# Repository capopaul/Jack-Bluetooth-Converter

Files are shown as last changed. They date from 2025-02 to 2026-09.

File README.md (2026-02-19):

# Jack <> Bluetooth Converter

Revision 3.1 (Not manufactured yet) :

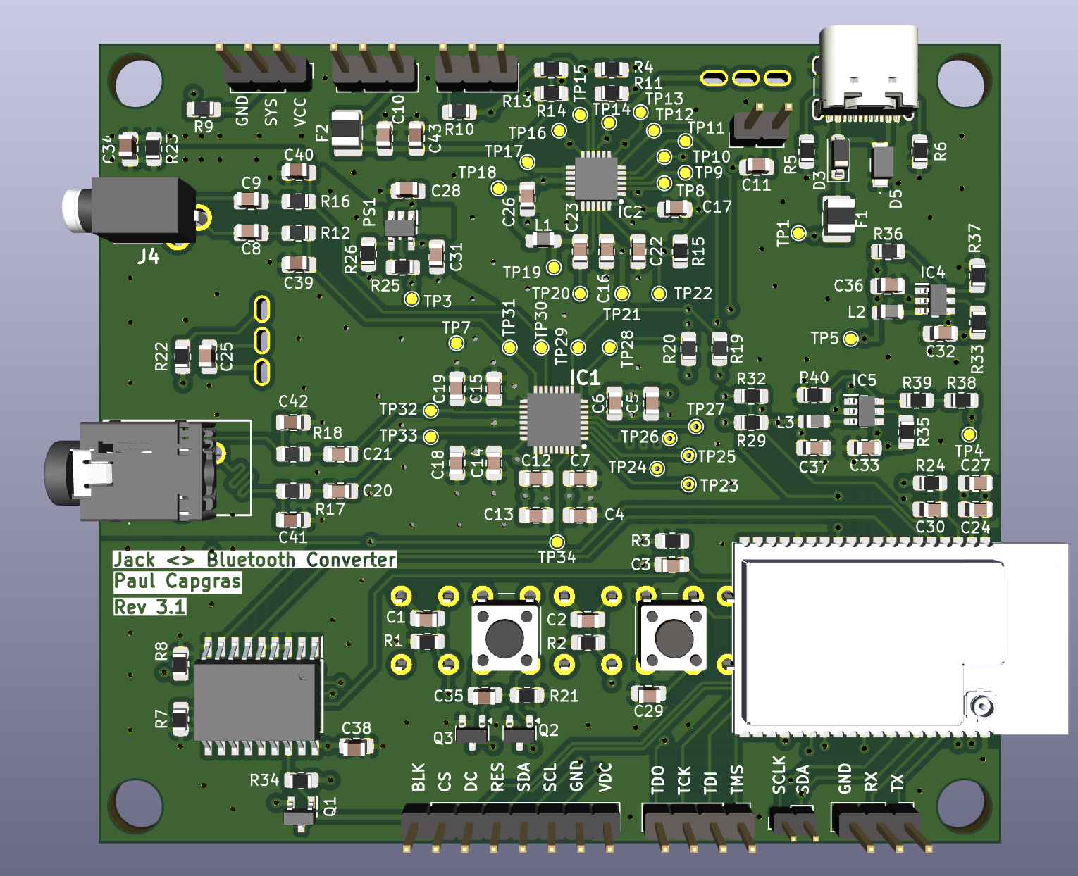
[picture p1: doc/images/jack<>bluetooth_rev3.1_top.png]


Revision 3.0 (Manufactured) :

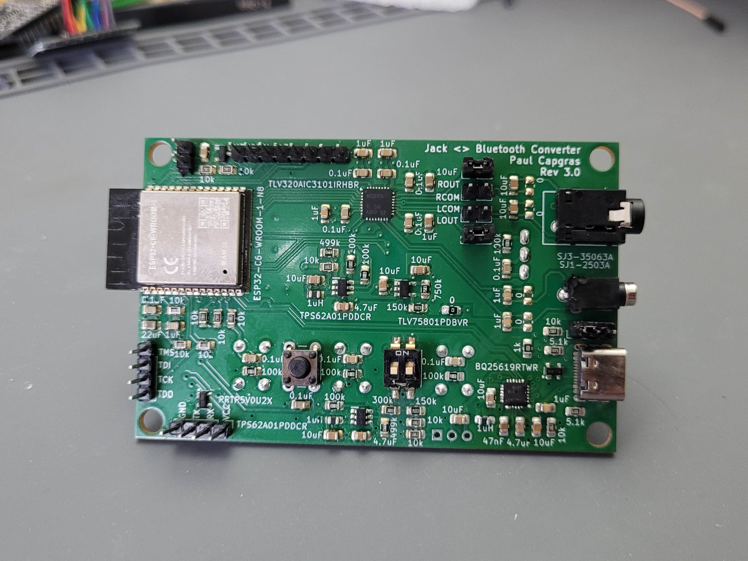
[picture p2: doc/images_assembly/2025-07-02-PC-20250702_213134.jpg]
image pcb


## Table of Content

1. [Features](#1-features)
2. [Design Specificatin and documentation](#2-design-specification-and-documentation)
3. [Repo organization](#3-repo-organization)
4. [Next steps](#4-next-steps)
5. [Revision history](#5-revisions-history)

## 1. Features

This project aims to design a device with the following features:

- Audio input from a 2.5mm audio jack can be sampled and transmitted via Bluetooth to a headphone.
- Digital audio from a smartphone can be received via Bluetooth and converted into analog audio through a 3.5mm audio jack.
- The device can be powered via USB-C or run on battery for up to 3 hours.
- The battery charges when the device is connected to USB-C.
- A screen and buttons allow switching between "Jack to Bluetooth" and "Bluetooth to Jack" modes.
- The screen and buttons enable Bluetooth peripheral selection when the device functions as a Bluetooth central.
- The screen turns off after 1 minute of inactivity to save power.

## 2. Design specification and documentation

Please go to [Jack <> Bluetooth Design Specification](doc/Jack<>Bluetooth-Design-Specification.md) which documents the design choices and provide details on the project.

[Software Readme](software/README.md) contains note taking from the software development (work in progress).

## 3. Repo organization

`./Components` -> components list with libs (not public)

`./doc` -> documentations, specifications and images

`./gerber` -> pcb design files for manufacturing

`./kicad` -> Kicad files

`./software` -> ESP32 C code (work in progress)

## 4. Next steps

- Working on a new revision : Rev3.1 to fix the current hardware limitations

## 5. Revisions history

Please go to [Jack<>Bluetooth-Revision-History](doc/Jack<>Bluetooth-Revision-History.md)

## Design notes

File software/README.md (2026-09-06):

<!-- Author : Paul Capgras -->
<!-- Date   : Jun 14, 2025 -->

# Software Readme

Command order:

- `get_idf`
- `idf.py set-target esp32`
- `idf.py build`
- `idf.py flash monitor`

Then refer to bringup:

## Bringup

- Connect GND
- Connect RX to **TX**
- Connect TX to **RX**

- Send the program through UART
  - thanks to the esp idf platform
  - run `get_idf`
  - esp32 should have been also selected
  - `idf.py build` to build
  - power up the board via usb-c
  - connect the UART device using an usb-c to usb cable.
  - check macos detect the device `ls /dev/cu.*`
  - Push SW 4 (left) down
  - flash the program `idf.py flash monitor`
  - You might need to push reset button (SW 6, right, close to the esp32)
  - to quit monitor terminal run CTRL-] on querty or CTRL+ALT GR+$ on azerty

> Ouput should be:

- 0x00 -> (ESP Master)
- 0x20 -> IO Expander
- 0x18 -> Audio Codec
- 0x6a -> PMIC

## Detect I2C peripherals

- use the i2c_tools from `/home/paul/esp/esp-idf/examples/peripherals/i2c`
- go to the clone directory and run the idf commands.
- i2c detect does not detect anything so far
- connect oled i2c screen for a debug purpose. I might need a breadboard to connect grounds.

## Embedded development

- VS code with esp-idf extension (from Espressif Systems) and C/C++ (from Microsoft).
- Some `#include`might me red, you need to add the esp path to the extension.
- This video explains it at 7min15 : <https://www.youtube.com/watch?v=5IuZ-E8Tmhg&t=5s>
- You can also use `CMD+SHIFT+P`, then click `ESP-IDF: Add VS Code Configuration Folder`.
- You will need to build the project with `idf.py build` and it should solve all the issues

## Development Notes

- [Former Development Notes of Rev3.0](./Development%20Notes%20of%20Rev3.0.md).

### Clocks

The is an issue on my PCB with i2s_mclk. It was supposed to be IO0 and it turns out to be TXD0...

So let's try not to use i2s_mclk and only i2s_bclk.

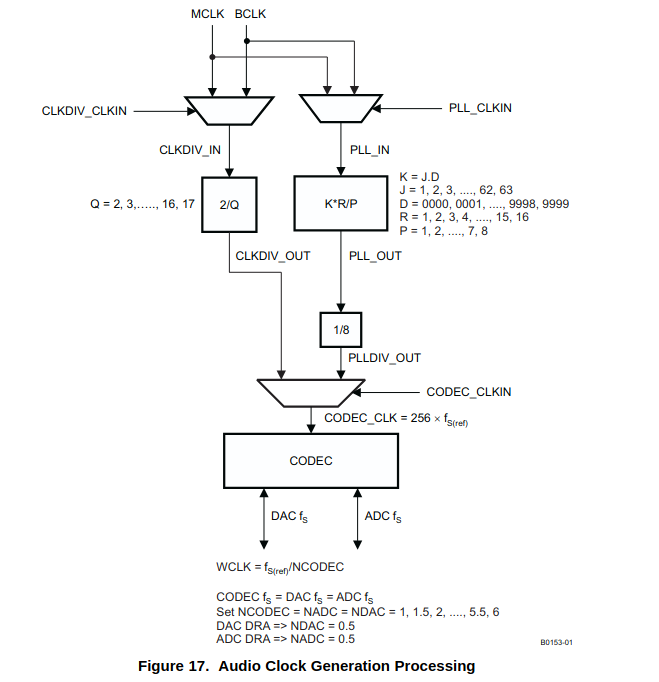
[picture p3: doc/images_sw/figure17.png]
audio codec clocks


The goal is to have : `CODEC_CLK = 256 x fs`.

- `fs = 44,100 Hz`
- So the goal is to have : `CODEC_CLK = 256 x fs = 11.2896 MHz`.
- Right now, `BCLK = 2.822 MHz` with 16 bit stereo but 32 bit slots.
- So in the clock path I choose to use the path on the right, using the audio codec internal PLL.
- `PLLDIV_OUT = BLCK x K x R / (8 x P) = BLCK x (J.D) x R / (8 x P)`
- **Warning** J is the integer portion of K (the numbers to the left of the decimal point), while D is the fractional portion of K.
- `P = 1, R = 1, D = 0, J = 32` should work
- `PLL_CLKIN` needs to be set
- `CODEC_CLKIN` needs to be set

### DAC

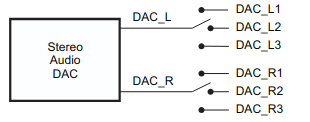
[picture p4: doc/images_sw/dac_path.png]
DAC_path

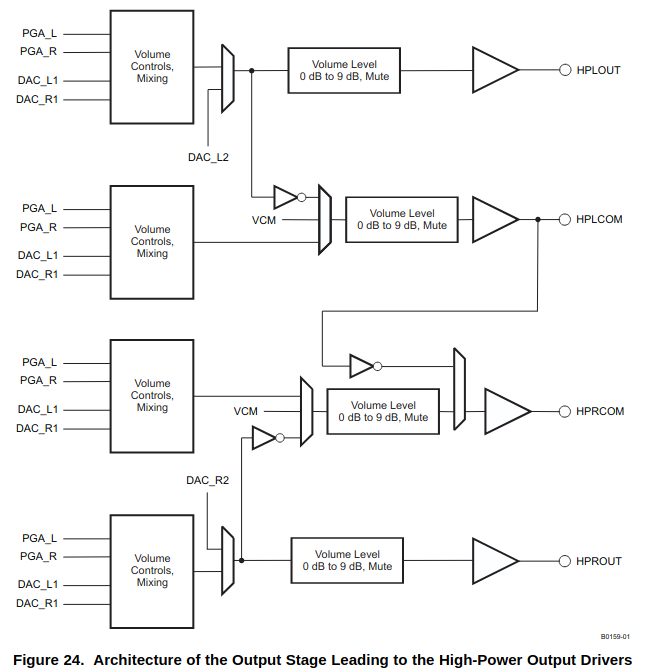
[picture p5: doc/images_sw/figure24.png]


Goal: I want my audio output on HPR/Lout:

- so according to this : I should put my audio on DAC_L2 and DAC_R2 - Register 41.
- Both DAC should be powered up - Register 37.
- Both DAC should be using fs = 44.1KHz and streaming L/R data - Register 7.
- HPLout should be powered up and unmuted - Register 51
- HPRout should be powered up and unmuted - Register 65

Crash when I send the audio. Honnestly without UART working (as it is used to trasnmit MCLK), it is really a mess to debug.

<!-- 
## Oct 12

I am choosing not to use MCLK from the ESP and to generate the clock internally in my audio codec with the internal PLL using the BCLK as a source.

### Clock

Let's configure the PLL.
![figure17](../doc/images_sw/figure17.png)

- CODEC_CLK (BCLK) = KxRxBCLK/(8xP) = 256 fs = KxRxfs/(8x8xP). Which implies that KxR/P = 64x256. So JxDxR/P = 64x256. Let's take P=1, R=2, J=32, D=256
- Enable PLL and set P in register 3
- Set J in register 4
- Set D in register 5 and 6
- Set R in register 11
- CODEC_CLKIN should select PLLDIV_OUT -> Register 101.
- PLLDIV_IN uses BCLK -> Register 102

```c
/*
  * Clock
  */

// Register 3 - PLL Programming Register A
// D7   - 1    - PLL is enabled
// D6-3 - 0000 -
// D2-0 - 001  - P= 1
i2c_set(CODEC_ADDR, 3, 0b10000001);
is_expected(3, i2c_get(CODEC_ADDR, 3), 0b10000001);

// Register 4 - PLL Programming Register B
// D7-2 - 100000 // Set J to 32
// D1-0 - 00
i2c_set(CODEC_ADDR, 4, 0b10000000);
is_expected(4, i2c_get(CODEC_ADDR, 4), 0b10000000);

// Register 5 and 6
// Set D to 100000000 (256)
// MSB D7-0 (reg 5) 00000100
// LSB D7-2 (reg 6) 000000
// D1-0             00
i2c_set(CODEC_ADDR, 5, 0b00000100);
i2c_set(CODEC_ADDR, 6, 0b00000000);
is_expected(5, i2c_get(CODEC_ADDR, 5), 0b00000100);
is_expected(6, i2c_get(CODEC_ADDR, 6), 0b00000000);

// Register 11 - Audio Codec Overflow Flag Register
// D7-4 0
// D3-0 0010 Set R to 0010
i2c_set(CODEC_ADDR, 11, 0b00000010);
is_expected(11, i2c_get(CODEC_ADDR, 11), 0b00000010);

// Register 102 - Clock Generation Control Register
// D7-6 - 0  -
// D5-4 - 10 - PLLCLK_IN uses BCLK
// D3-0 - 0010
// No need to write
i2c_set(CODEC_ADDR, 102, 0b00100010);
is_expected(102, i2c_get(CODEC_ADDR, 102), 0b00100010);

// Register 101 - Clock register
// D7-1 - 0
// D0   - 0 - CODEC_CLKIN uses PLLDIV_OUT
i2c_set(CODEC_ADDR, 101, 0b00000000);
is_expected(101, i2c_get(CODEC_ADDR, 101), 0b00000000);

```

Let's check if the audio is sent successfully through the i2s interface:

I do have my BCLK visible in the oscilloscope. Not the best clean clock I have seen... The frequency is fs(=44.1) * 256 / 8 = 1.41MHz so that is good. It is a free running clock.
![BLCK](../doc/images_sw/bclk_oscilloscope.png)

Ws is also free running.
![WS](../doc/images_sw/ws_oscilloscope.png)

The Dout is also good when sending an audio:
![Dout](../doc/images_sw/dout_oscilloscope.png)

-> Not working. Three possibilities the overshoot are problematic. And/Or the PLL is bad. And/Or the DAC is badly configured.

1. Let's have a faster BCLK with the ESP to enter spec recommendation in the example:

I add a slot of 32 bits instead of 16. This double my BCLK clock.
fs = 44.1kHz
So BCLK = fs*256/4 = 2.822MHz

PLLCLK_IN = 2.822MHz so we have 2MHz < PLLCLK_IN < 20MHz (that is the condition that was not respected before).

fS(ref) = (PLLCLK_IN × K × R)/(2048 × P)

fS(ref) = (256xfS(ref)/4 × K × R)/(2048 × P),

1 = (256 × K × R)/(4x2048 × P),

**P = 1**

KxR = 4x2048/256 = 32

K = J.D => **D=0**, **J = 32**

Other constraint:
80 MHz ≤ (PLLCLK _IN × K × R/P ) ≤ 110 MHz

**R=1**

80MHz < 90MHz < 110MHz - GOOD

Final contraint:

4 ≤ J=16 ≤ 55 - GOOD

``` c
// Register 3 - PLL Programming Register A
// D7   - 1    - PLL is enabled
// D6-3 - 0000 -
// D2-0 - 001  - P= 1
i2c_set(CODEC_ADDR, 3, 0b10000001);
is_expected(3, i2c_get(CODEC_ADDR, 3), 0b10000001);

// Register 4 - PLL Programming Register B
// D7-2 - 10000 // Set J to 32
// D1-0 - 00
i2c_set(CODEC_ADDR, 4, 0b01000000);
is_expected(4, i2c_get(CODEC_ADDR, 4), 0b01000000);

// Register 5 and 6
// Set D to 0
// MSB D7-0 (reg 5) 0
// LSB D7-2 (reg 6) 0
// D1-0             0
// always write both, and in the order reg5 then reg6.
is_expected(5, i2c_get(CODEC_ADDR, 5), 0b00000000);
is_expected(6, i2c_get(CODEC_ADDR, 6), 0b00000000);

// Register 11 - Audio Codec Overflow Flag Register
// D7-4 0
// D3-0 0010 Set R to 0001
i2c_set(CODEC_ADDR, 11, 0b00000010);
is_expected(11, i2c_get(CODEC_ADDR, 11), 0b00000010);

// Register 102 - Clock Generation Control Register
// D7-6 - 0  -
// D5-4 - 10 - PLLCLK_IN uses BCLK
// D3-0 - 0010
// No need to write
i2c_set(CODEC_ADDR, 102, 0b00100010);
is_expected(102, i2c_get(CODEC_ADDR, 102), 0b00100010);

// Register 101 - Clock register
// D7-1 - 0
// D0   - 0 - CODEC_CLKIN uses PLLDIV_OUT
i2c_set(CODEC_ADDR, 101, 0b00000000);
is_expected(101, i2c_get(CODEC_ADDR, 101), 0b00000000);
```

1. Let's filter this signals to have cleaner signals.

### DAC

I want my audio output on HPR/Lout:
![DAC_path](../doc/images_sw/dac_path.png)
![figure24](../doc/images_sw/figure24.png)

- so according to this : I should put my audio on DAC_L2 and DAC_R2 - Register 41.
- Both DAC should be powered up - Register 37.
- Both DAC should be using fs = 44.1KHz and streaming L/R data - Register 7.
- HPLout should be powered up and unmuted - Register 51
- HPRout should be powered up and unmuted - Register 65

Missing configuration:

- Unmute L-DAC - Register 43
- Unmute R-DAC - Register 44
 -->

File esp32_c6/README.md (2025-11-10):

# Jack <> Bluetooth Converter
Revision : 3.0



## Table of Content

1. [Features](#1-features)
2. [Design Specificatin](#2-design-specification)
3. [Repo organization](#3-repo-organization)
4. [Next steps](#4-next-steps)

## 1. Features

This project aims to design a device with the following features:

- Audio input from a 2.5mm audio jack can be sampled and transmitted via Bluetooth to a headphone.
- Digital audio from a smartphone can be received via Bluetooth and converted into analog audio through a 3.5mm audio jack.
- The device can be powered via USB-C or run on battery for up to 3 hours.
- The battery charges when the device is connected to USB-C.
- A screen and buttons allow switching between "Jack to Bluetooth" and "Bluetooth to Jack" modes.
- The screen and buttons enable Bluetooth peripheral selection when the device functions as a Bluetooth central.
- The screen turns off after 1 minute of inactivity to save power.

## 2. Design specification and documentation

Please go to [Jack <> Bluetooth Design Specification](doc/Jack<>Bluetooth-Design-Specification.md) which documents the design choices and provide details on the project.

## 3. Repo organization

`./Components` -> components list with libs (not public yet because of kicad lib licences)

`./doc` -> documentations, specifications and images

`./gerber` -> pcb design files for manufacturing

`./kicad` (not public yet because of kicad lib licences)

`./software` -> ESP32 C code (work in progress)

## 4. Next steps

- PCB review & manufacturing
- finish box design & 3D printing
- Software

## 5. Revisions history

Please go to [Jack<>Bluetooth-Revision-History](doc/Jack<>Bluetooth-Revision-History.md)

## 6. SW Readme

<!-- Author : Paul Capgras -->
<!-- Date   : Jun 14, 2025 -->
Command order:

- `get_idf`
- `idf.py set-target esp32c6`
- `idf.py build`
- `idf.py flash monitor`

Then refer to bringup:

## Bringup

### Boot ESP32-C6 - From UART

- Connect 3.3V UART to 3.3V Pin (temporary)
- Connect GND
- Connect RX to **RX**
- Connect TX to **TX**

- Put 1 of OFF
- Put 2 to ON
- Send the program through UART
    - thanks to the esp idf platform
    - run `get_idf`
    - esp32-c6 should have been also selected
    - `idf.py build` to build
    - `idf.py flash monitor`
    - You might need to push reset button
    - to quit monitor terminal run CTRL-] on querty or CTRL+ALT GR+$ on azerty
- Put 2 to OFF
- Push reset button

- `i2cdetect`
> Ouput should be:
  - 00 -> (ESP Master)
  - 18 -> PMIC
  - 6a -> Audio Codec

### Good practice learnt:

- put a pin for all power lines
- put an arrow for directive lines in the silkscreen
- don't forget direction for the silkscreen for diodes (and leds !)

### Detect I2C peripherals

- use the i2c_tools from `/home/paul/esp/esp-idf/examples/peripherals/i2c`
- go to the clone directory and run the idf commands.
- i2c detect does not detect anything so far
- connect oled i2c screen for a debug purpose. I might need a breadboard to connect grounds. 

### Embedded development

- VS code with esp-idf extension (from Espressif Systems) and C/C++ (from Microsoft).
- Some `#include`might me red, you need to add the esp path to the extension.
- This video explains it at 7min15 : https://www.youtube.com/watch?v=5IuZ-E8Tmhg&t=5s

i2cconfig --port=0 --freq=100000 --sda=6 --scl=7

## Jun 27

- Je tente de remettre 5V sur Vcc et j'observe Vsystem
- Vcc est connecté à mon PMIC donc c'est normal que rien ne se passe sur Vsystem vu que le PMIC est dead.

- Je mets 3.323V sur Vsystem et j'observe:
    - 3.3VA : mesure : 3.321V
    - 1.8VDD: mesure : 1.823V
    - 3.3VDD: mesure : 3.317V

Là ma carte est correctement alimentée. Je peux mener l'enquête

---

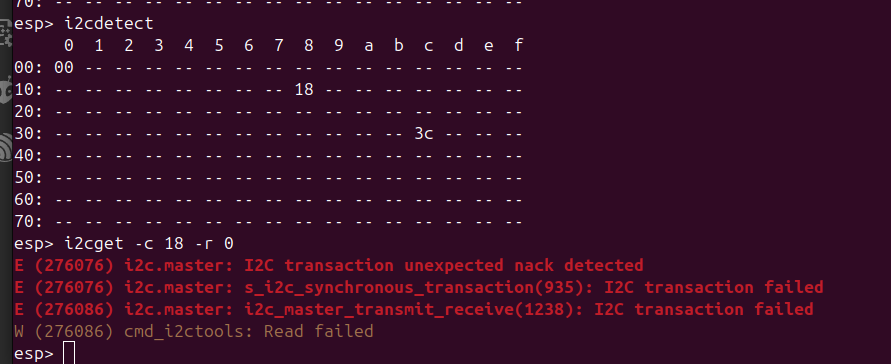
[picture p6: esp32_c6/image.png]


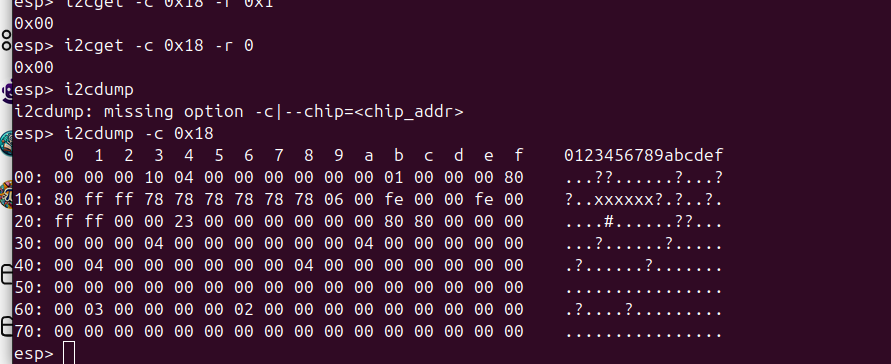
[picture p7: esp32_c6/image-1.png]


La solution c'est de mettre les valeurs en hexa 0x...

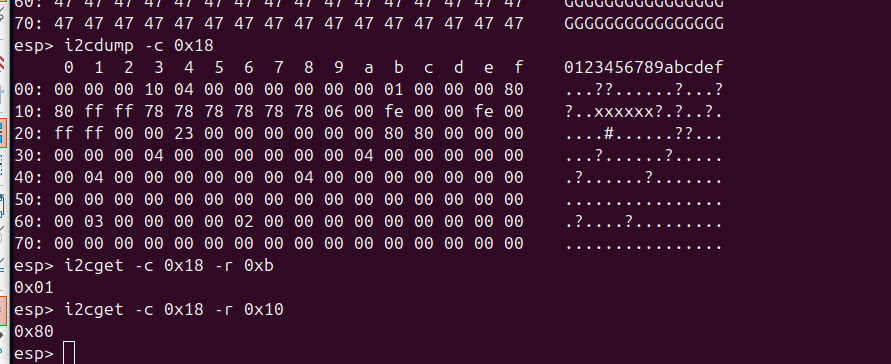
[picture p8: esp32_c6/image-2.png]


---

## Sept 17

### Bringup from USB-C
- Connect USB-C cable
- Send the program
- PB: interaction mode is not working

So go to normal bringup
[Refer to bringup](#bringup)

## Sept 18th

- Copied esp32/a2dp_sink.
- Run it with internal DAC.
- Access with my phone to the device ESP_speaker
- Signal was visible on the oscilloscope!
- Commit is called feat: setup classic bt audio_sink on the esp32 using internal DAC.

Next step use the audio codec. For that, I need to
- configure the audio codec using the esp32-c6.
- send the signal using the other esp.

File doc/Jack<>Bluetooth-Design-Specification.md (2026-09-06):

# Jack <> Bluetooth Design Specification/Details

| Revision | Date | Author | Comment |
| --- | --- | --- | ---|
| v3.0 | 2026 Feb 12 | Paul Capgras | Board rev 3.0 |
| v3.1 | 2026 Feb 17 | Paul Capgras | Board rev 3.1 |

## Purpose

The purpose of the *Jack <> Bluetooth Design Specification* is to document the design choices and provide details on this project.

## Table of Content

1. [Jack2Bluetooth features](#1-jack2bluetooth-features)
2. [Architecture](#2-architecture)
    1. [Jack to bluetooth](#21-jack-to-bluetooth)
    2. [Bluetooth to jack](#22-bluetooth-to-jack)
    3. [Overall Architecture](#23-overall-architecture)
    4. [User interface](#24-user-interface)
3. [Component choices](#3-component-choices)
    1. [MCU](#31-mcu--microcontroller-unit)
    2. [Audio codec](#32-audio-codec)
    3. [Battery](#33-battery)
        1. [ESP32-C6 curruent consumption](#331-esp32-c6-current-consumption)
        2. [TLV320AIC3101 current consumption](#332-tlv320aic3101-current-consumption)
        3. [Current consumption conclusions](#333-current-consumption-conclusions)
    4. [PMIC](#34-pmic--power-management-integrated-circuit)
    5. [LDO](#35-ldo--low-dropout-voltage-regulator)
    6. [Switch Regulator](#36-switching-voltage-regulator-switch)
4. [Electronic schematic](#4-electronic-schematic)
    1. [Jack 3.5mm](#41-jack-35mm)
    2. [Jack 2.5mm](#42-jack-25mm)
    3. [Audio Codec](#43-audio-codec-tlv320aic3101)
    4. [MCU](#44-mcu)
        1. [Revision 3.0: ESP32-C6-WROOM-1](#441-revision-30-esp32-c6-wroom-1)
        2. [Revision 3.1: ESP32-WROVER-E](#442-revision-31-esp32-wrover-e)
    5. [PMIC](#45-pmic-bq25619rtwr)
    6. [LDO](#46-ldo-tlv758p)
    7. [Switch regulator](#47-switch-regulators-tps62a01pddcr)
    8. [Screen](#48-screen)
    9. [USB-C & UART connectors](#49-usb-c--uart-connectors)
    10. [Control Buttons](#410-control-buttons)
    11. [IOs expander](#411-ios-expander)
5. [GPIOs pin assignments](#5-gpios-pin-assignments)
    1. [MCU pin assignments](#51-mcu-pin-assignments)
    2. [Pin expander](#52-pin-expander)
6. [I2C Addresses](#6-i2c-addresses)
7. [Layout](#7-layout)
    1. [Main ideas](#71-layout-main-ideas)
    2. [Impedance matching](#72-impedance-matching)
    3. [Trace length](#73-trace-length)
    4. [Update footprints](#74-update-footprints)
    5. [Layers](#75-layers)

## 1. Jack2Bluetooth features

This project aims to design a device with the following features:

- Audio input from a 2.5mm audio jack can be sampled and transmitted via Bluetooth to a headphone.
- Digital audio from a smartphone can be received via Bluetooth and converted into analog audio through a 3.5mm audio jack.
- The device can be powered via USB-C or run on battery for up to 3 hours.
- The battery charges when the device is connected to USB-C.
- A screen and buttons allow switching between "Jack to Bluetooth" and "Bluetooth to Jack" modes.
- The screen and buttons enable Bluetooth peripheral selection when the device functions as a Bluetooth central.
- The screen turns off after 1 minute of inactivity to save power.

## 2. Architecture

### 2.1 Jack to Bluetooth

For audio sampling:

The audio codec must support line-level audio input signals. The ADC is integrated into the audio codec with an amplifier.

### 2.2 Bluetooth to Jack


The audio codec must include a DAC with an amplifier.

### 2.3 Overall architecture

When merging the two previous architecture, it becomes:
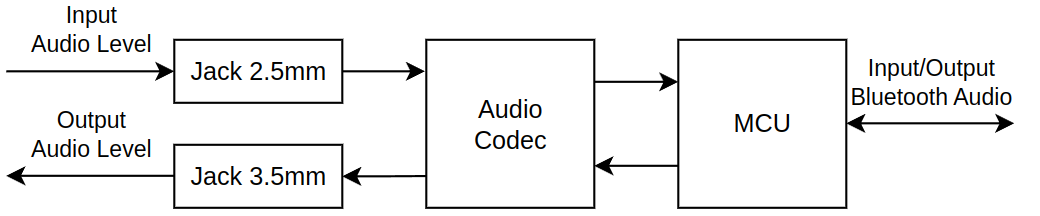
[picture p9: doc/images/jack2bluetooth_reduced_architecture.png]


And when adding power components and the user interface components, the overall architecture is :

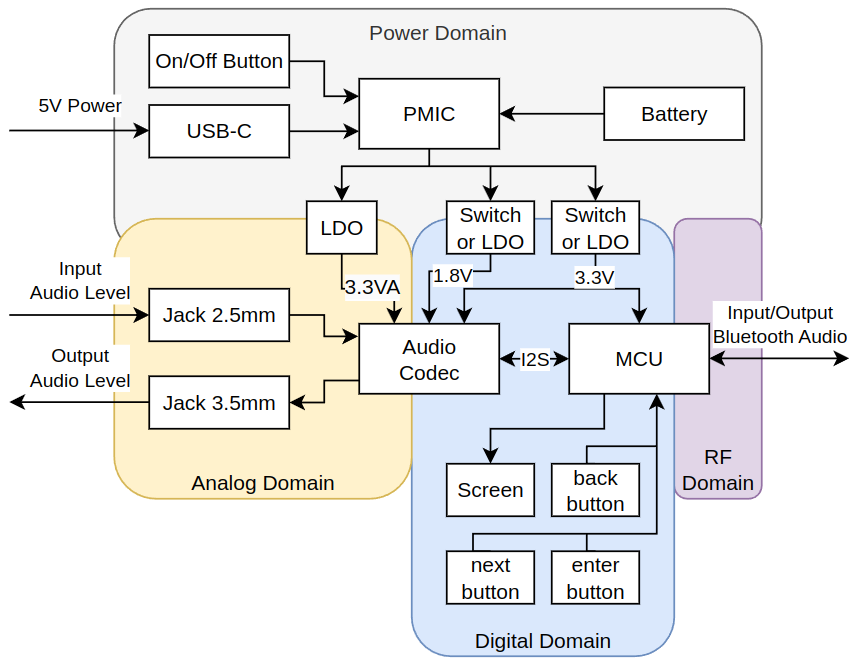
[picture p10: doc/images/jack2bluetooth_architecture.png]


### 2.4 User Interface

Based on the architecture, the user interface is then:

|User interface | Direction |
| --- | --- |
| Button Next | Input |
| Button Enter | Input |
| Button Back | Input |
| Button On/Off | Input |
| Audio Jack 2.5mm | Input |
| Usb-C | Input |
| Bluetooth | Input & Output |
| Screen | Output |
| Audio Jack 3.5mm | Output |

## 3. Component choices

### 3.1 MCU : Microcontroller Unit

The ESP32 was chosen due to its widespread availability and ease of use. To simplify RF design, an ESP32 module with an integrated antenna was selected.

Requirements:

- Bluetooth Classic support with protocol A2DP
- Integrated antenna
- USB, I2S, I2C, SPI inerfaces
- Core frequency (not the max supported but the integrated clock frequency)
- Memory size

Revision 3.1:
First choice made in Rev3.0 was ESP32-C6-WROOM-N8.
This was a bad choice because ESP32-C6 only supports Bluetooth Classic Low Energy and not Bluetooth classic.

New choice should be default ESP32. It should be a module to have clock and antenna integrated.

List of modules considered:

- ESP32-WROVER-E
- ESP32-WROOM-32E

Both have the same soc. However, ESP32-WROVER-E has an additional memory PSRAM memory because its module is bigger than ESP32-WROOM-32E.

The version with the bigger flash (16MB) and PSRAM (8MB) is selected.

Decision is made to use **ESP32-WROVER-E-N16R8**.

Usefull links:

- [ESP HW Design guidelines](https://docs.espressif.com/projects/esp-hardware-design-guidelines/en/latest/esp32/index.html).
- <https://docs.espressif.com/projects/esp-adf/en/latest/design-guide/dev-boards/board-esp32-lyrat-v4.3.html>

### 3.2 Audio Codec

Requirements:

- DAC 24kHz, 48kHz, 96kHz - Input is I2S - Output is single-ended headphone amplifier (16-32 Ohms load).
- ADC 24kHz, 48kHz, 96kHz - Input is single-ended, line-level audio - Output is I2S.

Final choice : **TLV320AIC3101** (Texas Instrument).

Revision 3.1: efforts where made to consider other devices to avoid QFN packages. However, all the other packages seen were classified as outdated by the manufacturer or were missing important features. So, decision was made to stay with the TLV320AIC3101.

### 3.3 Battery

The battery should provide at least 3 hours of operation.
The most power-intensive components are the MCU, audio codec, and the screen.

The screen is going to be on only when a user push a button (and stays on for ~30s). Therefore, it should be off in idle mode, in transmitting mode or receiving mode. Since the screen is mostly off, its consumption is negligible.

Revision 3.1: The battery connector has been updated to avoid soldering.

#### 3.3.1 ESP32-C6 Current consumption

According to the esp32-c6 datasheet, the Bluetooth LE current consumption are:
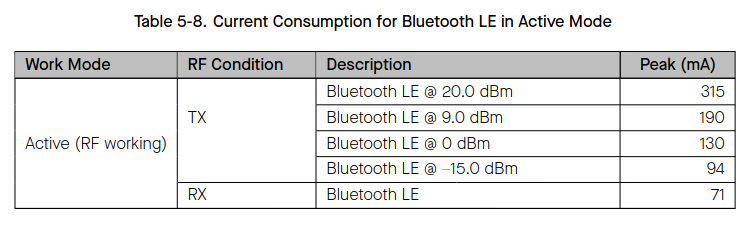
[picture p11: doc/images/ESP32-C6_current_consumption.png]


#### 3.3.2 TLV320AIC3101 Current consumption

According to its datasheet, it current consumptions are :
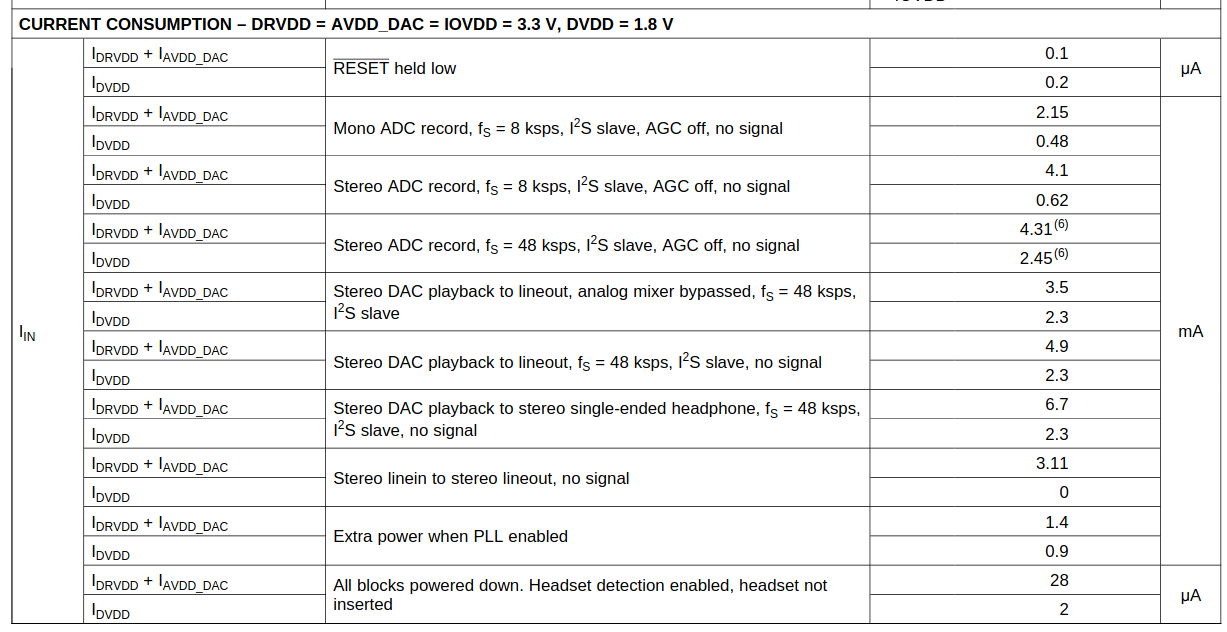
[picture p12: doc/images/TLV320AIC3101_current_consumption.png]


So it is negligeable compared to the ESP32-C6 Bluetooth LE transmission currents.

#### 3.3.3 Current consumption conclusions

The critical use case for current consumption is during audio sampling and Bluetooth transmission. Assuming the transmission is done at 9dBm, the required battery to power the device 3 hours is around 600mA.

#### 3.3.4 Revision 3.1

- Battery Capacity: 1200mAh（Real 1200mAh）
- Battery Voltage:3.7V  
- Battery Model: 103040
- Battery Size: 10x30x40mm
- Charging voltage:4.2V
- Cut-off voltage:2.75V
- Charging and discharging current:4A-8A
- Cycle life:1000 times
- Safety protection:charging,over-discharging,over-current,Protection
- Connector: PH2.0 plug

Add a 100uF capacitor to the battery to avoid shutdown.

### 3.4 PMIC : Power Management Integrated Circuit

The PMIC should support power path between the USB-C and the battery, battery charging when USB-C is plugged, battery discharging when unplugged.
Since a power on/off system is needed, if this IC could have sleep or deep sleep mode with very low current consumption, it could be nice.

Final choice : **BQ25619RTWR** (Texas Instrument).

All the elements are providing in the first page of product specification:
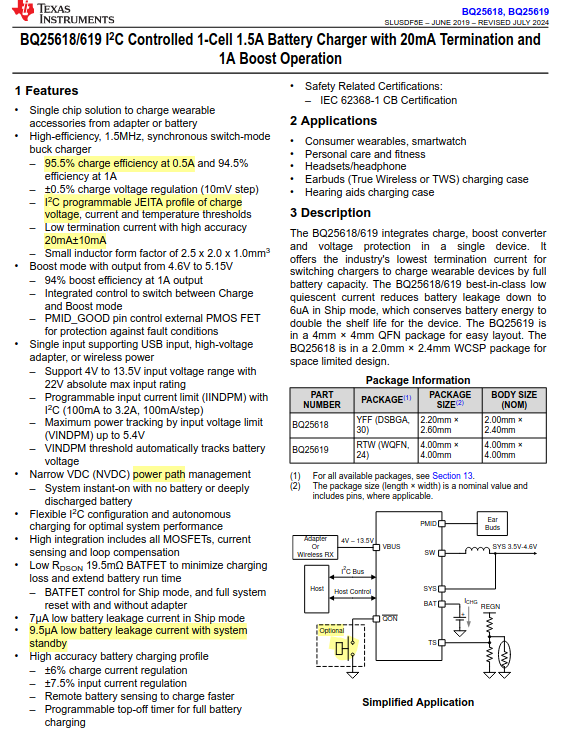
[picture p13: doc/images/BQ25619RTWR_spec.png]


### 3.5 LDO : Low-dropout voltage regulator

It was decided to use an LDO for the analog to have a clean alimentation. LDO should not be fixed to be able to reuse it in other designs.

Choice was made to use **TLV758P** from Texas Instrument.

### 3.6 Switching Voltage Regulator switch

Choice was made to use the **TPS62A01PDDCR** from Texas Instrument.

## 4. Electronic schematic

### 4.1 Jack 3.5mm

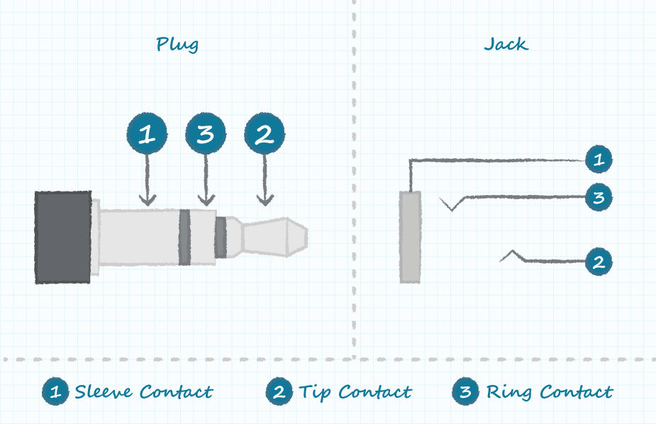
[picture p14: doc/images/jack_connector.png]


And the ASJ datasheet gives:

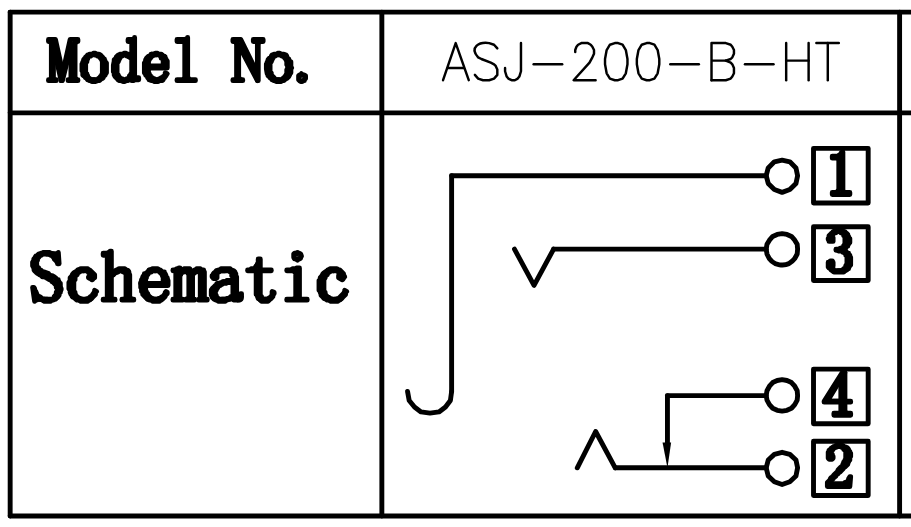
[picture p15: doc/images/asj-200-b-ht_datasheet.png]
asj-200-b-ht_datasheet


1. Sleeve is GND
2. Tip is Left
3. Ring is Right

So the schematic on kicad is:

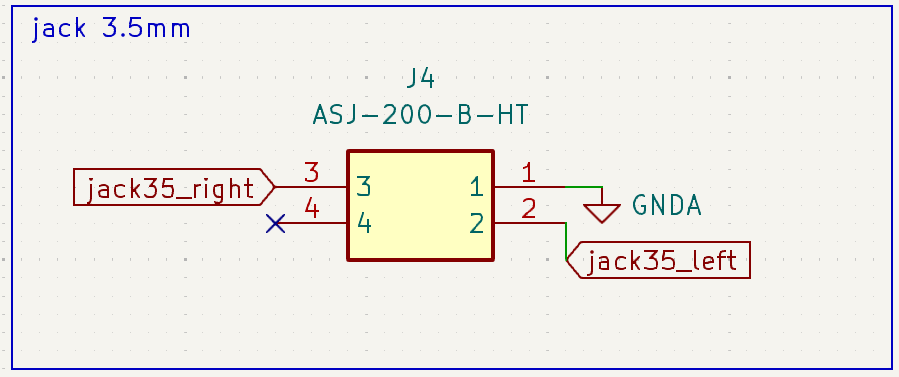
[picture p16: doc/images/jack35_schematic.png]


### 4.2 Jack 2.5mm

The schematic is
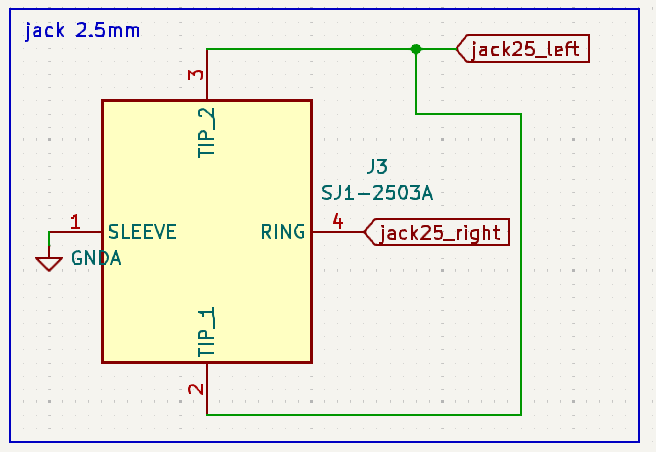
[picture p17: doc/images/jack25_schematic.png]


### 4.3 Audio Codec (TLV320AIC3101)

The typical application from the spec is:

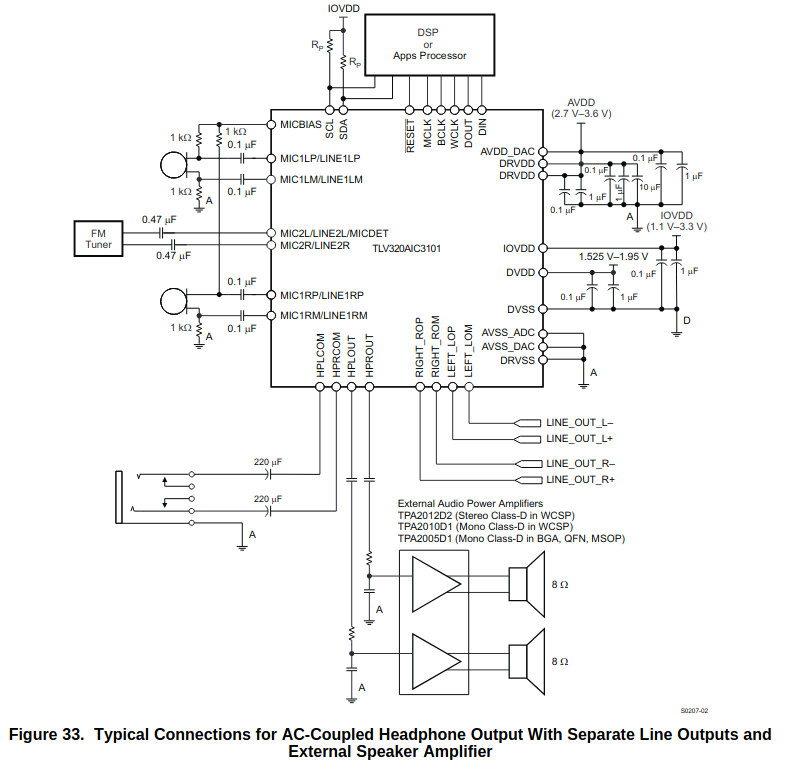
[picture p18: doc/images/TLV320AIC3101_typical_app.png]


It is also worth looking at the development board:

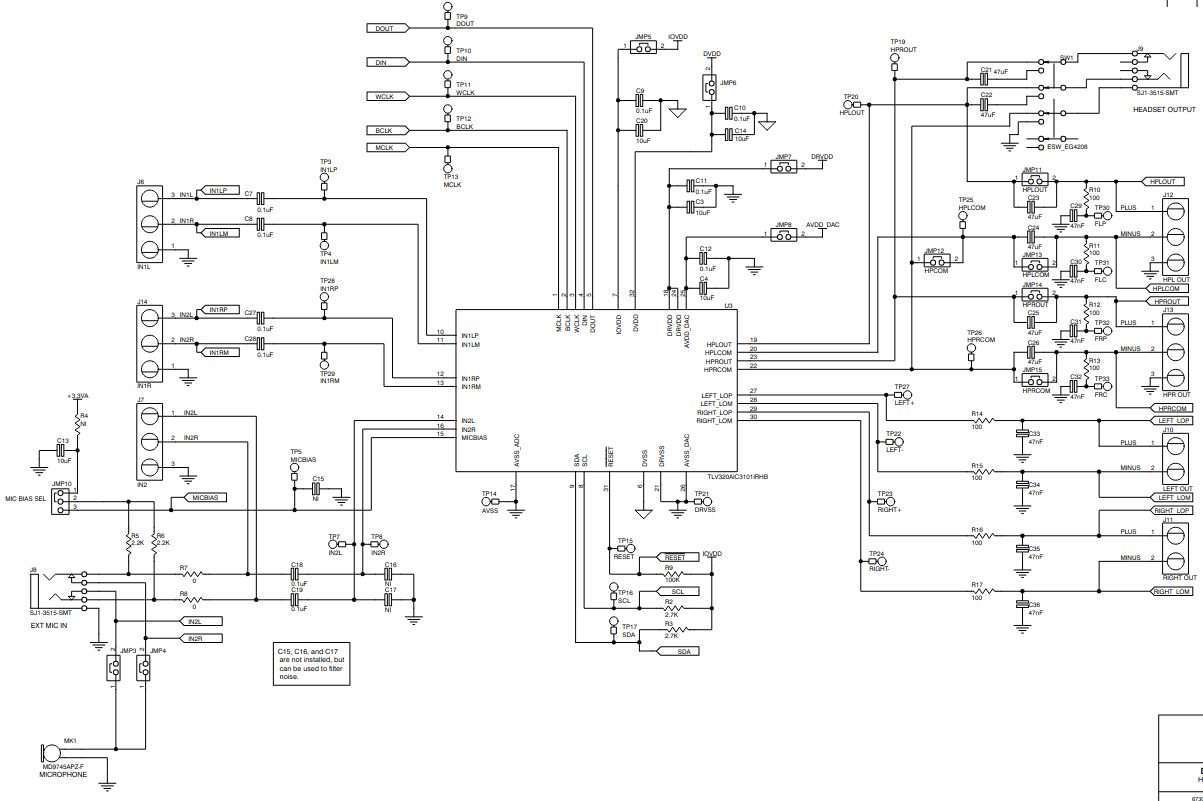
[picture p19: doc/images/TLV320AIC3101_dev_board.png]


The schematic done is then:

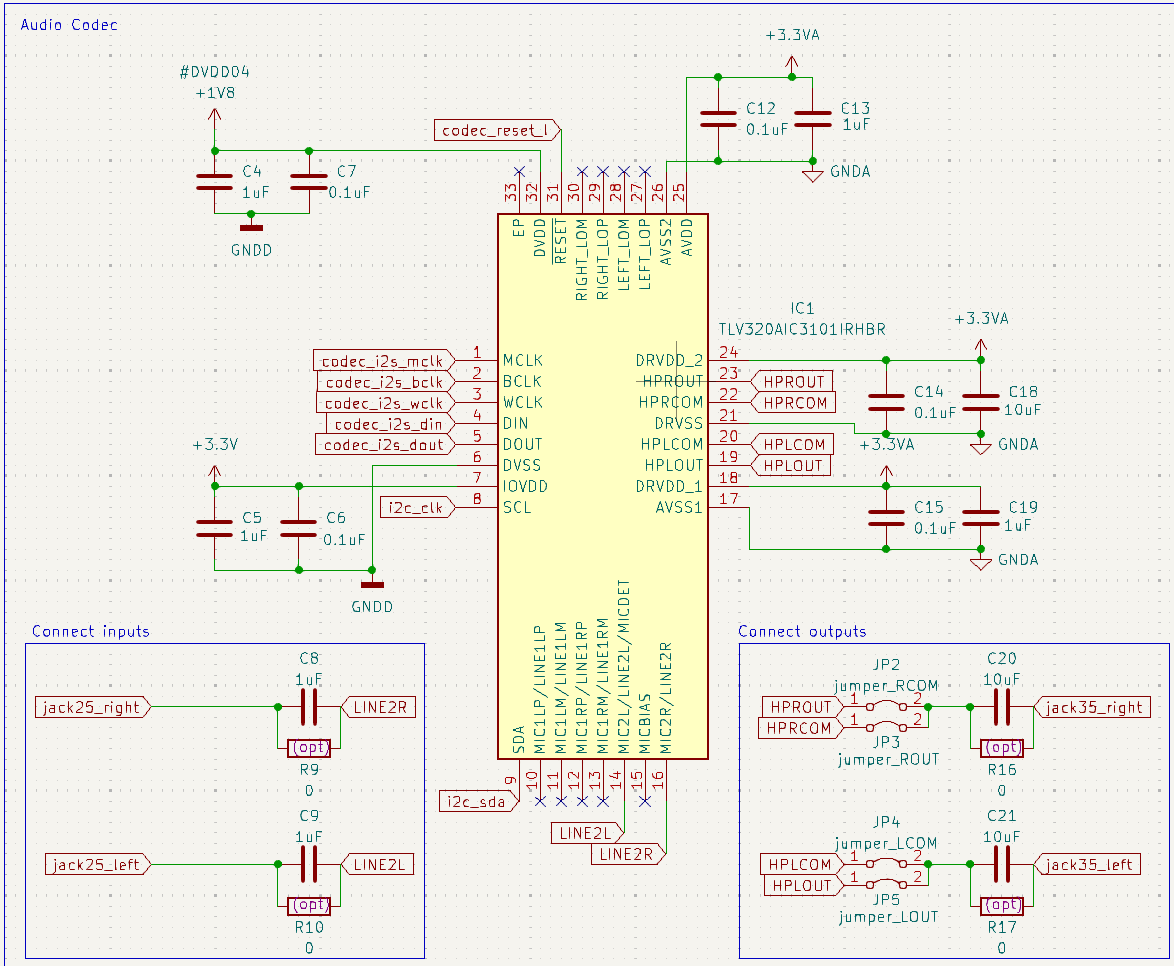
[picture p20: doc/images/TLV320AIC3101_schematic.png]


4 capacitors are to be determined, C8, C9, C20, C21.

First, C8=C9 and C20=C21.

Then, C8 and Rinput_of_line2R is a high pass filter, where fc = 1/(2*pi*C*R).

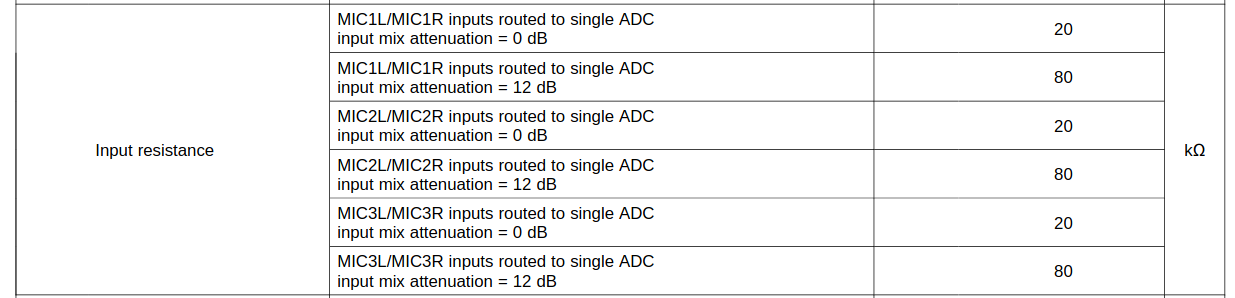
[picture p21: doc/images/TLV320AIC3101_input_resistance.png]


From TLV320AIC3101 datasheet, Rinput_of_line2R
is between 20kΩ and 80kΩ depending on the attenuation programmed in the audio codec.

The audio bandwidth is 20-20kHz. A capacitor of 1uF gives fc = 8Hz for R=20kΩ and fc= 2Hz for R=80kΩ which should be good for this application. So C8=C9=1uF.

Under the hyptohesis that the load resistance on the jack 3.5mm is 10kΩ (same hypothesis as in the TLV320AIC3101 datasheet), C20 and Rload are doing an high pass filter. A 10uF capacitor ensures that for Rload > 800Ω, the audio bandwidth is respected. So C20=C21=10uF.

Revision 3.1 adds the possibility to change the filtering later.

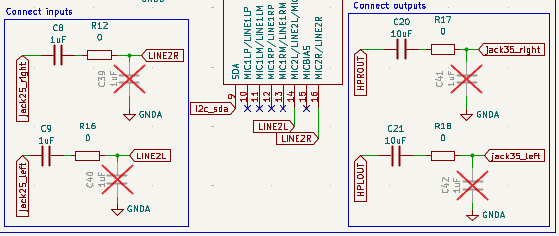
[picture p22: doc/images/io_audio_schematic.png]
IO audio schematic filtering


### 4.4 MCU

#### 4.4.1 Revision 3.0 (ESP32-C6-WROOM-1)

The datasheet of the ESP32-C6-WROOM-1 recommend the following schematic:

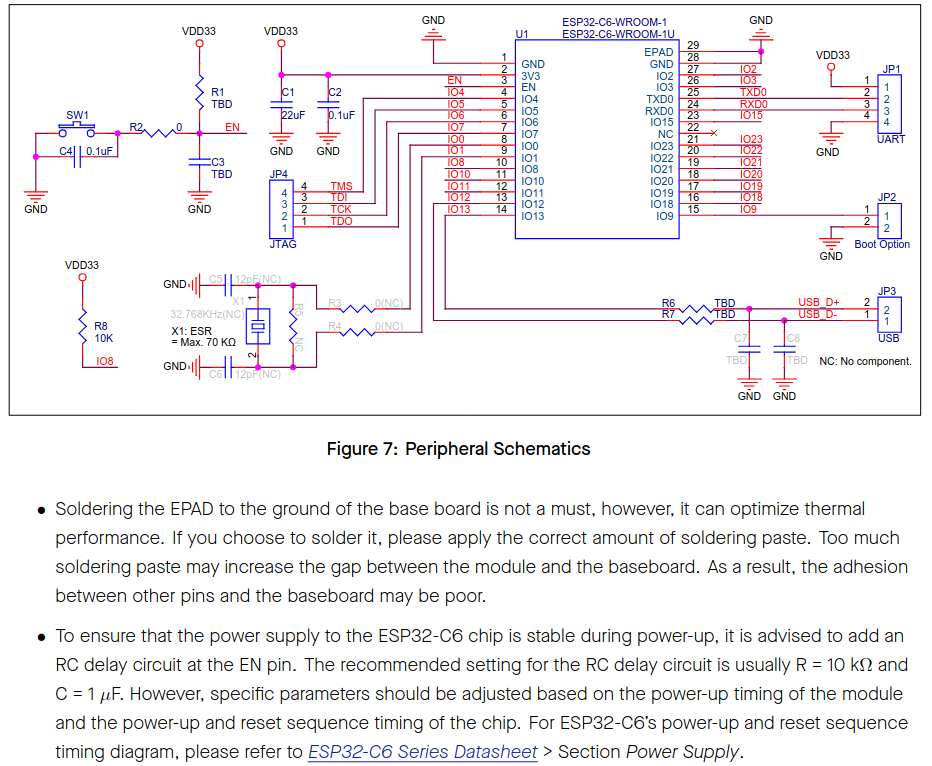
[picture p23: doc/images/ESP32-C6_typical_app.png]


A good resource is also the [ESP32-C6-DevKitC-1 v1.4](https://docs.espressif.com/projects/esp-dev-kits/en/latest/esp32c6/esp32-c6-devkitc-1/index.html)

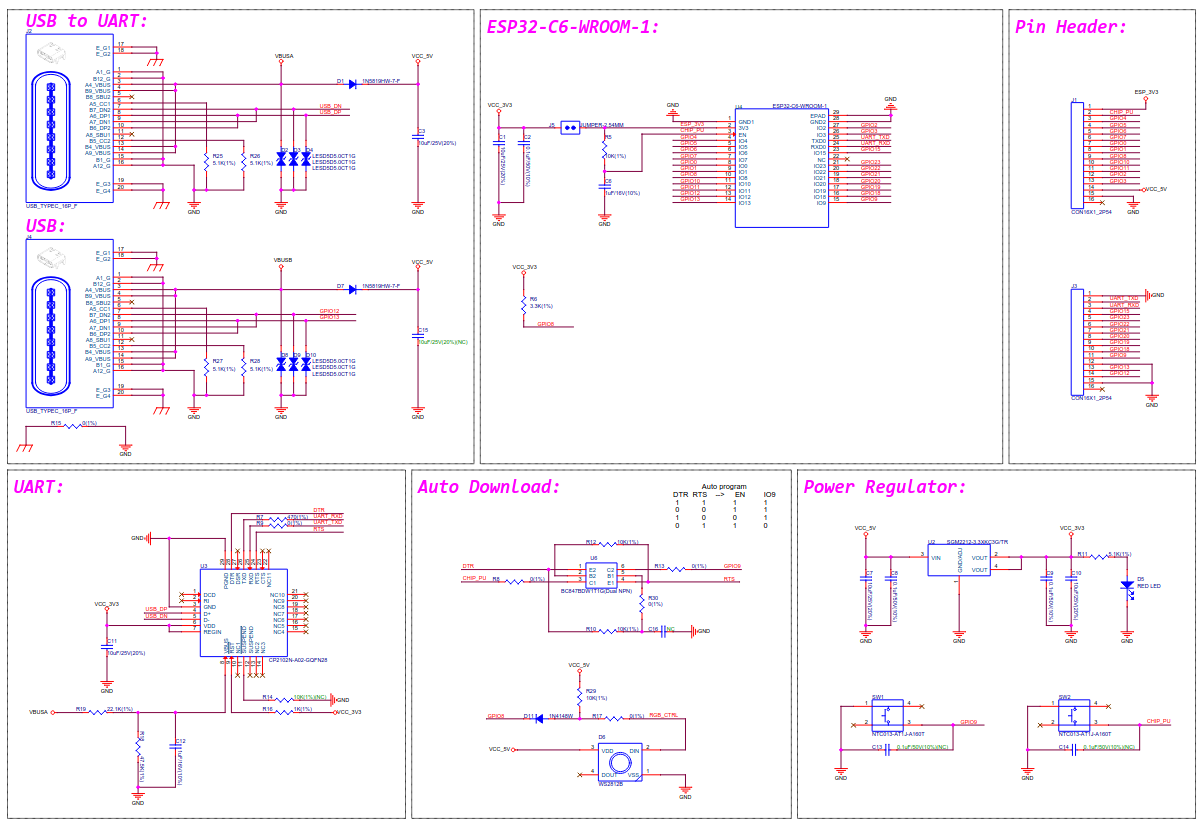
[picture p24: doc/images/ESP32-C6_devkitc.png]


Based on this two schematics, the schematic done is:

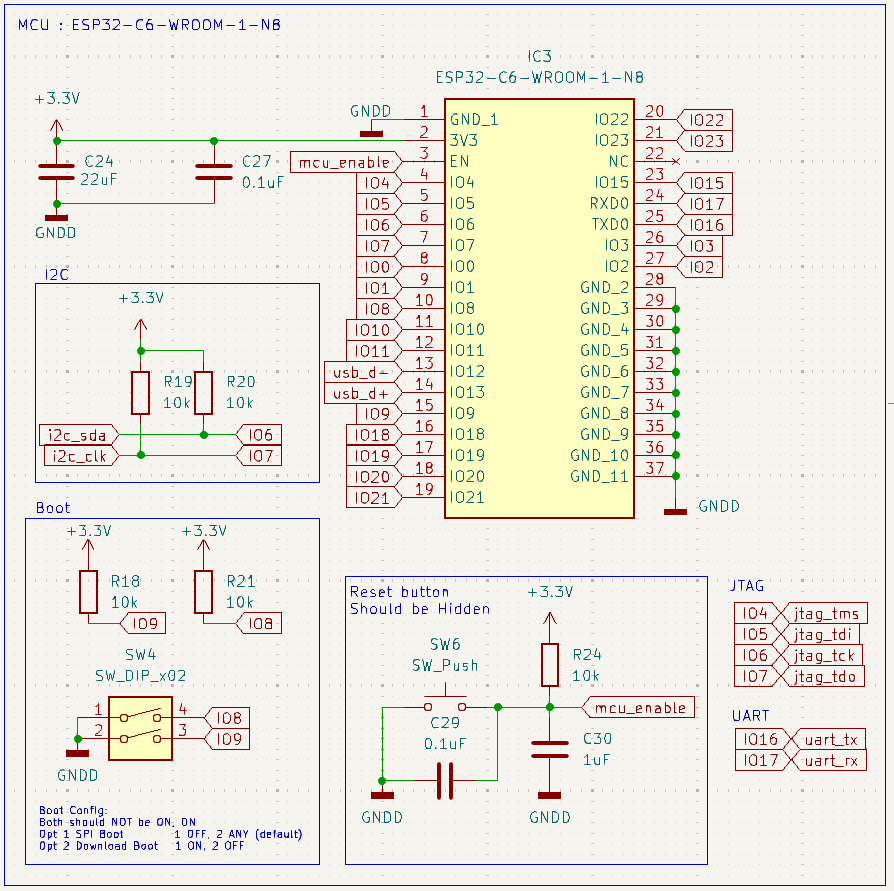
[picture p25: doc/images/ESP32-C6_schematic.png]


To boot the option are based on table 7 from the ESP32-C6-WROOM-1 datasheet:
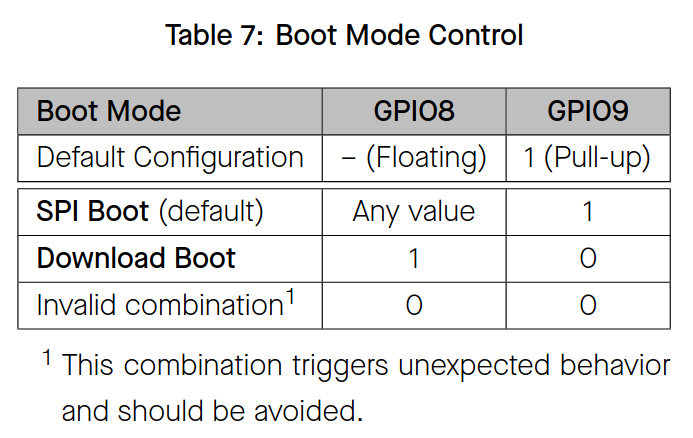
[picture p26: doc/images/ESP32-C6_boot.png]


#### 4.4.2 Revision 3.1 ESP32-WROVER-E

The Reset/Download button behavior is taken from the ESP32-Lyrat-v4.3 schematic:

ESP32 boot button

Based, on this the following schematic is built:

ESP32-WROVER-E schematic

### 4.5 PMIC (BQ25619RTWR)

The typical application from the BQ25619RTWR datasheet is:



The [BQ25619 evaluation module (EVM)](https://www.ti.com/tool/BQ25619EVM) is also a good reference:

BQ25619_evm

Based on that, the schematic done is :
BQ25619_schematic

In this case, since the device is powered by USB-C, PSEL should be connected to HIGH with REGN value. This decision is based on the BQ25619_evm schematic.

PMID_GOOD is connected to REGN through a 10k resistor as described in the pin configuration section of the datasheet.

PMID is connected to a 10uF capacitor following the datasheet typical application.

QON does not need to be pulled high and can stay floating when button not pushed.

Two resistors R28 and R29 need to be determined following section `7.3.6.4.1 JEITA Guideline Compliance During Charging Mode` of the datasheet. Since the default battery used for this project does not have temperature sensor, these resistors are equals to 10k as described in the pin configuration section of the datasheet.

### 4.6 LDO (TLV758P)

The typical application is:
TLV758P_typical_app

The target analog voltage is 3.3V.

R1/R2 = Vout/Vfb - 1 = 5

R1 + R2 <= Vout/(1e-6) = 3.3MΩ

Decision was to have R1 = 750kΩ and R2 = 150kΩ.
Therefore, the schematic is:
TLV758P_schematic

### 4.7 Switch Regulators (TPS62A01PDDCR)

The typical application is :
TPS62A01PDDCR_typical_application

Two regulators are required to create 1.8V and 3.3V. A voltage divider is built with R1 and R2 to fix the output voltage.

The first one can follow the same design as the typical application since it was already designed for Vout = 1.8V.

The second one needs to be designed for Vout = 3.3V. The section `8.2.2.1 Setting the Output Voltage` of the datasheet gives R2 <= 100kΩ and R1 = R2(Vout/0.6 - 1) = 4.5*R2

Choice is made to take R1 = 100kΩ, and R2 made with two resistors R2 = 300k + 150k



### 4.8 Screen

The screen is going to be connected through an SPI interface. It will be powered thanks to the 3.3 voltage. However to be able to power off the screen, an electronic circuit is required.

Screen_schematic

Revision 3.1: Decision is made to keep an external SPI interface as most screen provide this setup. It should be make debug easier.

### 4.9 USB-C & UART Connectors

The schematic done is based on the devkit of the ESP32.



### 4.10 Control Buttons

control_buttons_schematic

Revision 3.1: An IOs expander is added to avoid taking all the pins of the MCU.
The buttons and leds are therefore connected to this expander.

### 4.11 IOs Expander

IOs expander should:

- provide i2c interface for mcu.
- control at least 8 GPIOs
- support irq
- be available in an easy soldering package

Chip MCP23008 is selected because is do the job and it is available in DIP and SSOP packages!

Pins A0, A1, A2 are used to set the package address for the I2C bus.
So the address is: 0x2A_value.
Here A0 are all set to GND. So final address is 0x20

Final diagram is :
IOs expander

## 5. GPIOs Pin Assignments

### 5.1 MCU Pin Assignments

This table contains all the pin assignments. It was updated during layout to make rooting easier.

|IO° |Type | Active Mode | Debug/Bringup |
|---|-----|---|---|
| IO0 | I/O | codec_i2s_mclk | booting. |
| IO1 TXD0 | I/O | | uart_tx_boot  |
| IO2 | I/O | codec_i2s_bclk | booting |
| IO3 RXD0 | I/O | | uart_rx_boot  |
| IO4 | I/O | codec_i2s_din | |
| IO5 | I/O | codec_i2s_wclk | |
| IO12 | I/O | | jtag_tdi |
| IO13 | I/O | | jtag_tck |
| IO14 | I/O | | jtag_tms |
| IO15 | I/O | | jtag_tdo |
| IO18 | I/O | codec_i2s_dout | |
| IO19 | I/O | i2c_clk | |
| IO21 | I/O | i2c_sda | |
| IO22 | I/O | lcd_scl | |
| IO23 | I/O | lcd_sda | |
| IO25 | I/O | lcd_res | |
| IO26 | I/O | lcd_dc | |
| IO27 | I/O | pmic_nCE | |
| IO32 | I/O | io_expander_reset_l | |
| IO33 | I/O | | |
| IO34 | I | | |
| IO35 | I | | |
| IO36 SENSOR_VP | I | pmic_nINT | |
| IO39 SENSOR_VN | I | io_expander_int | |

### 5.2 Pin expander

|IO°  |Type | Active Mode |
|-----|-----|---|
| IO0 |  I  | button_enter |
| IO1 |  I  | button_back |
| IO2 |  I  | button_next |
| IO3 |  I  | button_direction |
| IO4 |  O  | led_adc |
| IO5 |  O  | led_dac |
| IO6 |  O  | lcd_vcc_ctrl |
| IO7 |  O  | codec_reset_l |

## 6. I2C addresses

I2C address is over 7 bits.

- 0x00 -> (ESP Master)
- 0x18 -> Audio Codec
- 0x6a -> PMIC
- 0x20 -> IOs expander

## 7. Layout

### 7.1 Layout main ideas

The goals were to have:

- all the high speed signals on the first layer
  - I2S
  - USB data
- all the analog signals on the first layer level and in a define region.
- respect the mecanical constraints for the buttons position. To be able to have a functional box over it.
- have the antena on a side that could be directed toward the user
- use the led in the box.
- match impedance for the usb
- the RF should be far away from the analog
- close to the antenna, there should be no HF signals and as much ground as possible.

#### 7.1.1 Rev 3.0

The user interface is the back of the PCB:



The spi screen is going to be put in the big white rectangle. The three buttons : previous, enter and next for controlling the screen are put under the screen. A slide switch was added to select the mode between Jack -> Bluetooth or Bluetooth -> Jack. It also controls the two LEDs indicating the direction.

Two more leds are available on the top right corner to indicate if the device is on and the last one to indicate if the device is plugged.

On the other side, the main one, there are all the main components and all the main signals :



All the inputs/outputs connectors are located on the same slide of the board. The antenna is outside of the board to have the maximum omni-directional radiation pattern. The analog part is as far as possible from the RF.

#### 7.1.2 Rev 3.1




### 7.2 Impedance matching

The USB differential pair should be 90ohms.

impedance_matching_computations

Rev 3.1: Removed programming through USB so no need for impedance matching anymore.

### 7.3 Trace Length

- left and right of jack 3.5mm are the same length (+-0.1mm)
- left and right of jack 2.5mm are the same length (+-0.1mm)

Rev 3.0:

- for I2S:
  - Shortest line : 25.75mm
  - Longest line : 31.42mm
  - delta is 5.67mm. Assuming a delay of 6.2ps/mm, it creates a delay of 35ps which respects the timing requirements of the audio-codec.

Rev 3.1:

I2S lines are tuned to have the same length.

### 7.4 Update footprints

The goal is to edit some footprints for easier debug.

Footprint of Audio Codec before:
Footprint of Audio Codec before

Footprint of Audio Codec after:
Footprint of Audio Codec after

Footprint of PMIC before:
Footprint of PMIC before

Footprint of PMIC after:
Footprint of PMIC after

### 7.5 Layers

L1 : Signals
L2 : GND
L3 : Power
L4 : Low signals

Refer to [Layout PDF](Jack<>Bluetooth-Layout_rev3.1.pdf)

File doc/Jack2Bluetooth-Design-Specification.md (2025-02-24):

# Jack To Bluetooth Design Specification/Details

## Purpose

The purpose of the *Jack <> Bluetooth Design Specification* is to document the design choices and provide details on this project.

## Table of Content

1. [Jack2Bluetooth features](#jack2bluetooth-features)
2. [Architecture](#2-architecture)
    1. [Jack to bluetooth](#21-jack-to-bluetooth)
    2. [Bluetooth to jack](#22-bluetooth-to-jack)
    3. [Overall Architecture](#23-overall-architecture)
    4. [User interface](#24-user-interface)
3. [Component choices](#3-component-choices)
    1. [MCU](#31-mcu--microcontroller-unit)
    2. [Audio codec](#32-audio-codec)
    3. [Battery](#33-battery)
        1. [ESP32-C6 curruent consumption](#331-esp32-c6-current-consumption)
        2. [TLV320AIC3101 current consumption](#332-tlv320aic3101-current-consumption)
        3. [Current consumption conclusions](#333-current-consumption-conclusions)
    4. [PMIC](#34-pmic--power-management-integrated-circuit)
    5. [LDO](#35-ldo--low-dropout-voltage-regulator)
    6. [Switch Regulator](#36-switching-voltage-regulator-switch)
4. [Electronic schematic](#4-electronic-schematic)
    1. [Jack 3.5mm](#41-jack-35mm)
    2. [Jack 2.5mm](#42-jack-25mm)
    3. [Audio Codec](#43-audio-codec-tlv320aic3101)
    4. [MCU](#44-mcu)
5. [GPIOs pin assignments](#5-gpios-pin-assignments)
6. [Layout](#6-layout)
    1. [Main ideas](#61-layout-main-ideas)
    2. [Impedance matching](#62-impedance-matching)
    3. [Trace length](#63-trace-length)
    4. [Layers](#64-layers)
        1. [Layer 1](#641-layer-1)
        2. [Layer 2](#642-layer-2)
        3. [Layer 3](#643-layer-3)
        4. [Layer 4](#644-layer-4)

# 1. Jack2Bluetooth features

This project aims to design a device with the following features:

- Audio input from a 2.5mm audio jack can be sampled and transmitted via Bluetooth to a headphone.
- Digital audio from a smartphone can be received via Bluetooth and converted into analog audio through a 3.5mm audio jack.
- The device can be powered via USB-C or run on battery for up to 3 hours.
- The battery charges when the device is connected to USB-C.
- A screen and buttons allow switching between "Jack to Bluetooth" and "Bluetooth to Jack" modes.
- The screen and buttons enable Bluetooth peripheral selection when the device functions as a Bluetooth central.
- The screen turns off after 1 minute of inactivity to save power.

# 2. Architecture

## 2.1 Jack to Bluetooth

For audio sampling:

The audio codec must support line-level audio input signals. The ADC is integrated into the audio codec with an amplifier.

## 2.2 Bluetooth to Jack


The audio codec must include a DAC with an amplifier.

## 2.3 Overall architecture

When merging the two previous architecture, it becomes:


And when adding power components and the user interface components, the overall architecture is :



## 2.4 User Interface:

Based on the architecture, the user interface is then:

|User interface | Direction |
| --- | --- |
| Button Next | Input |
| Button Enter | Input |
| Button Back | Input |
| Button On/Off | Input |
| Audio Jack 2.5mm | Input |
| Usb-C | Input |
| Bluetooth | Input & Output |
| Screen | Output |
| Audio Jack 3.5mm | Output |

# 3. Component choices

## 3.1 MCU : Microcontroller Unit

The ESP32 was chosen due to its widespread availability and ease of use. To simplify RF design, an ESP32 module with an integrated antenna was selected.

Requirements:
- Bluetooth support
- Integrated antenna
- USB, I2S, I2C, SPI inerfaces
- Core frequency (not the max supported but the integrated clock frequency)
- Memory size

Final choice: **ESP32-C-WROOM-N8**.

## 3.2 Audio Codec

The audio codec must include a DAC and an ADC, support line-level audio, and have single-ended inputs and outputs.

Final choice : **TLV320AIC3101** (Texas Instrument).

## 3.3 Battery

The battery should provide at least 3 hours of operation.
The most power-intensive components are the MCU, audio codec, and the screen.

The screen is going to be on only when a user push a button (and stays on for ~30s). Therefore, it should be off in idle mode, in transmitting mode or receiving mode. Since the screen is mostly off, its consumption is negligible.

### 3.3.1 ESP32-C6 Current consumption

According to the esp32-c6 datasheet, the Bluetooth LE current consumption are:


### 3.3.2 TLV320AIC3101 Current consumption

According to its datasheet, it current consumptions are :


So it is negligeable compared to the ESP32-C6 Bluetooth LE transmission currents.

### 3.3.3 Current consumption conclusions

The critical use case for current consumption is during audio sampling and Bluetooth transmission. Assuming the transmission is done at 9dBm, the required battery to power the device 3 hours is around 600mA.

## 3.4 PMIC : Power Management Integrated Circuit

The PMIC should support power path between the USB-C and the battery, battery charging when USB-C is plugged, battery discharging when unplugged.
Since a power on/off system is needed, if this IC could have sleep or deep sleep mode with very low current consumption, it could be nice.

Final choice : **BQ25619RTWR** (Texas Instrument).

All the elements are providing in the first page of product specification:


## 3.5 LDO : Low-dropout voltage regulator

It was decided to use an LDO for the analog to have a clean alimentation. LDO should not be fixed to be able to reuse it in other designs.

Choice was made to use **TLV758P** from Texas Instrument.

## 3.6 Switching Voltage Regulator switch

Choice was made to use the **TPS62A01PDDCR** from Texas Instrument.

# 4. Electronic schematic

## 4.1 Jack 3.5mm



And the ASJ datasheet gives:

asj-200-b-ht_datasheet

1. Sleeve is GND
2. Tip is Left
3. Ring is Right

So the schematic on kicad is:



## 4.2 Jack 2.5mm

The schematic is


## 4.3 Audio Codec (TLV320AIC3101)

The typical application from the spec is:



It is also worth looking at the development board:



The schematic done is then:



4 capacitors are to be determined, C8, C9, C20, C21.

First, C8=C9 and C20=C21.

Then, C8 and Rinput_of_line2R is a high pass filter, where fc = 1/(2*pi*C*R).



From TLV320AIC3101 datasheet, Rinput_of_line2R
is between 20kΩ and 80kΩ depending on the attenuation programmed in the audio codec.

The audio bandwidth is 20-20kHz. A capacitor of 1uF gives fc = 8Hz for R=20kΩ and fc= 2Hz for R=80kΩ which should be good for this application. So C8=C9=1uF.

Under the hyptohesis that the load resistance on the jack 3.5mm is 10kΩ (same hypothesis as in the TLV320AIC3101 datasheet), C20 and Rload are doing an high pass filter. A 10uF capacitor ensures that for Rload > 800Ω, the audio bandwidth is respected. So C20=C21=10uF.

## 4.4 MCU (ESP32-C6-WROOM-1)

The datasheet of the ESP32-C6-WROOM-1 recommend the following schematic:



A good resource is also the [ESP32-C6-DevKitC-1 v1.4](https://docs.espressif.com/projects/esp-dev-kits/en/latest/esp32c6/esp32-c6-devkitc-1/index.html)



Based on this two schematics, the schematic done is:



To boot the option are based on table 7 from the ESP32-C6-WROOM-1 datasheet:


## 4.5 PMIC (BQ25619RTWR)

The typical application from the BQ25619RTWR datasheet is:



The [BQ25619 evaluation module (EVM)](https://www.ti.com/tool/BQ25619EVM) is also a good reference: 

BQ25619_evm

Based on that, the schematic done is :
BQ25619_schematic

In this case, since the device is powered by USB-C, PSEL should be connected to HIGH with REGN value. This decision is based on the BQ25619_evm schematic.

PMID_GOOD is connected to REGN through a 10k resistor as described in the pin configuration section of the datasheet.

PMID is connected to a 10uF capacitor following the datasheet typical application.

QON does not need to be pulled high and can stay floating when button not pushed.

Two resistors R28 and R29 need to be determined following section `7.3.6.4.1 JEITA Guideline Compliance During Charging Mode` of the datasheet. Since the default battery used for this project does not have temperature sensor, these resistors are equals to 10k as described in the pin configuration section of the datasheet.

## 4.6 LDO (TLV758P)

The typical application is:
TLV758P_typical_app

The target analog voltage is 3.3V.
 
R1/R2 = Vout/Vfb - 1 = 5

R1 + R2 <= Vout/(1e-6) = 3.3MΩ 

Decision was to have R1 = 750kΩ and R2 = 150kΩ.
Therefore, the schematic is:
TLV758P_schematic

## 4.7 Switch Regulators (TPS62A01PDDCR)

The typical application is :
TPS62A01PDDCR_typical_application

Two regulators are required to create 1.8V and 3.3V. A voltage divider is built with R1 and R2 to fix the output voltage. 

The first one can follow the same design as the typical application since it was already designed for Vout = 1.8V.

The second one needs to be designed for Vout = 3.3V. The section `8.2.2.1 Setting the Output Voltage` of the datasheet gives R2 <= 100kΩ and R1 = R2(Vout/0.6 - 1) = 4.5*R2

Choice is made to take R1 = 100kΩ, and R2 made with two resistors R2 = 300k + 150k



## 4.8 Screen

The screen is going to be connected through an SPI interface. It will be powered thanks to the 3.3 voltage. However to be able to power off the screen, an electronic circuit is required.

Screen_schematic

## 4.9 USB-C & UART Connectors 

The schematic done is based on the devkit of the ESP32.



## 4.10 Control Buttons

control_buttons_schematic

# 5. GPIOs Pin Assignments

This table contains all the pin assignments. It was done updated during layout to make rooting easier.

|IO° | Active Mode | Debug/Bringup|
|---|---|---|
| IO0  | button_enter | |
| IO1  | button_direction| |
| IO2  | lcd_vcc_ctrl | |
| IO3  | lcd_scl | |
| IO4  | button_back | jtag_tms |
| IO5  | button_next | jtag_tdi |
| IO6  | i2c_sda | jtag_tck |
| IO7  | i2c_clk | jtag_tdo |
| IO8  | led_dac | boot |
| IO9  | led_adc | boot |
| IO10 | pmic_nINT | |
| IO11 | pmic_nCE | |
| IO12 | usb_d- | usb_d- |
| IO14 | usb_d+ | usb_d+ |
| IO15 | lcd_res | |
| IO16 | lcd_sda | uart_tx |
| IO17 | lcd_dc | uart_rx |
| IO18 | codec_reset_l  | |
| IO19 | codec_i2s_mclk | |
| IO20 | codec_i2s_bclk | |
| IO21 | codec_i2s_wclk | |
| IO22 | codec_i2s_din  | |
| IO23 | codec_i2s_dout | |

# 6. Layout

## 6.1 Layout main ideas

The goals were to have:
- all the high speed signals on the first layer
    - I2S
    - USB data
- all the analog signals on the first layer level and in a define region.
- respect the mecanical constraints for the buttons position. To be able to have a functional box over it.
- have the antena on a side that could be directed toward the user
- use the led in the box.
- match impedance for the usb
- the RF should be far away from the analog
- close to the antenna, there should be no HF signals and as much ground as possible.

The user interface is the back of the PCB:



The spi screen is going to be put in the big white rectangle. The three buttons : previous, enter and next for controlling the screen are put under the screen. A slide switch was added to select the mode between Jack -> Bluetooth or Bluetooth -> Jack. It also controls the two LEDs indicating the direction.

Two more leds are available on the top right corner to indicate if the device is on and the last one to indicate if the device is plugged.

On the other side, the main one, there are all the main components and all the main signals : 



All the inputs/outputs connectors are located on the same slide of the board. The antenna is outside of the board to have the maximum omni-directional radiation pattern. The analog part is as far as possible from the RF.

## 6.2 Impedance matching:

The USB differential pair should be 90ohms.

impedance_matching_computations

## 6.3 Trace Length

- usb are the same length (+-0.1mm)
- left and right of jack 3.5mm are the same length (+-0.1mm)
- left and right of jack 2.5mm are the same length (+-0.1mm)
- for I2S:
  - Shortest line : 25.75mm
  - Longest line : 31.42mm
  - delta is 5.67mm. Assuming a delay of 6.2ps/mm, it creates a delay of 35ps which respects the timing requirements of the audio-codec.

## 6.4 Layers

L1 : Signals
L2 : GND
L3 : Power
L4 : Low signals

### 6.4.1 Layer 1



### 6.4.2 Layer 2



### 6.4.3 Layer 3



### 6.4.4 Layer 4



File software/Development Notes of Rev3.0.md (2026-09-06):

<!-- Author : Paul Capgras -->

# Developments Notes of Rev 3.0

> **Warning: This notes is outdated. It only aims to keep an history.**

## Bringup

Command order:

- `get_idf`
- `idf.py set-target esp32`
- `idf.py build`
- `idf.py flash monitor`

Then refer to bringup:

### Boot ESP32-C6 - From UART

- Connect GND
- Connect RX to **RX**
- Connect TX to **TX**

- Put 1 of OFF
- Put 2 to ON
- Send the program through UART
  - thanks to the esp idf platform
  - run `get_idf`
  - esp32-c6 should have been also selected
  - `idf.py build` to build
  - `idf.py flash monitor`
  - You might need to push reset button
  - to quit monitor terminal run CTRL-] on querty or CTRL+ALT GR+$ on azerty
- Put 2 to OFF
- Push reset button

- `i2cdetect`

> Ouput should be:

- 00 -> (ESP Master)
- 18 -> Audio Codec
- 6a -> PMIC

### Good practice learnt

- put a pin for all power lines
- put an arrow for directive lines in the silkscreen
- don't forget direction for the silkscreen for diodes (and leds !)

### Detect I2C peripherals

- use the i2c_tools from `/home/paul/esp/esp-idf/examples/peripherals/i2c`
- go to the clone directory and run the idf commands.
- i2c detect does not detect anything so far
- connect oled i2c screen for a debug purpose. I might need a breadboard to connect grounds.

### Embedded development

- VS code with esp-idf extension (from Espressif Systems) and C/C++ (from Microsoft).
- Some `#include`might me red, you need to add the esp path to the extension.
- This video explains it at 7min15 : <https://www.youtube.com/watch?v=5IuZ-E8Tmhg&t=5s>

i2cconfig --port=0 --freq=100000 --sda=6 --scl=7

## Jun 27

- Je tente de remettre 5V sur Vcc et j'observe Vsystem
- Vcc est connecté à mon PMIC donc c'est normal que rien ne se passe sur Vsystem vu que le PMIC est dead.

- Je mets 3.323V sur Vsystem et j'observe:
  - 3.3VA : mesure : 3.321V
  - 1.8VDD: mesure : 1.823V
  - 3.3VDD: mesure : 3.317V

Là ma carte est correctement alimentée. Je peux mener l'enquête

---

i2cdetect

i2cdump

---

## Sept 17

### Bringup from USB-C

- Connect USB-C cable
- Send the program
- PB: interaction mode is not working

So go to normal bringup
[Refer to bringup](#bringup)

## Sept 18th

- Copied esp32/a2dp_sink.
- Run it with internal DAC.
- Access with my phone to the device ESP_speaker
- Signal was visible on the oscilloscope!
- Commit is called feat: setup classic bt audio_sink on the esp32 using internal DAC.

Next step use the audio codec. For that, I need to

- configure the audio codec using the esp32-c6.
- send the signal using the other esp.

## Oct 1

- Issue 1 : Short between SW et Bat-. It is probably around the PMIC...
  - I want to do an Xray to know if it is the chip, or the soldering
    - No xray equipment at the U
- I have added a wire on system.
- Issue 2 : I can download the pogram on the esp32c6 but I can't leave the download mode.
  - IO9 stays low. Pull up is not working.
    - I removed the esp32c6 as they were no issue on the pcb.
      - Now my voltage does not reach 3.3V anymore on VDD and AVDD. Nor 1.8V on AVDD

## Oct 2

- I have deeply cleaned the board with flux remover and the voltage issue was solved.

## Oct 3

- I have connected 6pins for the i2s and 2 pins for i2c to control these bus with the external esp32 dev kit.

## Oct 6

- I detect PMIC with i2c through external esp.
- I don't detect audio codec.
  - The reset pin goes from 0V to 1.4V. It is supposed to go up to 3.3V in idle.
  - I am trying to remove external alimentation and to power everything with external esp
  - powering everything with esp works - I have all the good voltages. The reset pin of the audio codec does go to 0V and then go back to 3.3V
  - I still do not see my audio codec in 6a...
  - That is because it is supposed to be in 0x18. My README was bad. So no issue I see my audio codec successfully!!!

The board setup now looks like that:
Board Setup

| Pin name | ESP32c6 pin number | External ESP32 devkit pin number |
| - | - | - |
| IO6 | i2c_sda | IO16 |
| IO7 | i2c_clk | IO17 |
| IO18 | codec_reset_l | IO32 |
| IO19 | codec_i2s_mclk | IO33 |
| IO20 | codec_i2s_bclk | IO25 |
| IO21 | codec_i2s_wclk | IO26 |
| IO22 | codec_i2s_din | IO27 |
| IO23 | codec_i2s_dout | IO14 |

I was working on the folder esp32_b2j.

I have removed what is linked with A2VRCP and try to keep only A2DP.
Now I was trying to make the link with the external I2S codec.
Two parts:

- understand what has been programmed and how is the A2DP send to I2S: What are the I2S parameters
- configure the audio codec according to these parameters

## Oct 10

- I have understood the esp example
- I have reorganized and better name functions
- I have removed the I2S link for now

- I am now configuring the codec.
- I based mon analysis on Figure 26 of the codec spec.
- So I will be using HPL/ROUT

## Oct 11

- I am programming the AudioCodec

### Clocks

I want my clock to be 256 of fs and it is coming from the master clock


- So I choose to use the path on the left.
- CLKDIV_CLKIN need to be enabled and select MCLK - Register 102.
- Q should be be equal to 2 - Register 3.
- CODEC_CLKIN should select CLKDIV_OUT -> Register 101.
- CLK_DIV uses MCLK -> Register 102

```c
// Register 3 - PLL Programming Register A
// D7   - 0    -
// D6-3 - 0010 - Q = 2
// D2-0 - 000  -
is_expected(3, i2c_get(CODEC_ADDR, 3), 0b00010000);

// Register 102 - Clock Generation Control Register
// D7-6 - 00 - CLKDIV_IN selects MCLK
// D5-4 - 0
// D3-0 - 0010
// No need to write
is_expected(102, i2c_get(CODEC_ADDR, 102), 0b00000010);

// Register 101 - Clock register
i2c_get(CODEC_ADDR, 101);
// D7-1 - 0
// D0   - 1 - CODEC_CLKIN uses CLKDIV_OUT
i2c_set(CODEC_ADDR, 101, 0b00000001);
is_expected(101, i2c_get(CODEC_ADDR, 101), 0b00000001);
```

### DAC

I want my audio output on HPR/Lout:
DAC_path


- so according to this : I should put my audio on DAC_L2 and DAC_R2 - Register 41.
- Both DAC should be powered up - Register 37.
- Both DAC should be using fs = 44.1KHz and streaming L/R data - Register 7.
- HPLout should be powered up and unmuted - Register 51
- HPRout should be powered up and unmuted - Register 65

Crash when I send the audio. Honnestly without UART working (as it is used to trasnmit MCLK), it is really a mess to debug.

## Oct 12

I am choosing not to use MCLK from the ESP and to generate the clock internally in my audio codec with the internal PLL using the BCLK as a source.

### Clock

Let's configure the PLL.


- CODEC_CLK (BCLK) = KxRxBCLK/(8xP) = 256 fs = KxRxfs/(8x8xP). Which implies that KxR/P = 64x256. So JxDxR/P = 64x256. Let's take P=1, R=2, J=32, D=256
- Enable PLL and set P in register 3
- Set J in register 4
- Set D in register 5 and 6
- Set R in register 11
- CODEC_CLKIN should select PLLDIV_OUT -> Register 101.
- PLLDIV_IN uses BCLK -> Register 102

```c
/*
  * Clock
  */

// Register 3 - PLL Programming Register A
// D7   - 1    - PLL is enabled
// D6-3 - 0000 -
// D2-0 - 001  - P= 1
i2c_set(CODEC_ADDR, 3, 0b10000001);
is_expected(3, i2c_get(CODEC_ADDR, 3), 0b10000001);

// Register 4 - PLL Programming Register B
// D7-2 - 100000 // Set J to 32
// D1-0 - 00
i2c_set(CODEC_ADDR, 4, 0b10000000);
is_expected(4, i2c_get(CODEC_ADDR, 4), 0b10000000);

// Register 5 and 6
// Set D to 100000000 (256)
// MSB D7-0 (reg 5) 00000100
// LSB D7-2 (reg 6) 000000
// D1-0             00
i2c_set(CODEC_ADDR, 5, 0b00000100);
i2c_set(CODEC_ADDR, 6, 0b00000000);
is_expected(5, i2c_get(CODEC_ADDR, 5), 0b00000100);
is_expected(6, i2c_get(CODEC_ADDR, 6), 0b00000000);

// Register 11 - Audio Codec Overflow Flag Register
// D7-4 0
// D3-0 0010 Set R to 0010
i2c_set(CODEC_ADDR, 11, 0b00000010);
is_expected(11, i2c_get(CODEC_ADDR, 11), 0b00000010);

// Register 102 - Clock Generation Control Register
// D7-6 - 0  -
// D5-4 - 10 - PLLCLK_IN uses BCLK
// D3-0 - 0010
// No need to write
i2c_set(CODEC_ADDR, 102, 0b00100010);
is_expected(102, i2c_get(CODEC_ADDR, 102), 0b00100010);

// Register 101 - Clock register
// D7-1 - 0
// D0   - 0 - CODEC_CLKIN uses PLLDIV_OUT
i2c_set(CODEC_ADDR, 101, 0b00000000);
is_expected(101, i2c_get(CODEC_ADDR, 101), 0b00000000);

```

Let's check if the audio is sent successfully through the i2s interface:

I do have my BCLK visible in the oscilloscope. Not the best clean clock I have seen... The frequency is fs(=44.1) * 256 / 8 = 1.41MHz so that is good. It is a free running clock.
BLCK

Ws is also free running.
WS

The Dout is also good when sending an audio:
Dout

-> Not working. Three possibilities the overshoot are problematic. And/Or the PLL is bad. And/Or the DAC is badly configured.

1. Let's have a faster BCLK with the ESP to enter spec recommendation in the example:

I add a slot of 32 bits instead of 16. This double my BCLK clock.
fs = 44.1kHz
So BCLK = fs*256/4 = 2.822MHz

PLLCLK_IN = 2.822MHz so we have 2MHz < PLLCLK_IN < 20MHz (that is the condition that was not respected before).

fS(ref) = (PLLCLK_IN × K × R)/(2048 × P)

fS(ref) = (256xfS(ref)/4 × K × R)/(2048 × P),

1 = (256 × K × R)/(4x2048 × P),

**P = 1**

KxR = 4x2048/256 = 32

K = J.D => **D=0**, **J = 32**

Other constraint:
80 MHz ≤ (PLLCLK _IN × K × R/P ) ≤ 110 MHz

**R=1**

80MHz < 90MHz < 110MHz - GOOD

Final contraint:

4 ≤ J=16 ≤ 55 - GOOD

``` c
// Register 3 - PLL Programming Register A
// D7   - 1    - PLL is enabled
// D6-3 - 0000 -
// D2-0 - 001  - P= 1
i2c_set(CODEC_ADDR, 3, 0b10000001);
is_expected(3, i2c_get(CODEC_ADDR, 3), 0b10000001);

// Register 4 - PLL Programming Register B
// D7-2 - 10000 // Set J to 32
// D1-0 - 00
i2c_set(CODEC_ADDR, 4, 0b01000000);
is_expected(4, i2c_get(CODEC_ADDR, 4), 0b01000000);

// Register 5 and 6
// Set D to 0
// MSB D7-0 (reg 5) 0
// LSB D7-2 (reg 6) 0
// D1-0             0
// always write both, and in the order reg5 then reg6.
is_expected(5, i2c_get(CODEC_ADDR, 5), 0b00000000);
is_expected(6, i2c_get(CODEC_ADDR, 6), 0b00000000);

// Register 11 - Audio Codec Overflow Flag Register
// D7-4 0
// D3-0 0010 Set R to 0001
i2c_set(CODEC_ADDR, 11, 0b00000010);
is_expected(11, i2c_get(CODEC_ADDR, 11), 0b00000010);

// Register 102 - Clock Generation Control Register
// D7-6 - 0  -
// D5-4 - 10 - PLLCLK_IN uses BCLK
// D3-0 - 0010
// No need to write
i2c_set(CODEC_ADDR, 102, 0b00100010);
is_expected(102, i2c_get(CODEC_ADDR, 102), 0b00100010);

// Register 101 - Clock register
// D7-1 - 0
// D0   - 0 - CODEC_CLKIN uses PLLDIV_OUT
i2c_set(CODEC_ADDR, 101, 0b00000000);
is_expected(101, i2c_get(CODEC_ADDR, 101), 0b00000000);
```

1. Let's filter this signals to have cleaner signals.

### DAC

I want my audio output on HPR/Lout:
DAC_path


- so according to this : I should put my audio on DAC_L2 and DAC_R2 - Register 41.
- Both DAC should be powered up - Register 37.
- Both DAC should be using fs = 44.1KHz and streaming L/R data - Register 7.
- HPLout should be powered up and unmuted - Register 51
- HPRout should be powered up and unmuted - Register 65

Missing configuration:

- Unmute L-DAC - Register 43
- Unmute R-DAC - Register 44

---

I have not been able to make it work yet.

My rise timing is bad with the current resistor (220 ohm) around 70ns.
Spec required 4ns. I don't see how I could reach it though...

Going to 100Ohm is better around 20-30ns

50 Ohms overshoot...

---

Also I did not configured my audio codec after these edits regarding the slot offset.

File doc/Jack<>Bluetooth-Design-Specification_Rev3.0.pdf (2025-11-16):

Jack<>Bluetooth-Design-Specification.md | 2025-11-16

# Jack <> Bluetooth Design Specification/Details

## Purpose

The purpose of the Jack <> Bluetooth Design Specification is to document the design choices and provide details on this project.

## Table of Content

. Jack2Bluetooth features . Architecture
. Jack to bluetooth
. Bluetooth to jack
. Overall Architecture
. User interface
. Component choices
. MCU
. Audio codec
. Battery
. ESP32-C6 curruent consumption . TLV320AIC3101 current consumption . Current consumption conclusions
. PMIC
. LDO
. Switch Regulator
. Electronic schematic
. Jack 3.5mm
. Jack 2.5mm
. Audio Codec
. MCU
. GPIOs pin assignments
. Layout
. Main ideas
. Impedance matching
. Trace length
. Layers
. Layer 1
. Layer 2
. Layer 3
. Layer 4

## 1. Jack2Bluetooth features

This project aims to design a device with the following features:

Audio input from a 2.5mm audio jack can be sampled and transmitted via Bluetooth to a headphone.

Digital audio from a smartphone can be received via Bluetooth and converted into analog audio through a 3.5mm audio jack.
The device can be powered via USB-C or run on battery for up to 3 hours.
The battery charges when the device is connected to USB-C.
A screen and buttons allow switching between "Jack to Bluetooth" and "Bluetooth to Jack" modes. The screen and buttons enable Bluetooth peripheral selection when the device functions as a Bluetooth central.
The screen turns off after 1 minute of inactivity to save power.

## 2. Architecture

2.1 Jack to Bluetooth

For audio sampling:

The audio codec must support line-level audio input signals. The ADC is integrated into the audio codec with an amplifier.

2.2 Bluetooth to Jack

The audio codec must include a DAC with an amplifier.

2.3 Overall architecture

When merging the two previous architecture, it becomes:


And when adding power components and the user interface components, the overall architecture is :


2.4 User Interface

Based on the architecture, the user interface is then:

User interface | Direction
Button Next | Input
Button Enter | Input
Button Back | Input
Button On/Off | Input
Audio Jack 2.5mm | Input
Usb-C | Input
Bluetooth | Input & Output
Screen | Output
Audio Jack 3.5mm | Output

## 3. Component choices

3.1 MCU : Microcontroller Unit

The ESP32 was chosen due to its widespread availability and ease of use. To simplify RF design, an ESP32 module with an integrated antenna was selected.

Requirements:

Bluetooth support
Integrated antenna
USB, I2S, I2C, SPI inerfaces
Core frequency (not the max supported but the integrated clock frequency) Memory size

Final choice: ESP32-C-WROOM-N8.

3.2 Audio Codec

The audio codec must include a DAC and an ADC, support line-level audio, and have single-ended inputs and outputs.

Final choice : TLV320AIC3101 (Texas Instrument).

3.3 Battery

The battery should provide at least 3 hours of operation. The most power-intensive components are the MCU, audio codec, and the screen.

The screen is going to be on only when a user push a button (and stays on for ~30s). Therefore, it should be off in idle mode, in transmitting mode or receiving mode. Since the screen is mostly off, its consumption is negligible.

3.3.1 ESP32-C6 Current consumption

According to the esp32-c6 datasheet, the Bluetooth LE current consumption are:


3.3.2 TLV320AIC3101 Current consumption

According to its datasheet, it current consumptions are :


So it is negligeable compared to the ESP32-C6 Bluetooth LE transmission currents.

3.3.3 Current consumption conclusions

The critical use case for current consumption is during audio sampling and Bluetooth transmission. Assuming the transmission is done at 9dBm, the required battery to power the device 3 hours is around 600mA.

3.4 PMIC : Power Management Integrated Circuit

The PMIC should support power path between the USB-C and the battery, battery charging when USB-C is plugged, battery discharging when unplugged. Since a power on/off system is needed, if this IC could have sleep or deep sleep mode with very low current consumption, it could be nice.

Final choice : BQ25619RTWR (Texas Instrument).

All the elements are providing in the first page of product specification:


3.5 LDO : Low-dropout voltage regulator

It was decided to use an LDO for the analog to have a clean alimentation. LDO should not be fixed to be able to reuse it in other designs.

Choice was made to use TLV758P from Texas Instrument.

3.6 Switching Voltage Regulator switch

Choice was made to use the TPS62A01PDDCR from Texas Instrument.

## 4. Electronic schematic


4.1 Jack 3.5mm

And the ASJ datasheet gives:

. Sleeve is GND
. Tip is Left
. Ring is Right


So the schematic on kicad is:

4.2 Jack 2.5mm

The schematic is

4.3 Audio Codec (TLV320AIC3101)

The typical application from the spec is:

It is also worth looking at the development board:


The schematic done is then:


4 capacitors are to be determined, C8, C9, C20, C21.

First, C8=C9 and C20=C21.

Then, C8 and Rinput_of_line2R is a high pass filter, where fc = 1/(2piC*R).

From TLV320AIC3101 datasheet, Rinput_of_line2R is between 20kΩ and 80kΩ depending on the attenuation programmed in the audio codec.

The audio bandwidth is 20-20kHz. A capacitor of 1uF gives fc = 8Hz for R=20kΩ and fc= 2Hz for R=80kΩ which should be good for this application. So C8=C9=1uF.

Under the hyptohesis that the load resistance on the jack 3.5mm is 10kΩ (same hypothesis as in the TLV320AIC3101 datasheet), C20 and Rload are doing an high pass filter. A 10uF capacitor ensures that for Rload > 800Ω, the audio bandwidth is respected. So C20=C21=10uF.

4.4 MCU (ESP32-C6-WROOM-1)

The datasheet of the ESP32-C6-WROOM-1 recommend the following schematic:


A good resource is also the ESP32-C6-DevKitC-1 v1.4 (https://docs.espressif.com/projects/esp-dev-kits/en/latest/esp32c6/esp32-c6-devkitc-1/index.html)


Based on this two schematics, the schematic done is:


To boot the option are based on table 7 from the ESP32-C6-WROOM-1 datasheet:


4.5 PMIC (BQ25619RTWR)

The typical application from the BQ25619RTWR datasheet is:


The BQ25619 evaluation module (EVM) (https://www.ti.com/tool/BQ25619EVM) is also a good reference:

Based on that, the schematic done is :


In this case, since the device is powered by USB-C, PSEL should be connected to HIGH with REGN value. This decision is based on the BQ25619_evm schematic.

PMID_GOOD is connected to REGN through a 10k resistor as described in the pin configuration section of the datasheet.

PMID is connected to a 10uF capacitor following the datasheet typical application.

QON does not need to be pulled high and can stay floating when button not pushed.

Two resistors R28 and R29 need to be determined following section 7.3.6.4.1 JEITA Guideline Compliance During Charging Mode of the datasheet. Since the default battery used for this project does not have temperature sensor, these resistors are equals to 10k as described in the pin configuration section of the datasheet.

4.6 LDO (TLV758P)

The typical application is:

The target analog voltage is 3.3V.

R1/R2 = Vout/Vfb - 1 = 5

R1 + R2 <= Vout/(1e-6) = 3.3MΩ

Decision was to have R1 = 750kΩ and R2 = 150kΩ. Therefore, the schematic is:


4.7 Switch Regulators (TPS62A01PDDCR)

The typical application is :


Two regulators are required to create 1.8V and 3.3V. A voltage divider is built with R1 and R2 to fix the output voltage.

The first one can follow the same design as the typical application since it was already designed for Vout = 1.8V.

The second one needs to be designed for Vout = 3.3V. The section 8.2.2.1 Setting the Output Voltage of the datasheet gives R2 <= 100kΩ and R1 = R2(Vout/0.6 - 1) = 4.5*R2

Choice is made to take R1 = 100kΩ, and R2 made with two resistors R2 = 300k + 150k


4.8 Screen

The screen is going to be connected through an SPI interface. It will be powered thanks to the 3.3 voltage. However to be able to power off the screen, an electronic circuit is required.


4.9 USB-C & UART Connectors

The schematic done is based on the devkit of the ESP32.


4.10 Control Buttons

## 5. GPIOs Pin Assignments

This table contains all the pin assignments. It was done updated during layout to make rooting easier.

IO° | Active Mode | Debug/Bringup
IO0 | button_enter
IO1 | button_direction
IO2 | lcd_vcc_ctrl
IO3 | lcd_scl
IO4 | button_back | jtag_tms
IO5 | button_next | jtag_tdi
IO6 | i2c_sda | jtag_tck
IO7 | i2c_clk | jtag_tdo

IO° | Active Mode | Debug/Bringup
IO8 | led_dac | boot
IO9 | led_adc | boot
IO10 | pmic_nINT
IO11 | pmic_nCE
IO12 | usb_d- | usb_d-
IO14 | usb_d+ | usb_d+
IO15 | lcd_res
IO16 | lcd_sda | uart_tx
IO17 | lcd_dc | uart_rx
IO18 | codec_reset_l
IO19 | codec_i2s_mclk
IO20 | codec_i2s_bclk
IO21 | codec_i2s_wclk
IO22 | codec_i2s_din
IO23 | codec_i2s_dout

## 6. Layout

6.1 Layout main ideas

The goals were to have:

all the high speed signals on the first layer
| I2S USB data

all the analog signals on the first layer level and in a define region.
respect the mecanical constraints for the buttons position. To be able to have a functional box over it. have the antena on a side that could be directed toward the user
| use the led in the box.
match impedance for the usb
the RF should be far away from the analog
close to the antenna, there should be no HF signals and as much ground as possible.

The user interface is the back of the PCB:


The spi screen is going to be put in the big white rectangle. The three buttons : previous, enter and next for controlling the screen are put under the screen. A slide switch was added to select the mode between Jack -> Bluetooth or Bluetooth -> Jack. It also controls the two LEDs indicating the direction.

Two more leds are available on the top right corner to indicate if the device is on and the last one to indicate if the device is plugged.

On the other side, the main one, there are all the main components and all the main signals :


All the inputs/outputs connectors are located on the same slide of the board. The antenna is outside of the board to have the maximum omni-directional radiation pattern. The analog part is as far as possible from the RF.

6.2 Impedance matching

The USB differential pair should be 90ohms.


6.3 Trace Length

usb are the same length (+-0.1mm)
left and right of jack 3.5mm are the same length (+-0.1mm) left and right of jack 2.5mm are the same length (+-0.1mm) for I2S:
Shortest line : 25.75mm
Longest line : 31.42mm
delta is 5.67mm. Assuming a delay of 6.2ps/mm, it creates a delay of 35ps which respects the timing requirements of the audio-codec.

6.4 Layers

L1 : Signals L2 : GND L3 : Power L4 : Low signals

6.4.1 Layer 1

6.4.2 Layer 2

6.4.3 Layer 3


6.4.4 Layer 4

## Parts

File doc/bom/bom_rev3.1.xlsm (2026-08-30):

Reference | Value | Footprint | Qty | DNP | In stock | Mouser Order Qty | Mouser link
C1,C2,C3,C6,C7,C11,C12,C14,C15,C25,C27,C29,C35,C38 | 0.1uF | Capacitor_SMD:C_0805_2012Metric_Pad1.18x1.45mm_HandSolder | 14 |  | 88
C4,C5,C8,C9,C13,C17,C19,C30 | 1uF | Capacitor_SMD:C_0805_2012Metric_Pad1.18x1.45mm_HandSolder | 8 |  | 92
C10,C18,C20,C21,C22,C26,C28,C31,C36,C37 | 10uF | Capacitor_SMD:C_0805_2012Metric_Pad1.18x1.45mm_HandSolder | 10 |  | 10
C16,C32,C33 | 4.7uF | Capacitor_SMD:C_0805_2012Metric_Pad1.18x1.45mm_HandSolder | 3 |  | 97
C23 | 47nF | Capacitor_SMD:C_0805_2012Metric_Pad1.18x1.45mm_HandSolder | 1 |  | 9
C24 | 22uF | Capacitor_SMD:C_0805_2012Metric_Pad1.18x1.45mm_HandSolder | 1 |  | 9
C34 | 1u | Capacitor_SMD:C_0805_2012Metric_Pad1.18x1.45mm_HandSolder | 1 |  | 90
C39,C40,C41,C42 | 1uF | Capacitor_SMD:C_0805_2012Metric_Pad1.18x1.45mm_HandSolder | 4 | DNP | 90
C43 | 100uF | Capacitor_SMD:C_0805_2012Metric_Pad1.18x1.45mm_HandSolder | 1 |  |  | 10 | https://www.mouser.com/ProductDetail/Murata-Electronics/GRM21BR60G107ME11K?qs=Ey7%2FXF42M3fOLsEspt2sSQ%3D%3D
D1,D2,D4,D7,D8 | LED - green | LED_SMD:LED_0805_2012Metric_Pad1.15x1.40mm_HandSolder | 5 |  |  | Yes
D3 | 1N5819 | Diode_SMD:D_SOD-123 | 1 |  |  | Yes
D5 | SMF5V0A-E3-08 | LIB_SMF5V0A-E3-08:SMF5V0AE308 | 1 |  |  | 10 | https://www.mouser.com/ProductDetail/Vishay-General-Semiconductor/SMF5V0A-E3-08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
F1,F2 | Polyfuse | Fuse:Fuse_1210_3225Metric_Pad1.42x2.65mm_HandSolder | 2 |  |  | 10 | https://www.mouser.com/ProductDetail/YAGEO/SMDH1210B075TF?qs=jcD%2FCkGBYeNNlx%252BgVT6y1Q%3D%3D
IC1 | TLV320AIC3101IRHBR | TLV320AIC3101IRHBR:QFN50P500X500X100-33N-D | 1 |  | 1 | 2 | https://www.mouser.com/ProductDetail/Texas-Instruments/TLV320AIC3101IRHBR?qs=t6sYTo5dwUwRG5oY%252BZIOYw%3D%3D
IC2 | BQ25619RTWR | BQ25619RTWR:QFN50P400X400X80-25N-D | 1 |  | 0 | 4 | https://www.mouser.com/ProductDetail/Texas-Instruments/BQ25619RTWR?qs=P1JMDcb91o4l29Awilrd0w%3D%3D
IC3 | MCP23008T-E_SO | LIB_MCP23008T-E_SO:SOIC127P1030X265-18N | 1 |  |  | 3 | https://www.mouser.com/ProductDetail/Microchip-Technology/MCP23008T-E-SO?qs=L9Ynyw3fbhGdT1w2KdF%2FLQ%3D%3D
IC4,IC5 | TPS62A01PDDCR | TPS62A01PDDCR:SOT95P280X110-6N | 2 |  | 8
IC7 | ESP32-WROVER-E-N16R8 | ESP32-WROVER-E-N16R8:ESP32WROVEREN16R8 | 1 |  |  | 2 | https://www.mouser.com/ProductDetail/Espressif-Systems/ESP32-WROVER-E-N16R8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
J1 | SJ3-35063A | LIB_SJ3-35063A:SJ335063A | 1 |  | 2
J2 | USB_C_Receptacle | Connector_USB:USB_C_Receptacle_GCT_USB4105-xx-A_16P_TopMnt_Horizontal | 1 |  | 10
J3,J5,J10 | Conn_01x03_Pin | Connector_PinHeader_2.54mm:PinHeader_1x03_P2.54mm_Vertical | 3 |  | yes
J4 | SJ1-2503A | LIB_SJ1-2503A:SJ12503A | 1 |  | 4
J6 | Conn_01x04_Pin | Connector_PinHeader_2.54mm:PinHeader_1x04_P2.54mm_Vertical | 1 |  | yes
J7,J8 | Conn_01x02_Pin | Connector_PinHeader_2.00mm:PinHeader_1x02_P2.00mm_Vertical,Connector_PinHeader_2.54mm:PinHeader_1x02_P2.54mm_Vertical | 2 |  | yes
J9 | Conn_01x08_Pin | Connector_PinHeader_2.54mm:PinHeader_1x08_P2.54mm_Vertical | 1 |  | yes
JP1 | Jumper_3_Open | Connector_PinHeader_2.54mm:PinHeader_1x03_P2.54mm_Vertical | 1 |  | yes
L1,L2,L3 | 1uH | Inductor_SMD:L_0805_2012Metric,Inductor_SMD:L_0805_2012Metric_Pad1.05x1.20mm_HandSolder | 3 |  | 17
PS1 | TLV75801PDBVR | TLV75801PDBVR:SOT95P280X145-5N | 1 |  | 1 | 2 | https://www.mouser.com/ProductDetail/Texas-Instruments/TLV75801PDBVR?qs=vLWxofP3U2xDujOQuzp8eQ%3D%3D
Q1 | DMP3099L-13 | DMP3099L-13:SOT96P240X115-3N | 1 |  | 9
Q2,Q3 | BC846 | Package_TO_SOT_SMD:SOT-23 | 2 |  |  | 10 | https://www.mouser.com/ProductDetail/Diotec-Semiconductor/BC847C?qs=OlC7AqGiEDk0PXN3L3oHIA%3D%3D
R1,R2,R3,R22,R37,R40 | 100k | Resistor_SMD:R_0805_2012Metric_Pad1.20x1.40mm_HandSolder | 6 |  | 94
R4, R9, R11 | 3k | Resistor_SMD:R_0805_2012Metric_Pad1.20x1.40mm_HandSolder | 3 |  |  | 100 | https://www.mouser.com/ProductDetail/YAGEO/RT0805FRE133KL
R7,R8 | 2k | Resistor_SMD:R_0805_2012Metric_Pad1.20x1.40mm_HandSolder | 2 |  |  | Yes
R5,R6 | 5.1k | Resistor_SMD:R_0805_2012Metric_Pad1.20x1.40mm_HandSolder | 2 |  | 98
R10,R13,R14,R15,R19,R20,R21,R24,R29,R32,R34 | 10k | Resistor_SMD:R_0805_2012Metric_Pad1.20x1.40mm_HandSolder | 11 |  | 87
R12,R16,R17,R18,R23 | 0 | Resistor_SMD:R_0805_2012Metric_Pad1.20x1.40mm_HandSolder | 5 |  | 93
R25 | 750k | Resistor_SMD:R_0805_2012Metric_Pad1.20x1.40mm_HandSolder | 1 |  | 99
R26,R38 | 150k | Resistor_SMD:R_0805_2012Metric_Pad1.20x1.40mm_HandSolder | 2 |  | 98
R33,R35 | 499k | Resistor_SMD:R_0805_2012Metric_Pad1.20x1.40mm_HandSolder | 2 |  | 98
R36 | 200k | Resistor_SMD:R_0805_2012Metric_Pad1.20x1.40mm_HandSolder | 1 |  | 19
R39 | 300k | Resistor_SMD:R_0805_2012Metric_Pad1.20x1.40mm_HandSolder | 1 |  | 19
SW1,SW2,SW3,SW4,SW6 | SW_Push | Button_Switch_THT:SW_PUSH_6mm | 5 |  | yes
SW5,SW7 | SW_SPDT | SLW-10558:SLW-105558-2A-N-D | 2 |  | 4
TP1,TP3,TP4,TP5,TP7,TP8,TP9,TP10,TP11,TP12,TP13,TP14,TP15,TP16,TP17,TP18,TP19,TP20,TP21,TP22,TP23,TP24,TP25,TP26,TP27,TP28,TP29,TP30,TP31,TP32,TP33,TP34 | TestPoint | TestPoint:TestPoint_Pad_D1.0mm | 32 |  | yes

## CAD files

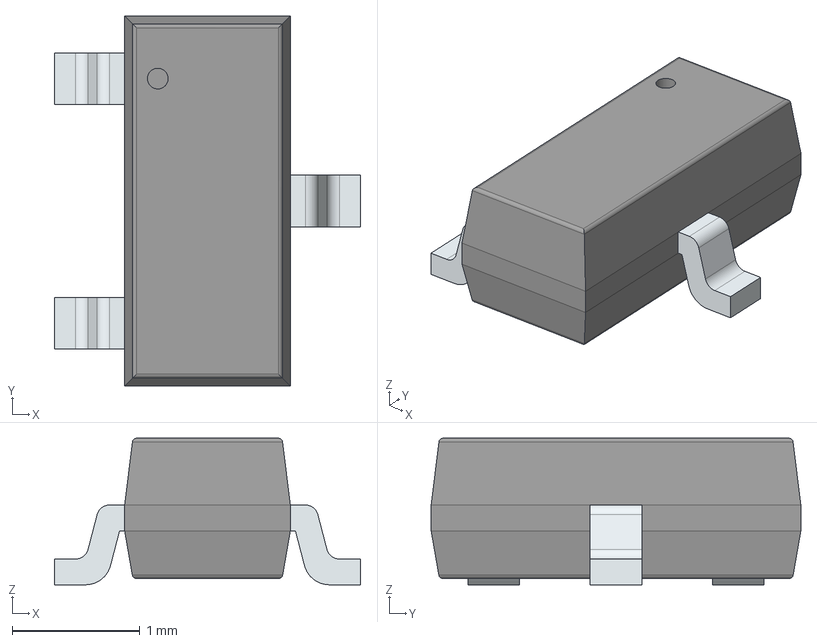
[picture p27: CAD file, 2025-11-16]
kicad/jack2bluetooth/local_lib/DMP3099L-13/DMP3099L-13.stp
2.40 x 2.90 x 1.15 mm
PinsArrayL
FilletPinR

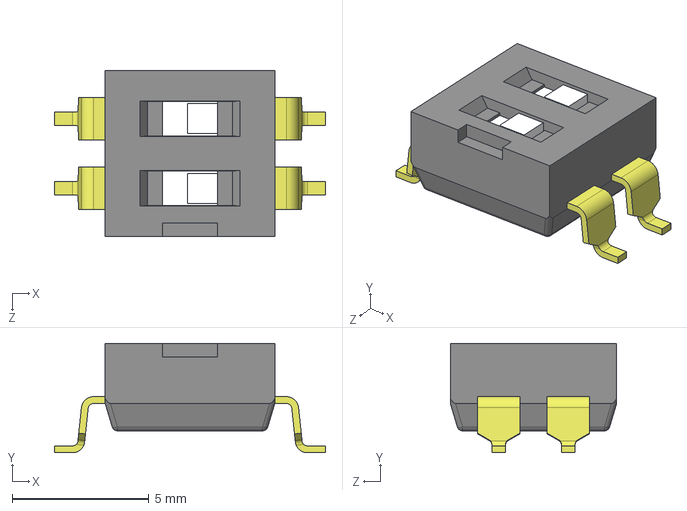
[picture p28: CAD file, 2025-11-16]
kicad/jack2bluetooth/local_lib/DS04-254-2-02BK-SMT/DS04-254-2-02BK-SMT.stp
9.90 x 4.00 x 6.08 mm

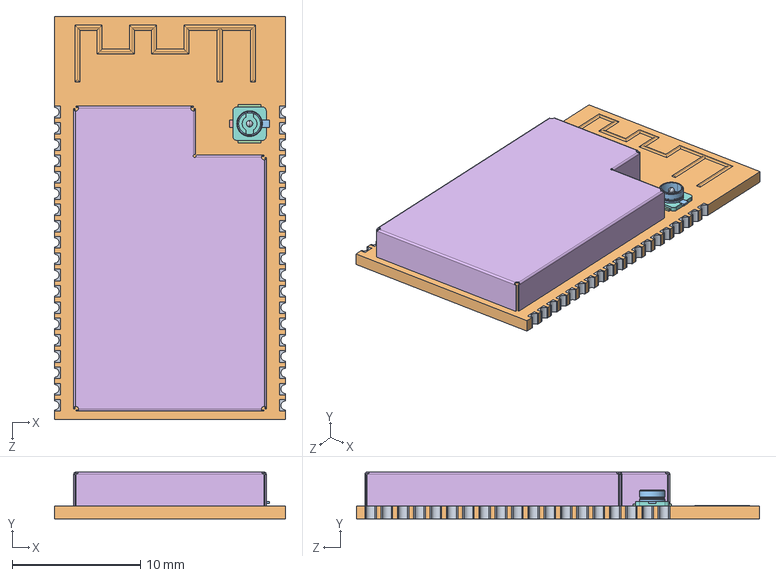
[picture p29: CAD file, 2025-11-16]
kicad/jack2bluetooth/local_lib/ESP32-WROVER-E-N16R8/ESP32-WROVER-E-N16R8.stp
18.0 x 3.65 x 31.4 mm

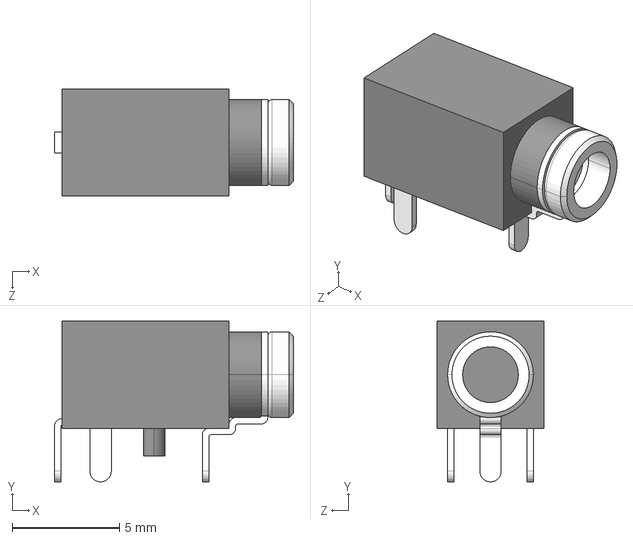
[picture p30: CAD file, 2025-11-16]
kicad/jack2bluetooth/local_lib/LIB_SJ1-2503A/SJ1-2503A.stp
11.2 x 7.50 x 5.00 mm

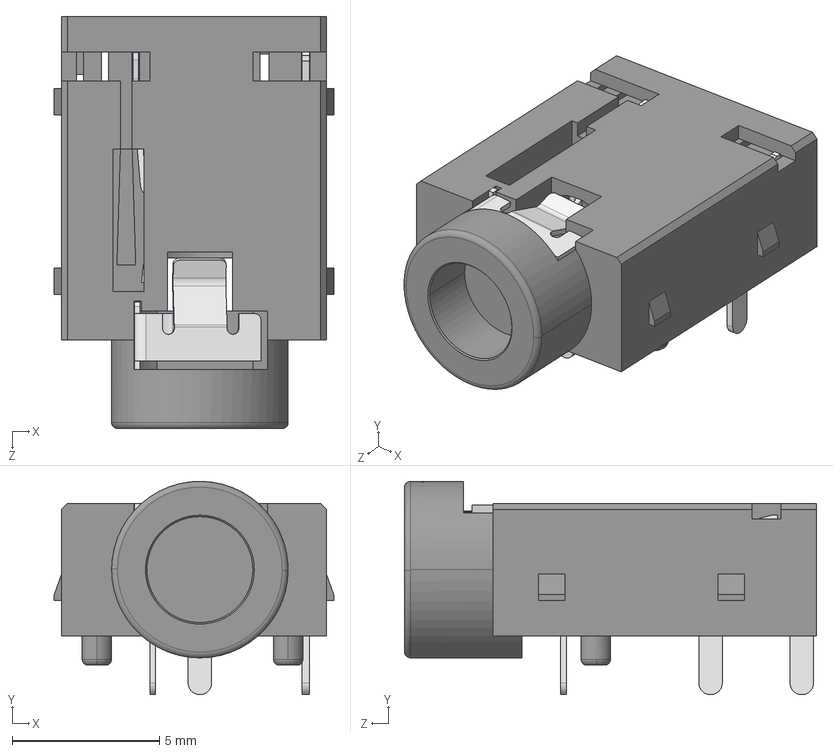
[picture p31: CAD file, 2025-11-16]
kicad/jack2bluetooth/local_lib/LIB_SJ3-35063A/SJ3-35063A.stp
9.50 x 7.25 x 14.0 mm

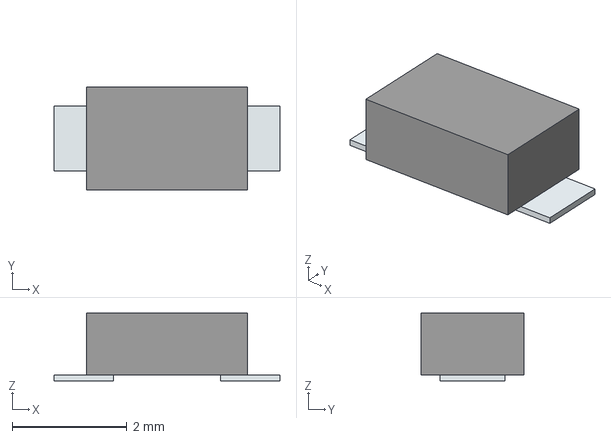
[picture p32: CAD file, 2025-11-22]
kicad/jack2bluetooth/local_lib/LIB_SMF5V0A-E3-08/SMF5V0A-E3-08.stp
3.94 x 1.80 x 1.18 mm
Pins

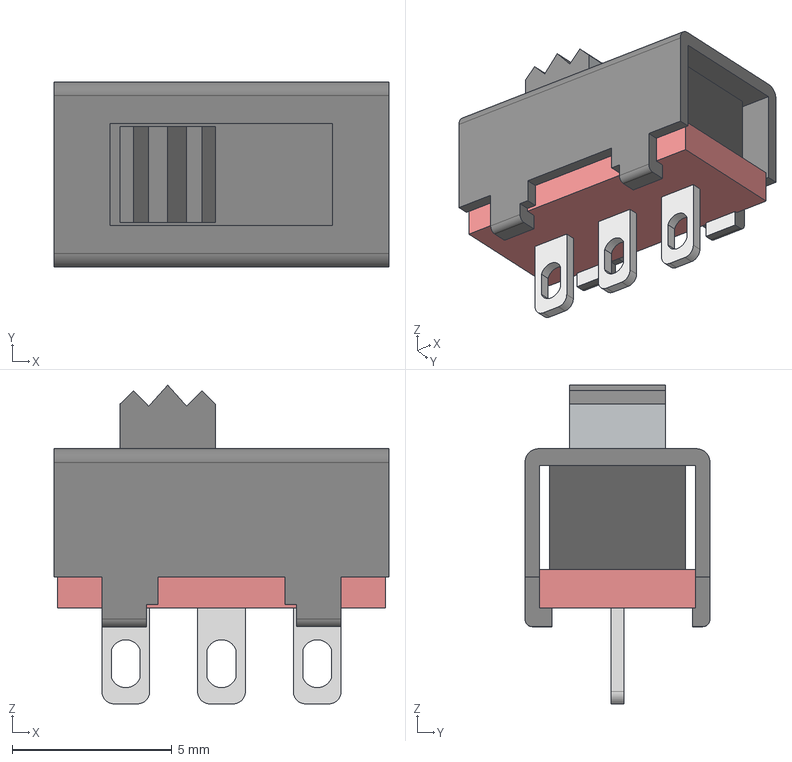
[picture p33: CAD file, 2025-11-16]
kicad/jack2bluetooth/local_lib/SLW-10558/SLW-105558-2A-N-D.stp
10.5 x 5.80 x 9.99 mm

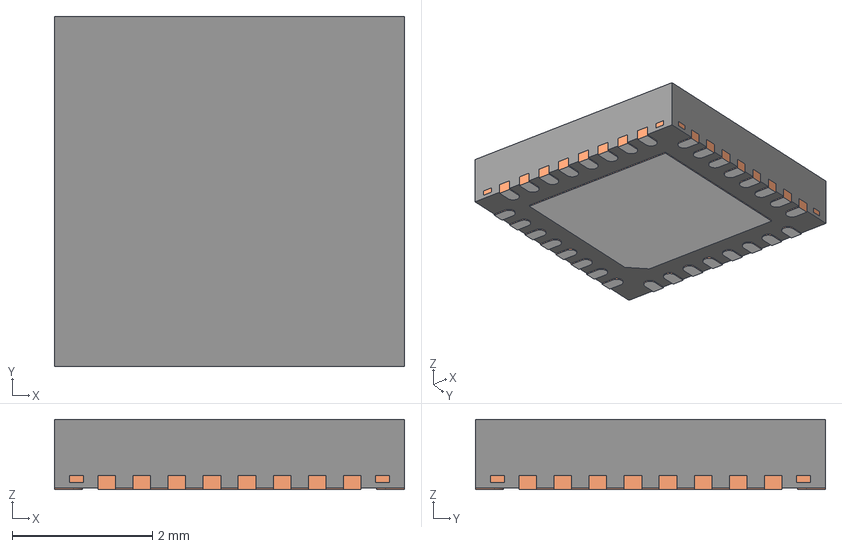
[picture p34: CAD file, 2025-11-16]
kicad/jack2bluetooth/local_lib/TLV320AIC3101IRHBR/TLV320AIC3101IRHBR.stp
5.00 x 5.00 x 1.00 mm
BODY-QFN
FRAME-RHB0032E
PIN1-ID

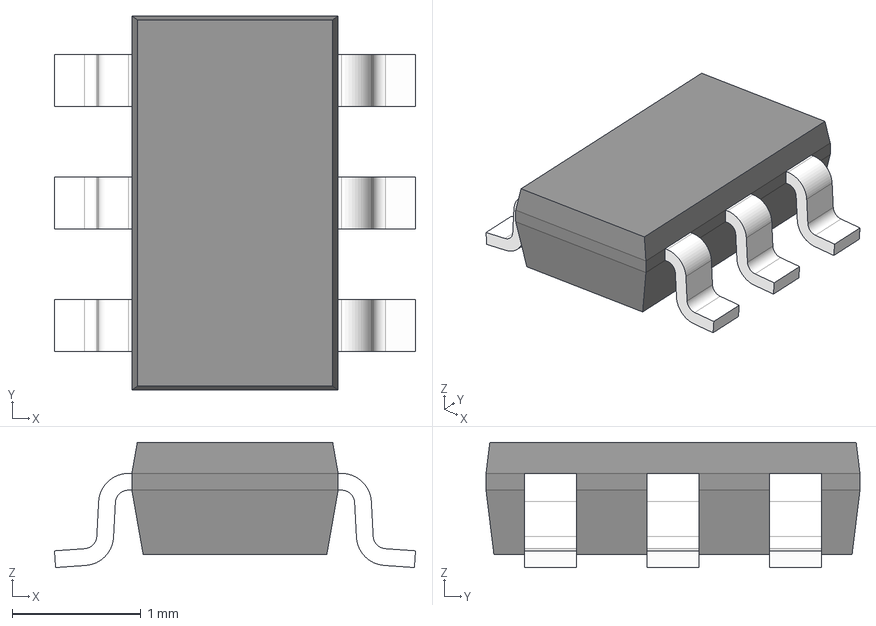
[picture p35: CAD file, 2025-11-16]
kicad/jack2bluetooth/local_lib/TPS62A01PDDCR/TPS62A01PDDCR.stp
2.80 x 2.90 x 0.97 mm
BODY-SOT
LEAD-SOT x 6

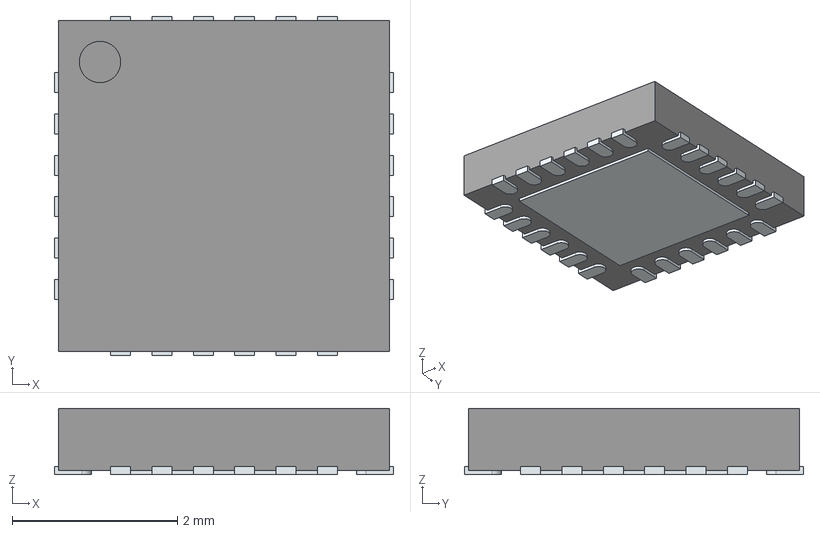
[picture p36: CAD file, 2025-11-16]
kicad/jack2bluetooth/local_lib/BQ25619RTWR/BQ25619RTWR.stp
4.10 x 4.10 x 0.8 mm
ThermalPin
PinsArrayLR
PinsArrayTB

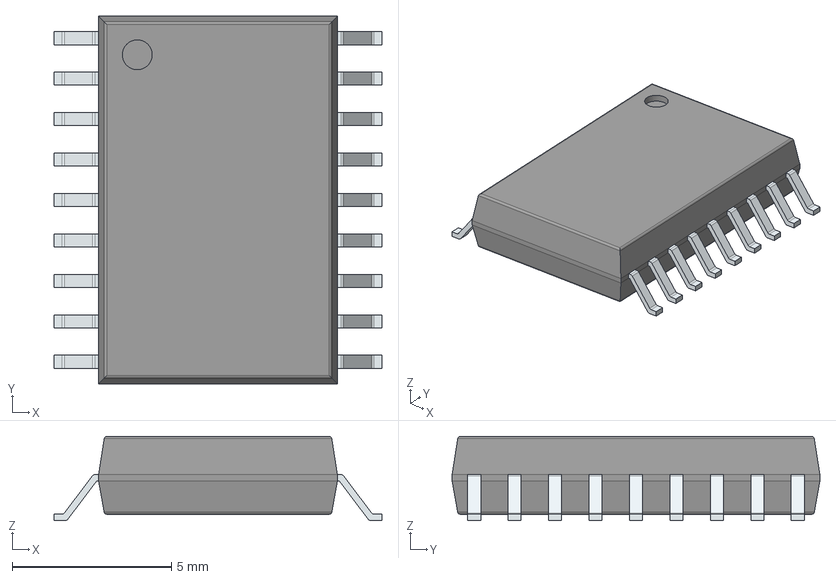
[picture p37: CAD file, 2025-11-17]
kicad/jack2bluetooth/local_lib/LIB_MCP23008T-E_SO/MCP23008T-E_SO.stp
10.3 x 11.6 x 2.65 mm
PinsArrayLR

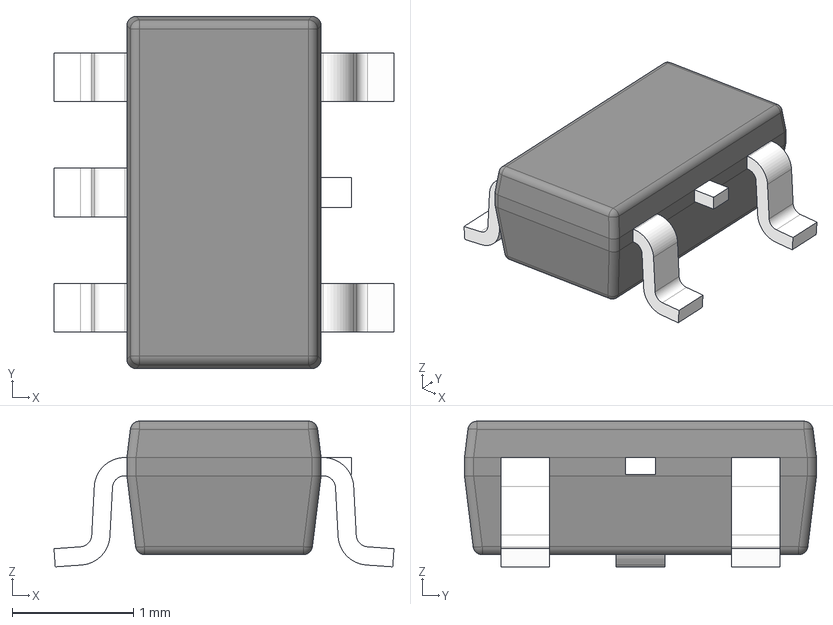
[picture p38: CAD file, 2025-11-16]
kicad/jack2bluetooth/local_lib/TLV75801PDBVR/TLV75801PDBVR.stp
2.80 x 2.90 x 1.20 mm
BODY-SOT
LEAD-SOT x 5
LEAD-DUMMY

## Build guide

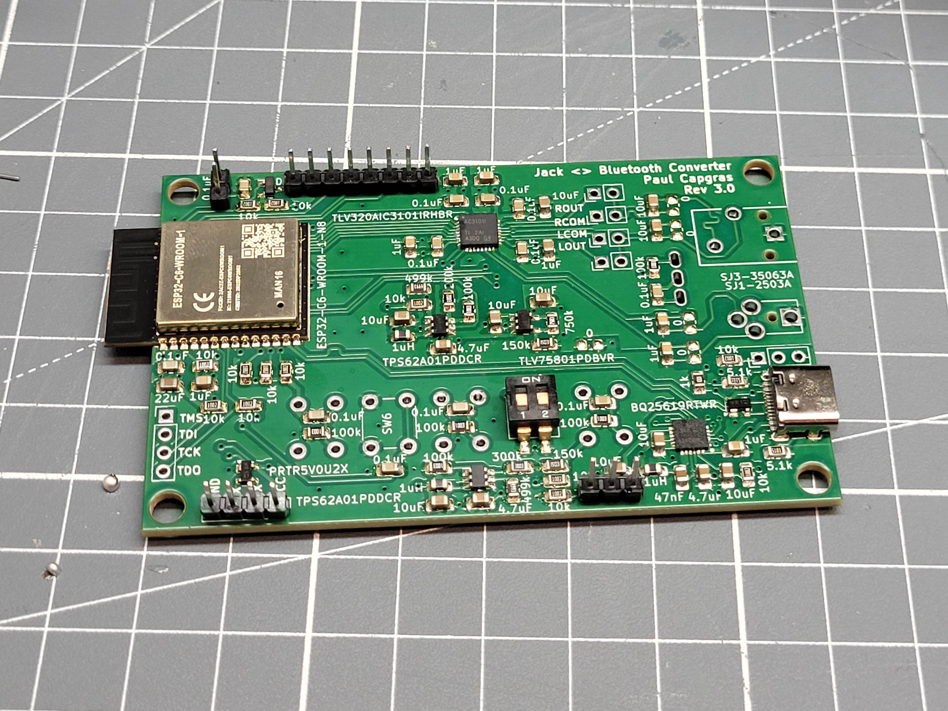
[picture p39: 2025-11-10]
doc/images_assembly/2025-04-15-PC-20250415_163110.jpg

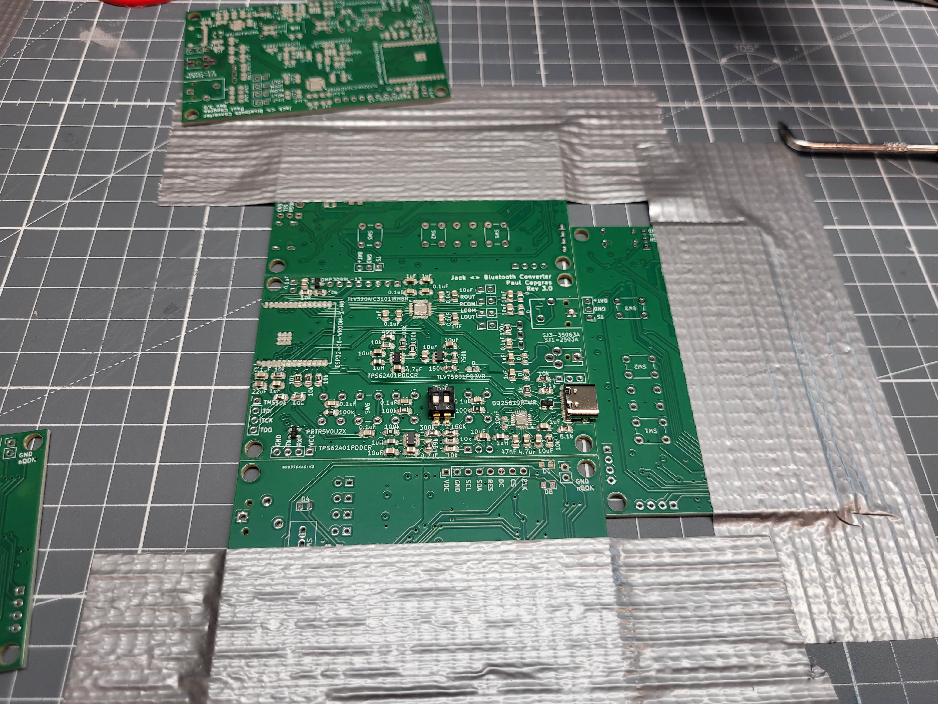
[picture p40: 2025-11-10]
doc/images_assembly/2025-04-11-PC-20250411_125233.jpg

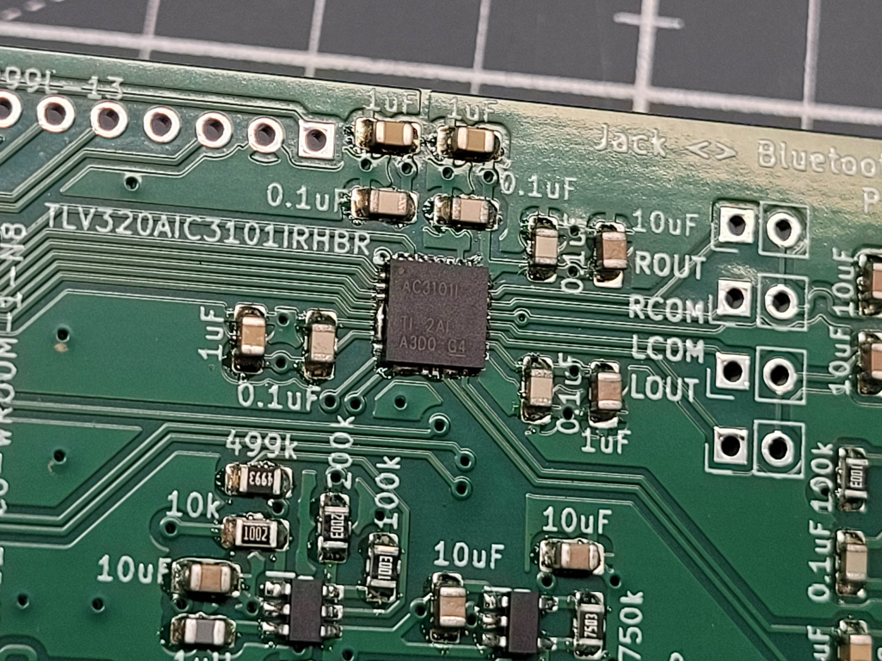
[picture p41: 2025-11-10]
doc/images_assembly/2025-04-11-PC-20250411_143844.jpg

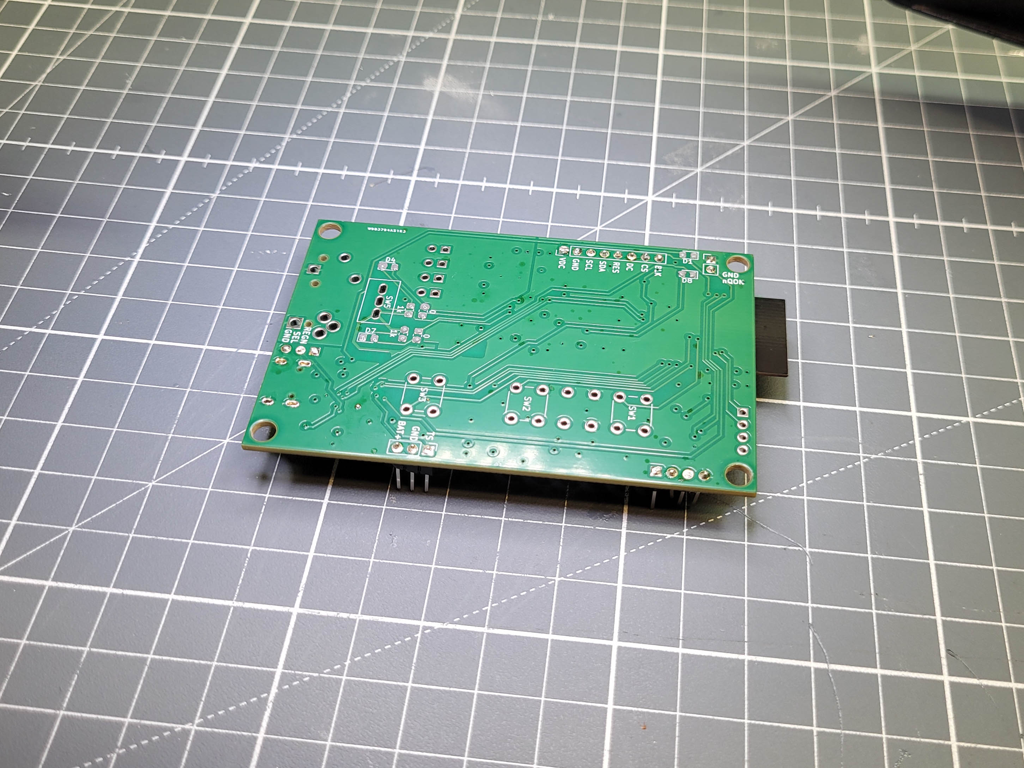
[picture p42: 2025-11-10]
doc/images_assembly/2025-04-18-PC-20250418_101406.jpg

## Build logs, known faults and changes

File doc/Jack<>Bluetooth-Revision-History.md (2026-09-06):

# Jack <> Bluetooth Revision history

## Rev 1.0

Development was halted at the schematic stage because major changes in the schematic were required (moving from one ADC and one DAC to a single CODEC) and the device was difficult to route on a 2-layer PCB.

### Rev 1.0 schematic

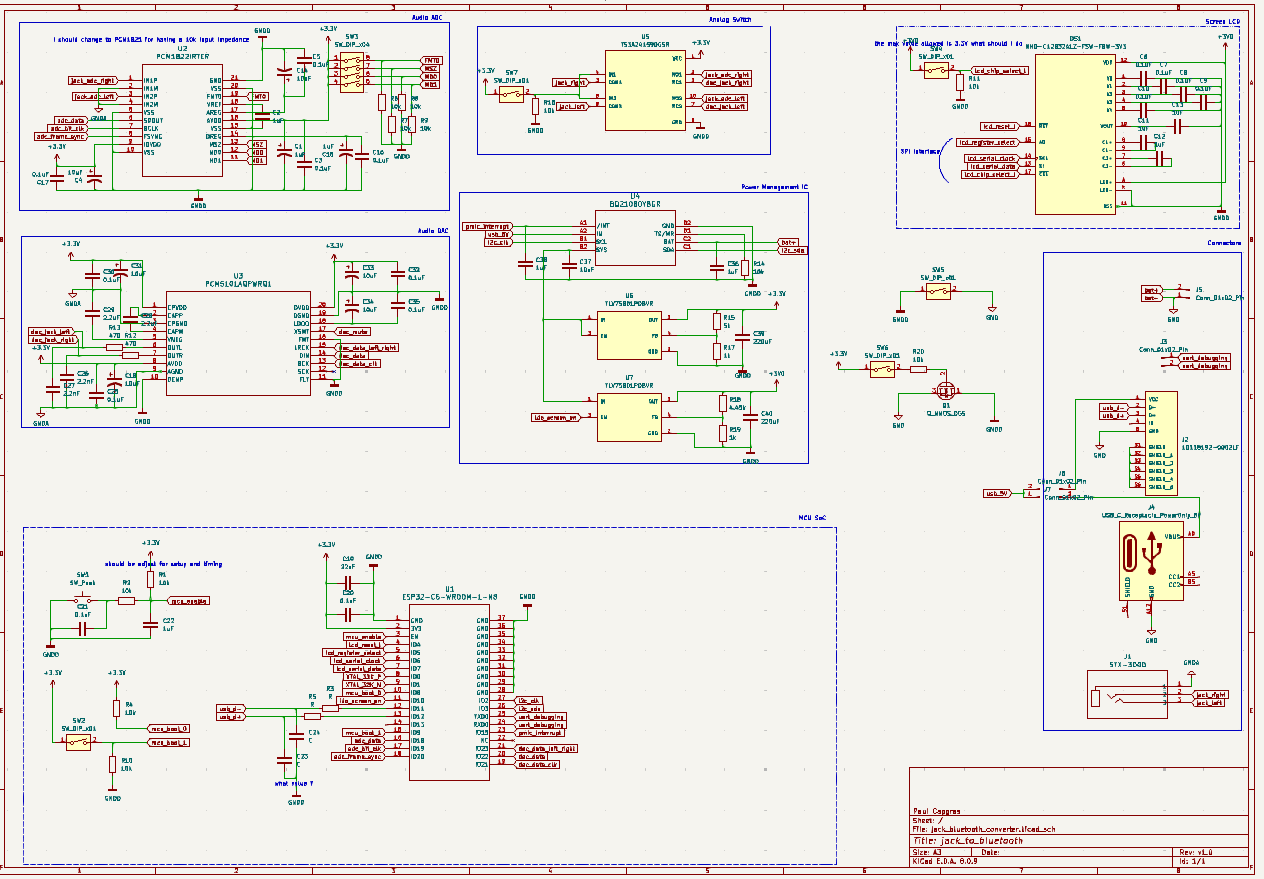
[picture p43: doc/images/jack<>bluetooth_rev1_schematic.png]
"jack<>bluetooth_rev1_schematic.png"


## Rev 2.0

The design was splitted into two separate boards: power and audio. Two schematics and layouts were created. The audio board includes one audio codec instead of the two DAC and ADC.
After a PCB review, this revision was abandoned in favor of a single device with a 4-layer board.

### Rev 2.0 Audio board schematic

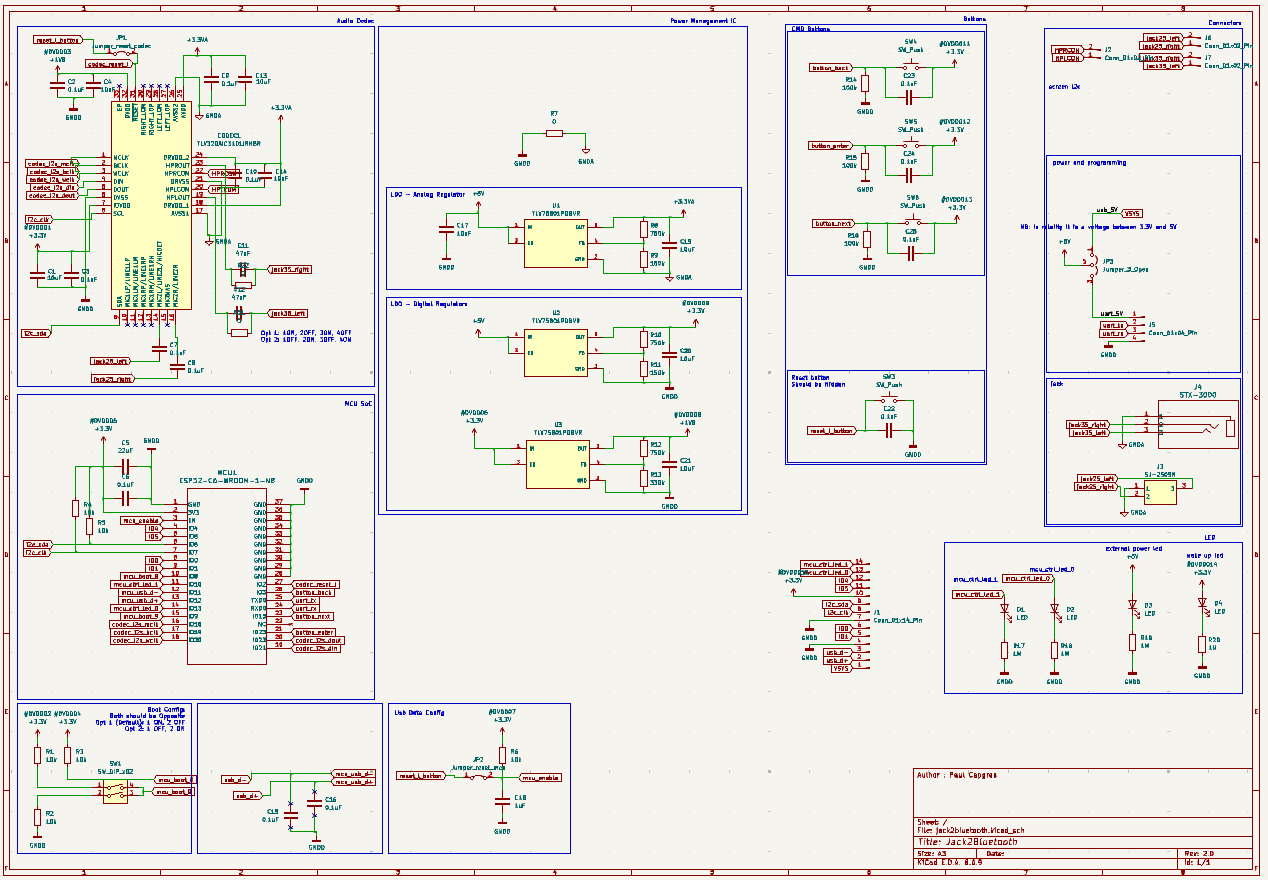
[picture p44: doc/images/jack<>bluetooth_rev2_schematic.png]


### Rev 2.0 Audio board layout

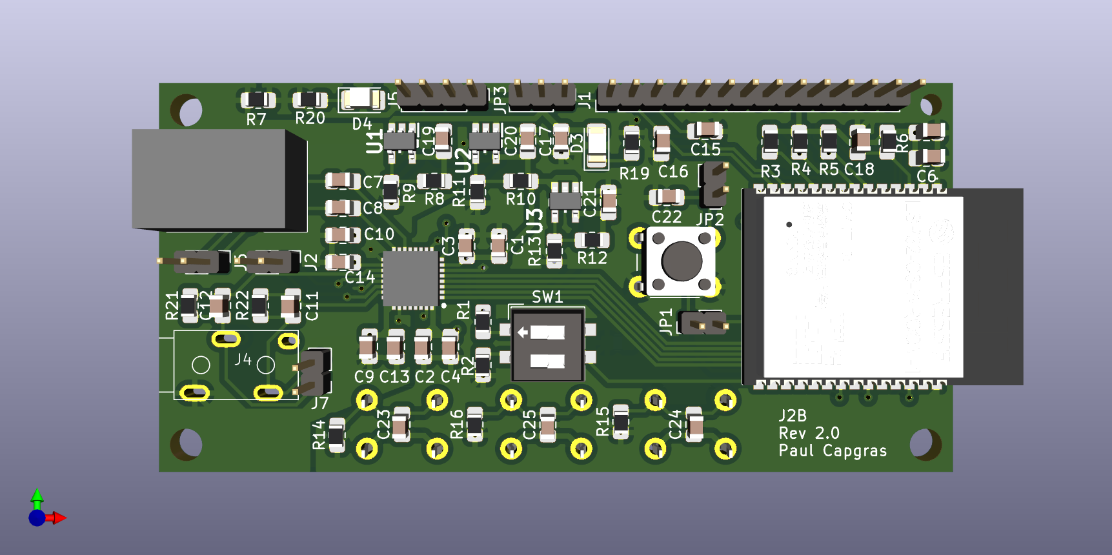
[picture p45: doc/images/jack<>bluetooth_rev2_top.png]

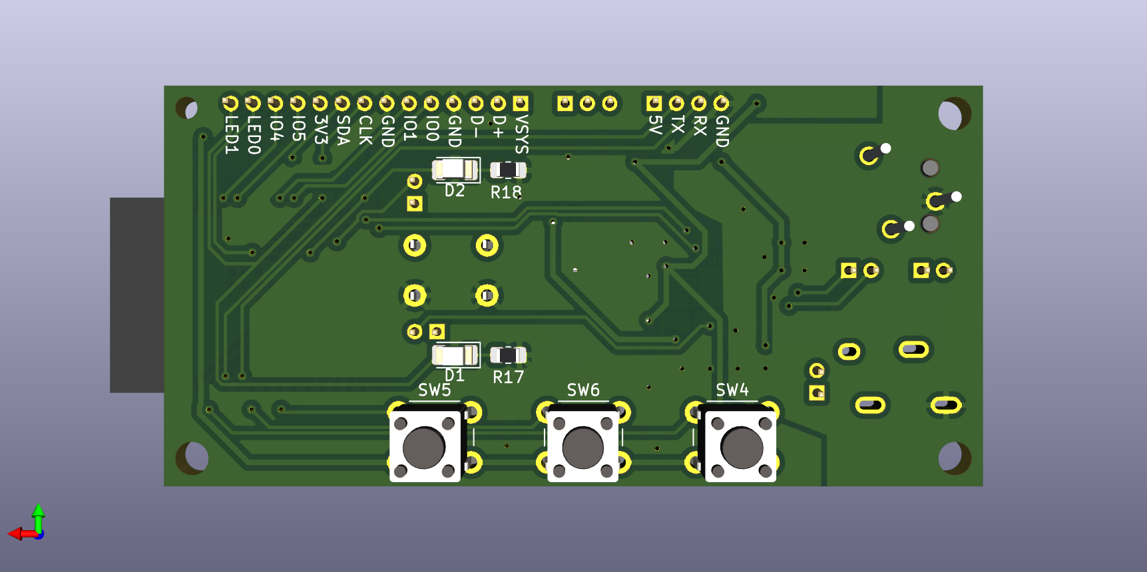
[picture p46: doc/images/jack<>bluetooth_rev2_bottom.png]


### Rev 0.1 Power management device schematic

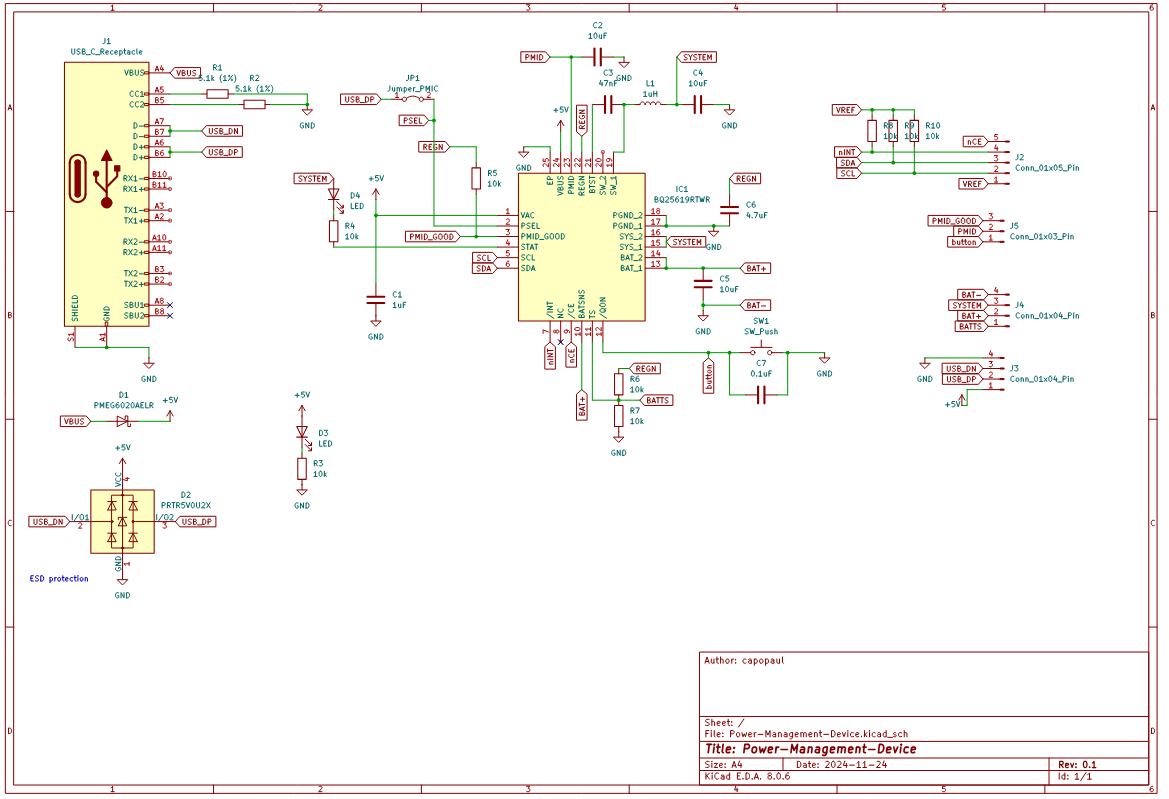
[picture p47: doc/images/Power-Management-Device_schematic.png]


### Rev 0.1 Power management device layout

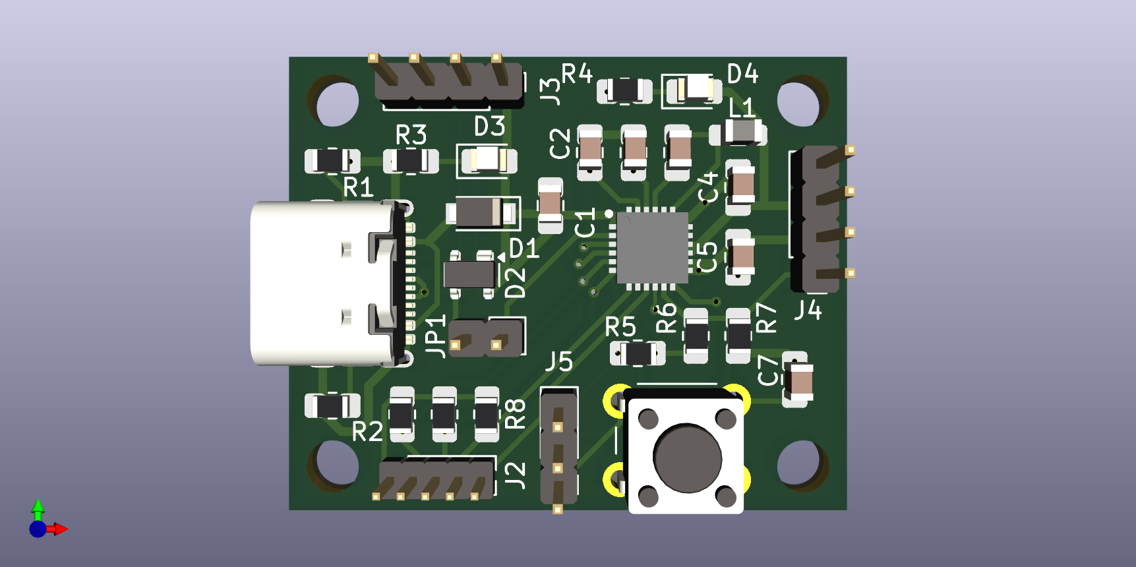
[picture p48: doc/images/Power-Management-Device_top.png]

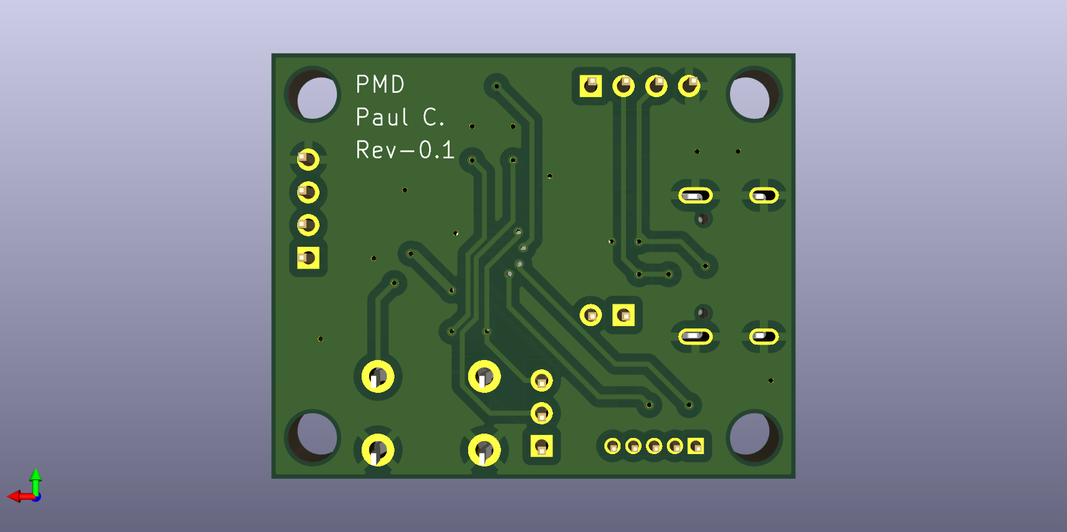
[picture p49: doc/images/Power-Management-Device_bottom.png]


## Rev 3.0

First revision to have made it up to assembly.

image pcb

### Changes Compared to Rev 2.0

- Takes mechanical constraints into account (to design an enclosure).
- Allows the screen power to be shut down using a PMOS control.
- Uses a switching voltage regulator for digital power instead of LDOs.
- Adds ESD protection to the UART.
- Fixes issues, bugs, and bad practices from Rev 2.0.

### Rev 3.0 Schematic

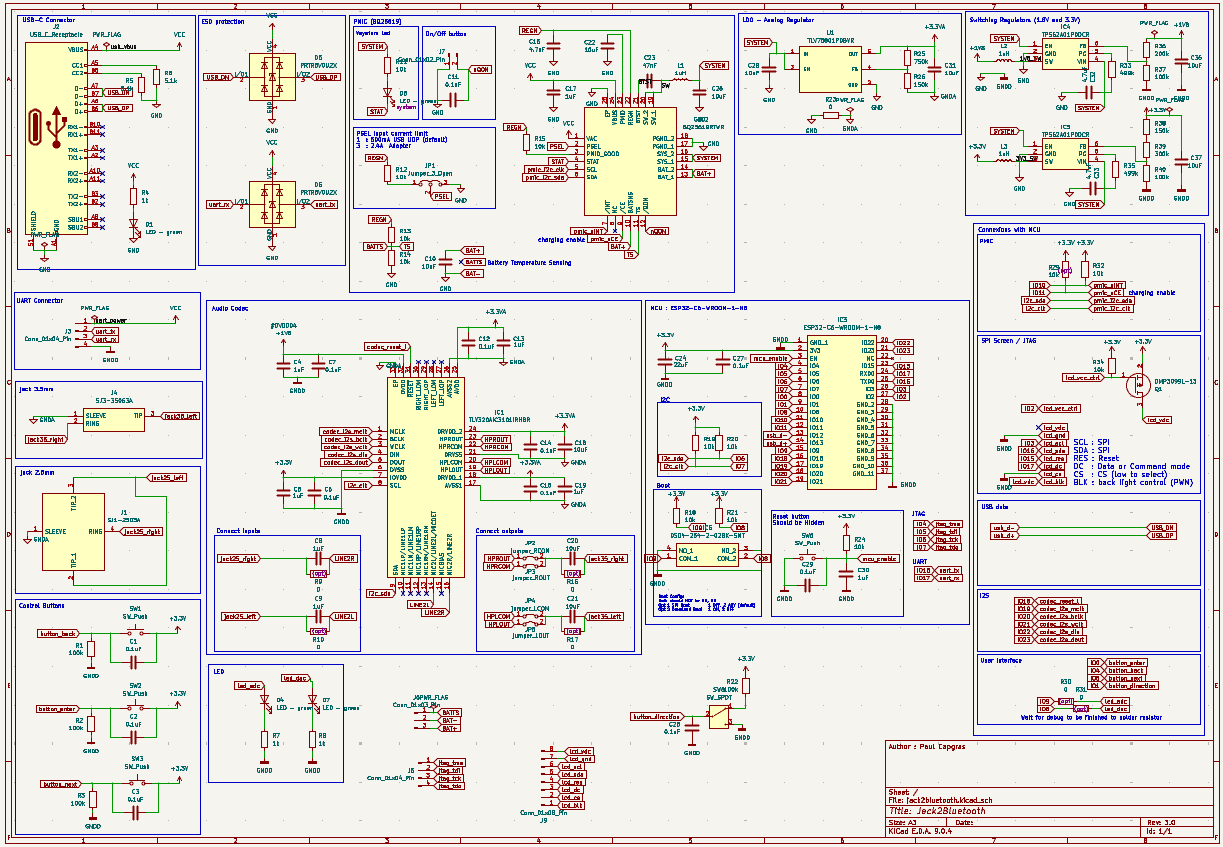
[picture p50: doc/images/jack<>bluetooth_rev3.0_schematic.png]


Also available in pdf: [jack<>bluetooth_schematic_rev3.0.pdf](jack<>bluetooth_schematic_rev3.0.pdf)

### Rev 3.0 Layout

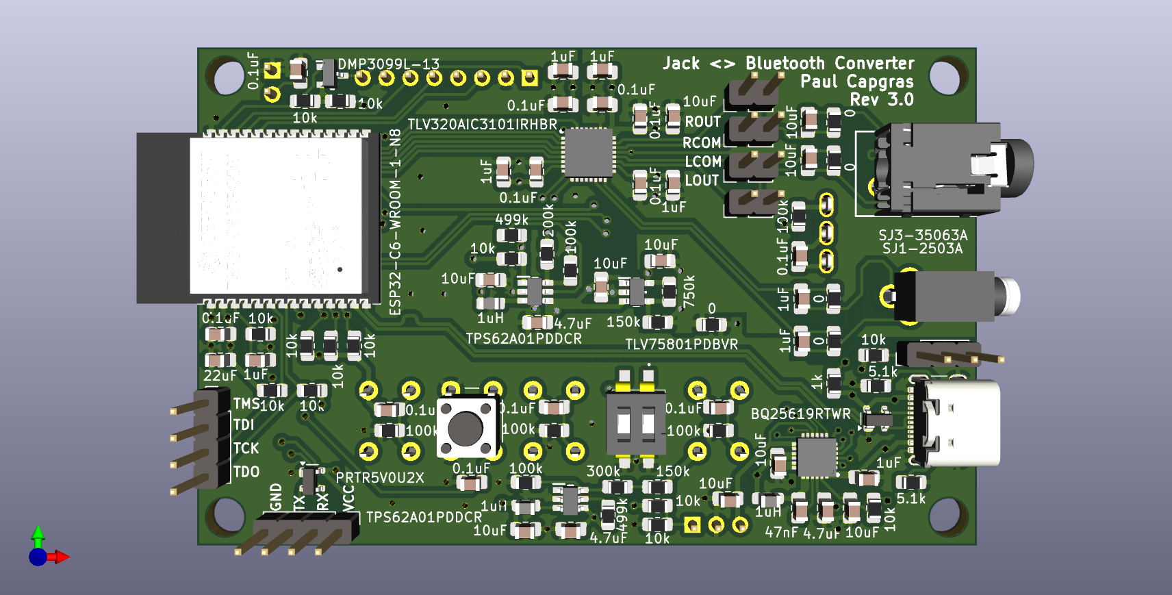
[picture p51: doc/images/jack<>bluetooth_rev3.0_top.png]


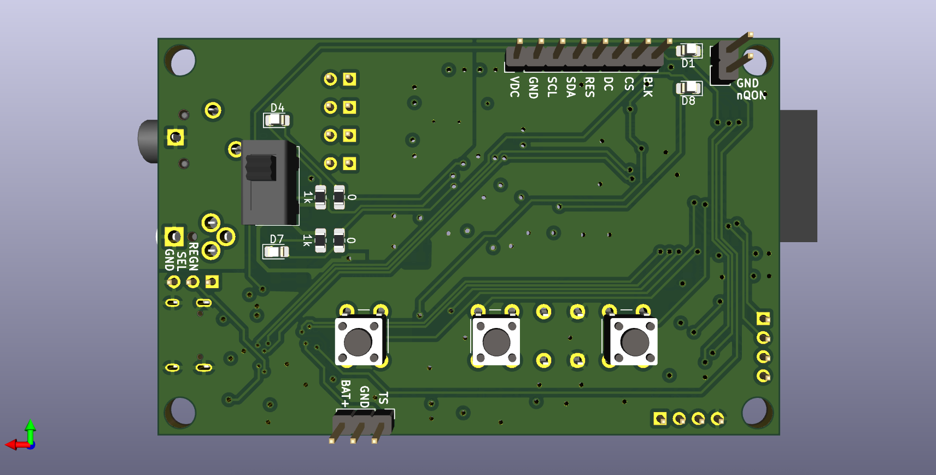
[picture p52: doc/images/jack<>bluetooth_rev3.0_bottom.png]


### Limitations

- The choice of using an esp32-c6 reveals during SW programming that this board only supports bluetooth low energy. However, the protocol used for audio bluetooth communication is called A2DP and it is part of the Classical Bluetooth.
- QFN packages for the PMIC BQ and the audio codec TLV were very difficult to solder.

## Rev 3.1

Work in progress

### Rev 3.1 Schematic

Also available in pdf: [jack<>bluetooth_schematic_rev3..pdf](jack<>bluetooth_schematic_rev3.1.pdf)

### Rev 3.1 Layout



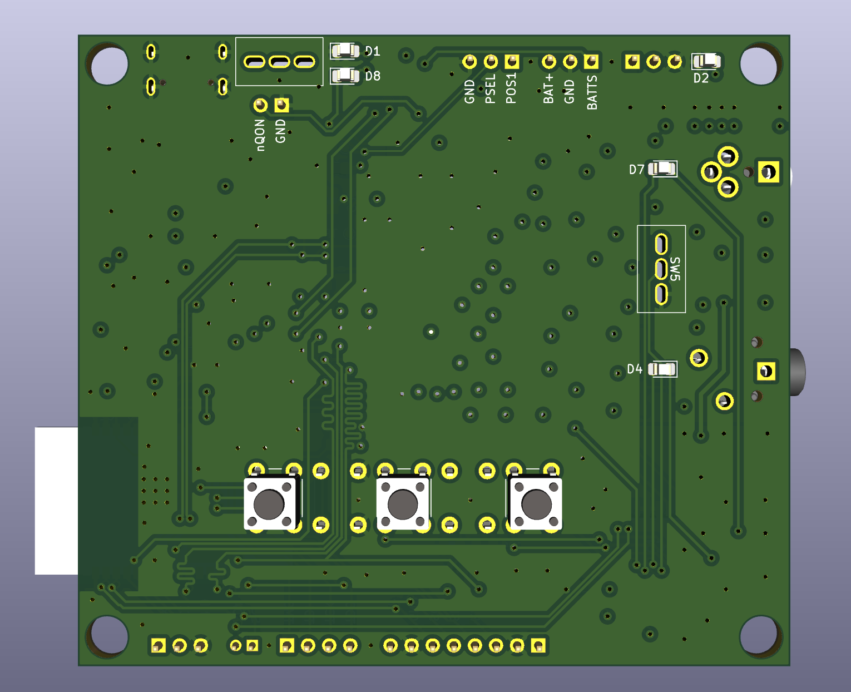
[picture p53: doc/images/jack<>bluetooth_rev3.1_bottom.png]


### Issues

1. When SW4 is pushed, Vbe of BJTs = 3.3V which is impossible.
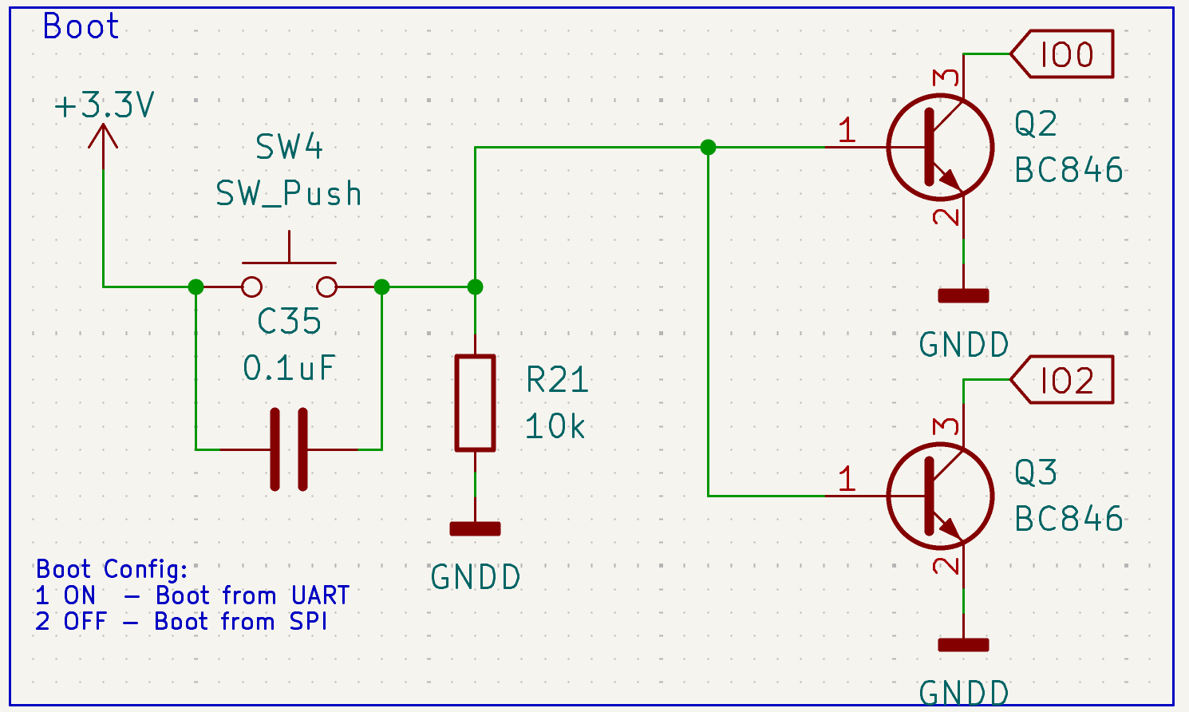
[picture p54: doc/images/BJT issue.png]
BJT issue

**Quick Fix** : Cutting the pcb line and adding a 10k resistor on the bottom of the switch.
2. Warning : Audio codec reset requires a good start of the I2C bus. It turns out working but it could have not.
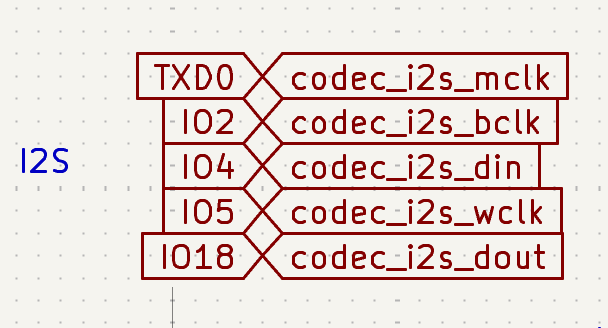
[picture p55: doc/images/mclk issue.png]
mclk issue
3. I2S MLCK was supposed to be connected to IO0 and not TXD0... That's why Q2 was added in the first place...

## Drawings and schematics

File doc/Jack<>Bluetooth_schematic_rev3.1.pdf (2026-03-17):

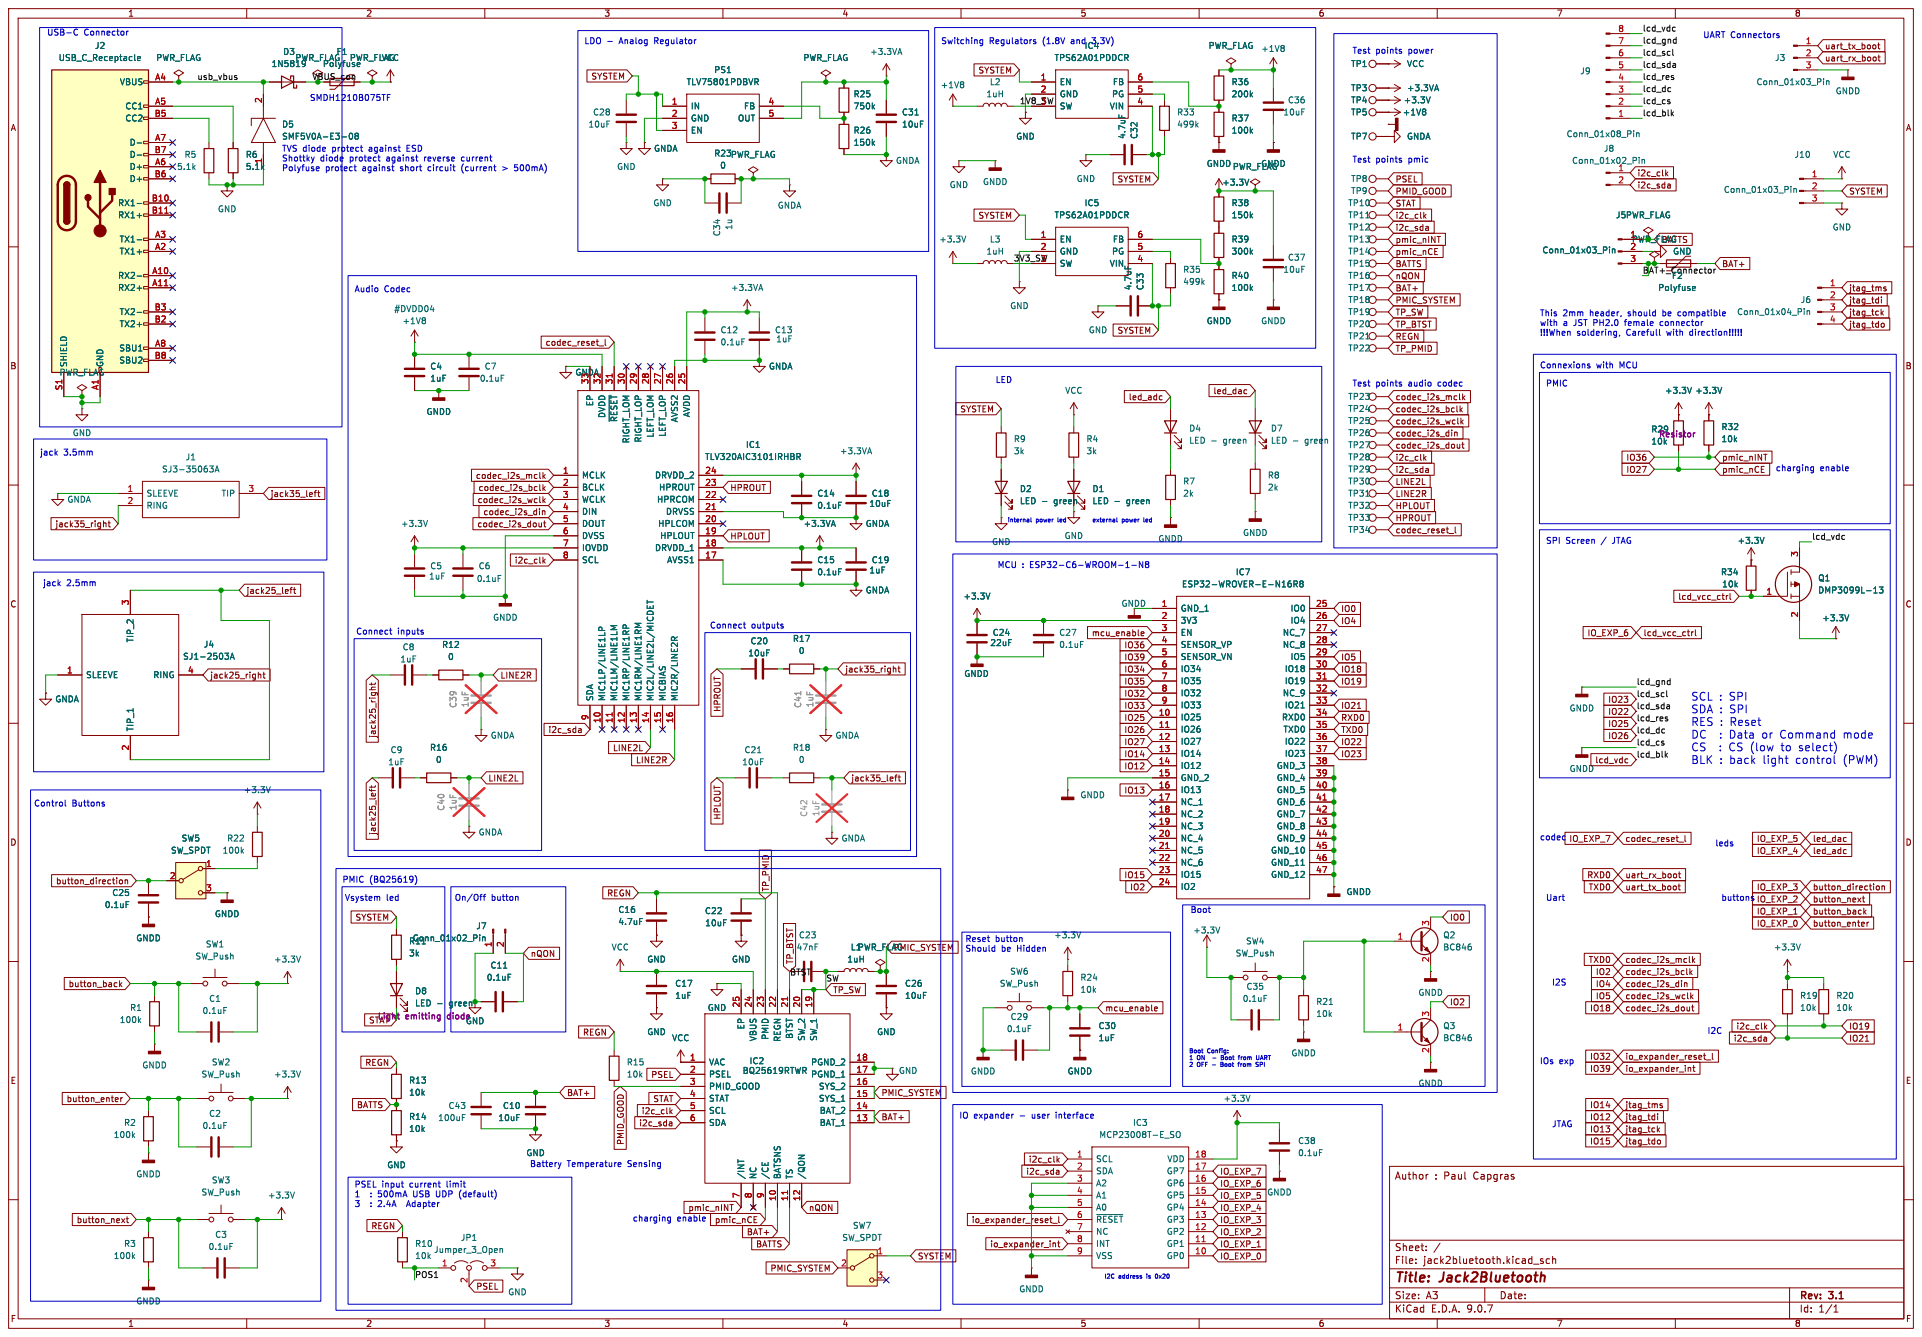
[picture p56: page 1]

Test points pmic USB-C Connector

Test points power Connect inputs

TVS diode protect against ESD

This 2mm header, should be compatible with a JST PH2.0 female connector

9 DVDD 32 MIC1LP/LINE1LP 10 ~{RESET}31 MIC1LM/LINE1LM 11 RIGHT_LOM 30 MIC1RP/LINE1RP 12 RIGHT_LOP 29 MIC1RM/LINE1RM 13 LEFT_LOM 28 MIC2L/LINE2L/MICDET 14 LEFT_LOP 27 MICBIAS 15 AVSS2 26 MIC2R/LINE2R 16 AVDD 25 DRVDD_2 24 HPROUT 23 HPRCOM 22 DRVSS 21 HPLCOM 20 HPLOUT 19 DRVDD_1 18 AVSS1 17

9 DVDD 32 MIC1LP/LINE1LP 10 ~{RESET}31 MIC1LM/LINE1LM 11 RIGHT_LOM 30 MIC1RP/LINE1RP 12 RIGHT_LOP 29 MIC1RM/LINE1RM 13 LEFT_LOM 28 MIC2L/LINE2L/MICDET 14 LEFT_LOP 27 MICBIAS 15 AVSS2 26 MIC2R/LINE2R 16 AVDD 25 DRVDD_2 24 HPROUT 23 HPRCOM 22 DRVSS 21 HPLCOM 20 HPLOUT 19 DRVDD_1 18 AVSS1 17 C18

SCL : SPI
SDA : SPI
RES : Reset
DC : Data or Command mode
CS : CS (low to select)

BLK : back light control (PWM) JTAG

9 REGN 22 BATSNS 10 BTST 21 TS 11 SW_2 20 /QON 12 SW_1 19 PGND_2 18 PGND_1 17 SYS_2 16 SYS_1 15 BAT_2 14 BAT_1 13 GND

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

2 OFF - Boot from SPI

IO expander - user interface

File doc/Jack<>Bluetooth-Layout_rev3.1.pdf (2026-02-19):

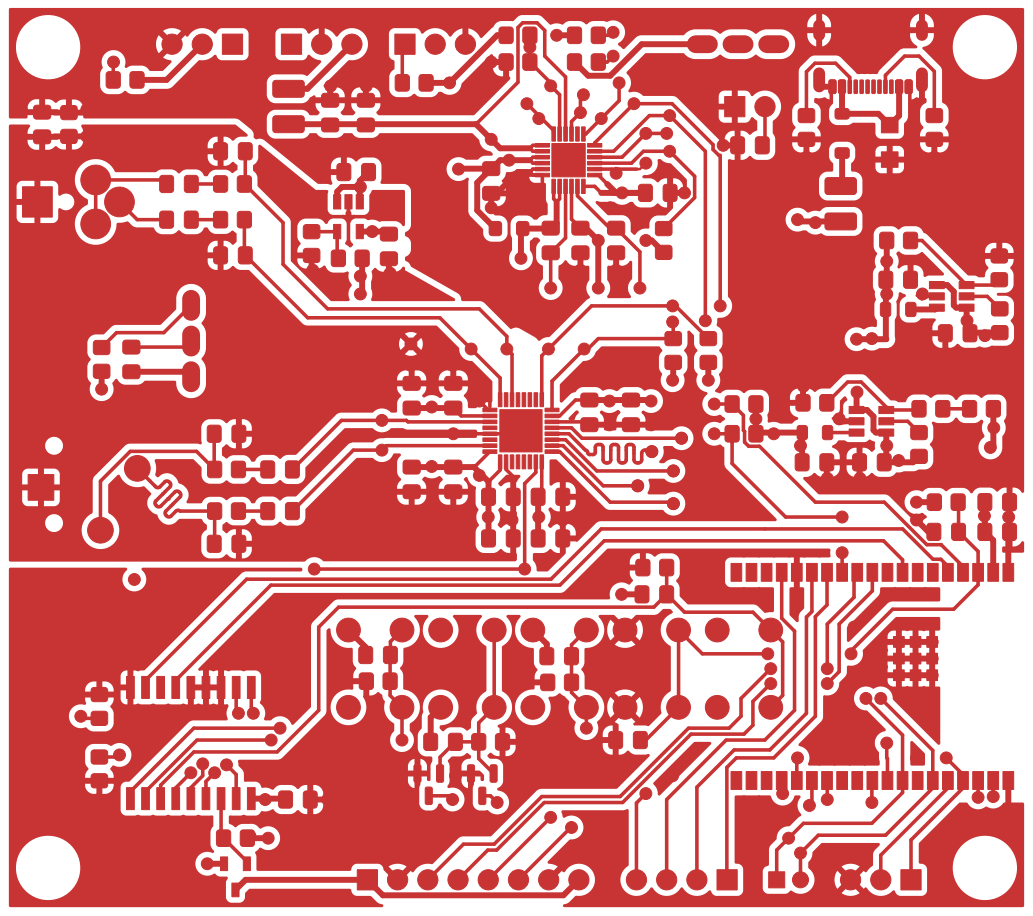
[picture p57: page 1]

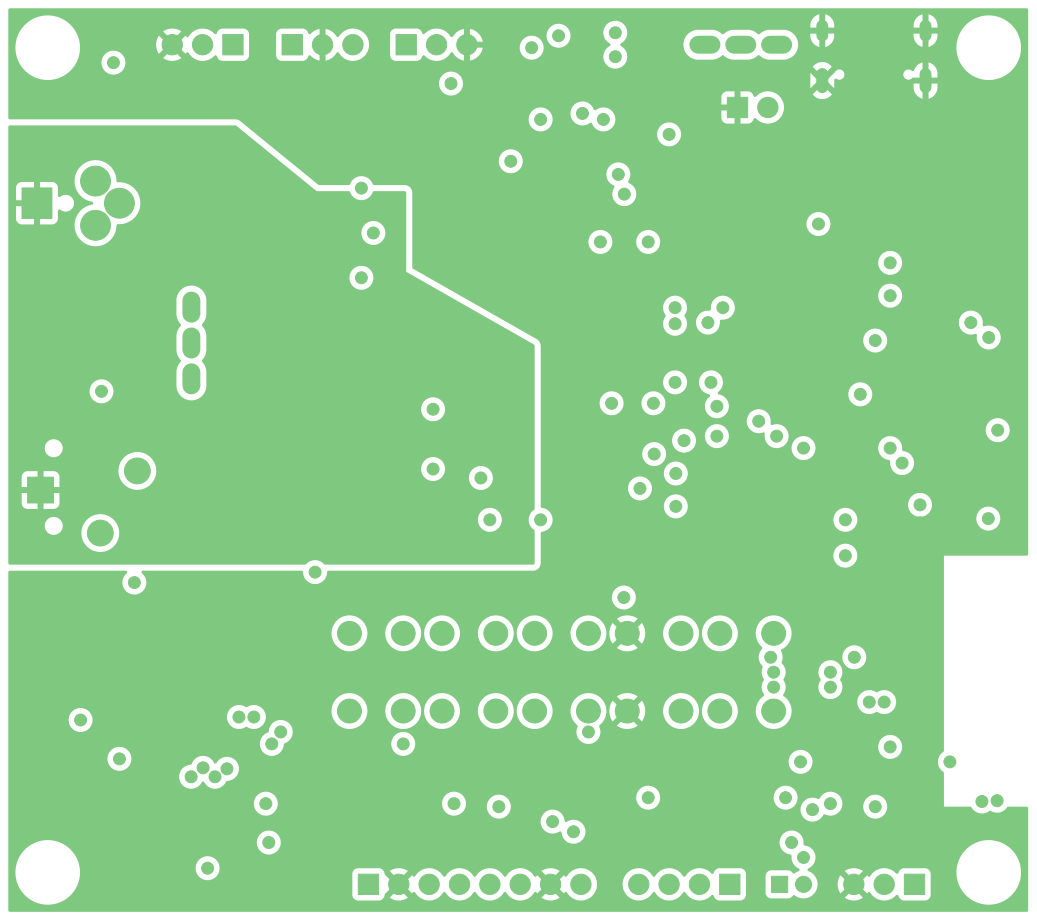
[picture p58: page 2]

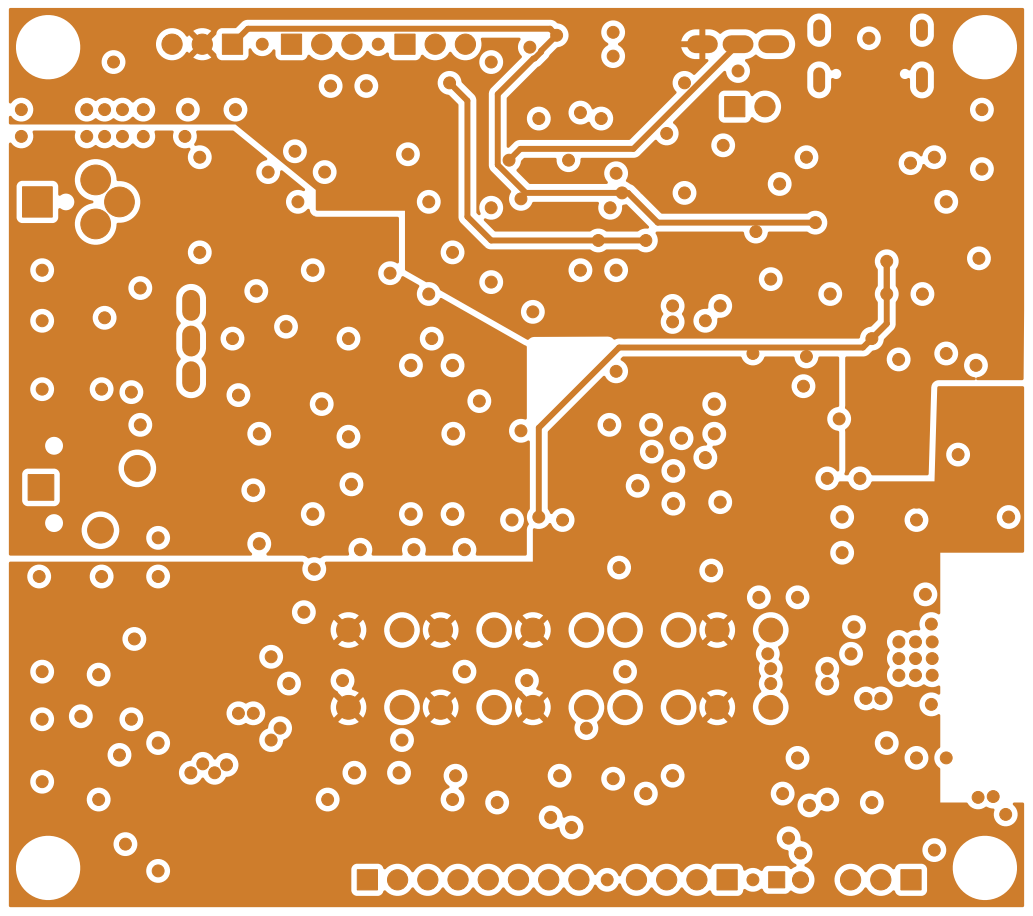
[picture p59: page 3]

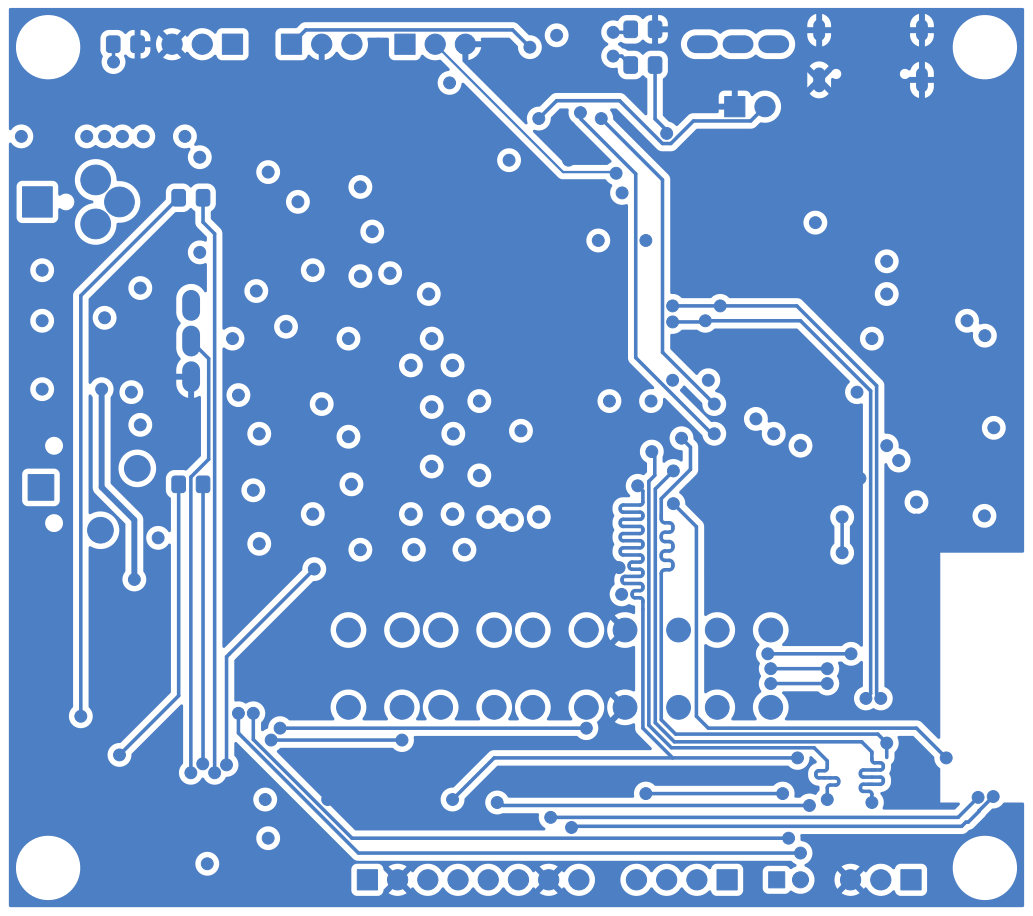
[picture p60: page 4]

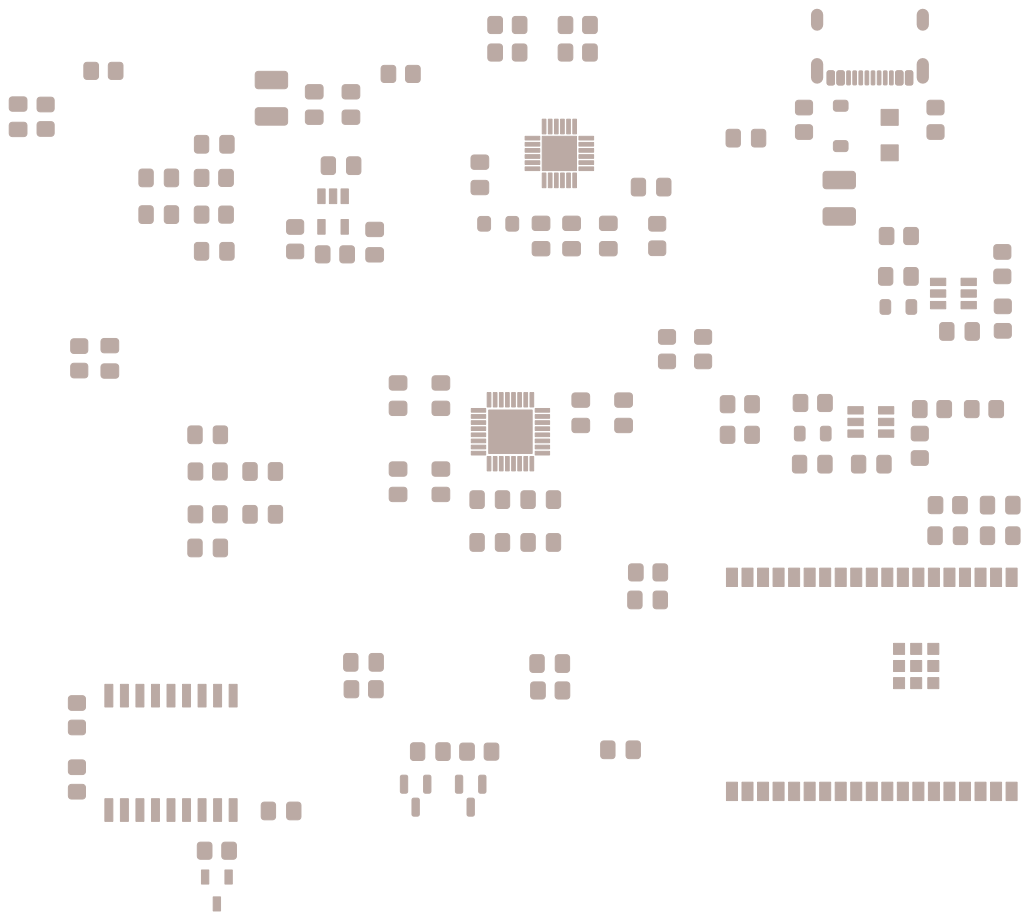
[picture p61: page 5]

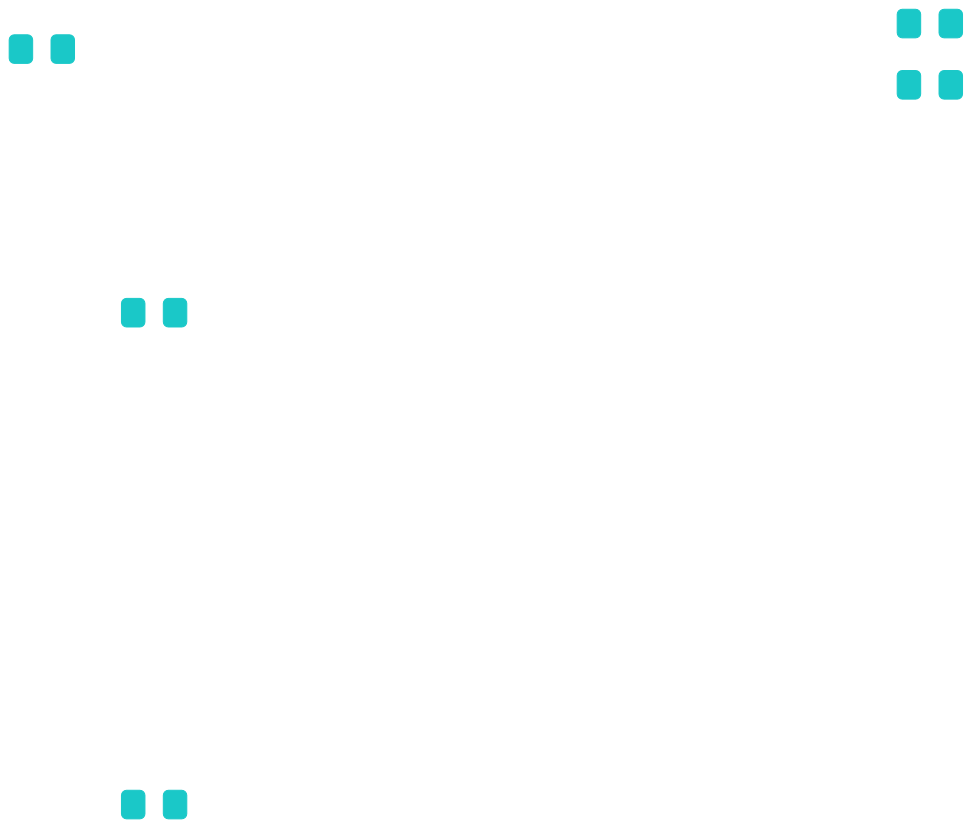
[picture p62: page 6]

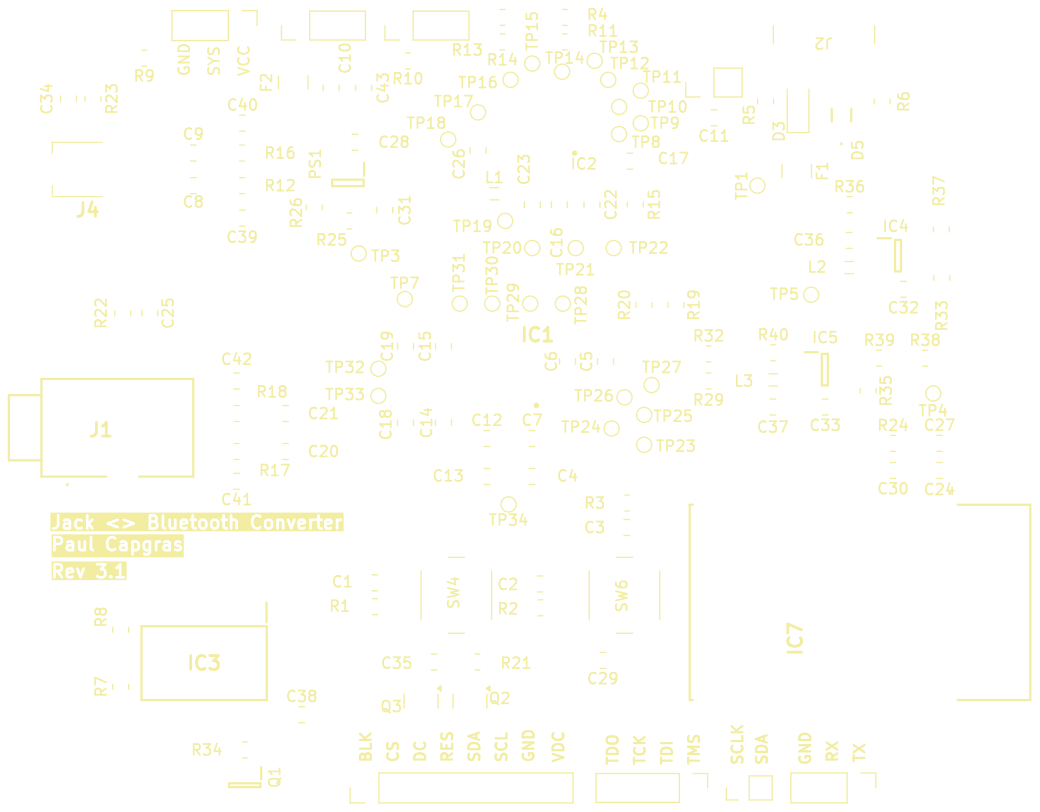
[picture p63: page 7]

SDA SCL VDC SCLK GND SYS DC TDI SDA TX GND TMS VCC BLK CSRES GND TDO TCK RX

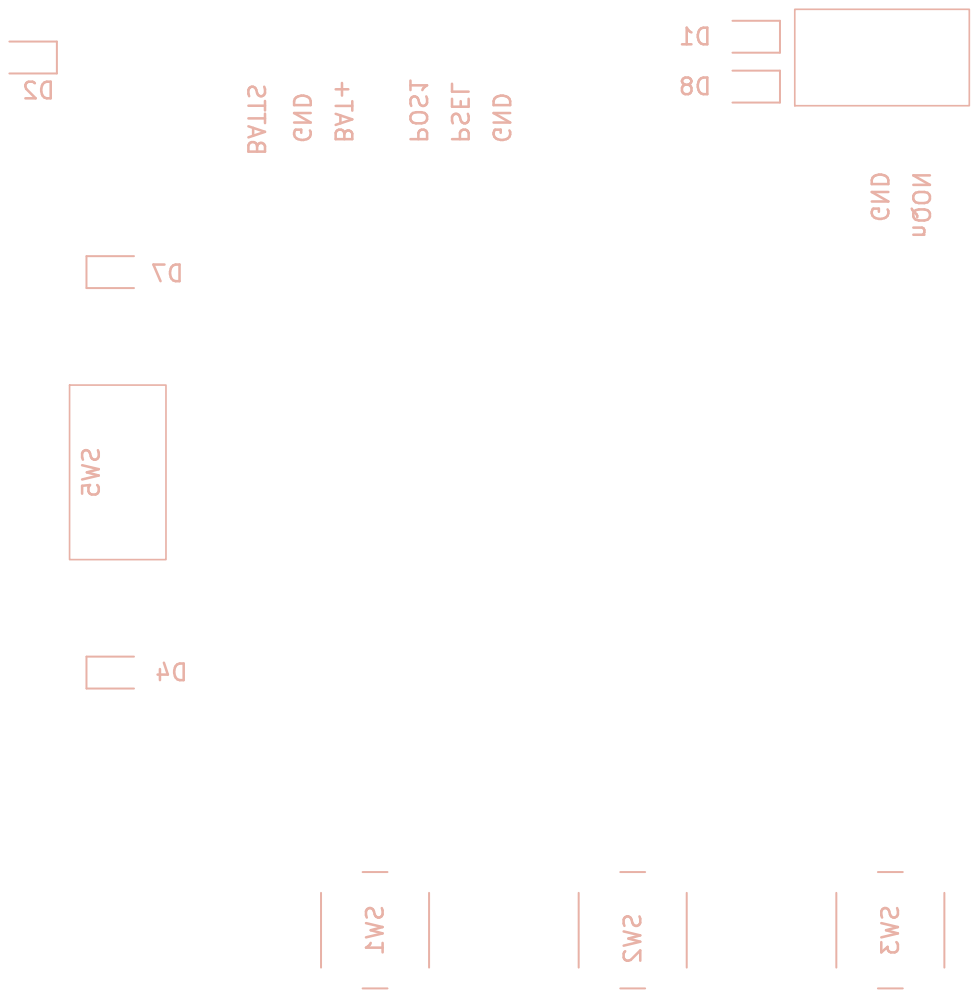
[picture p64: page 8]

BATTS PSEL GND GND nQON GND BAT+ POS1 D7 SW1 SW5 D2 D8 D1 SW3 SW2 D4

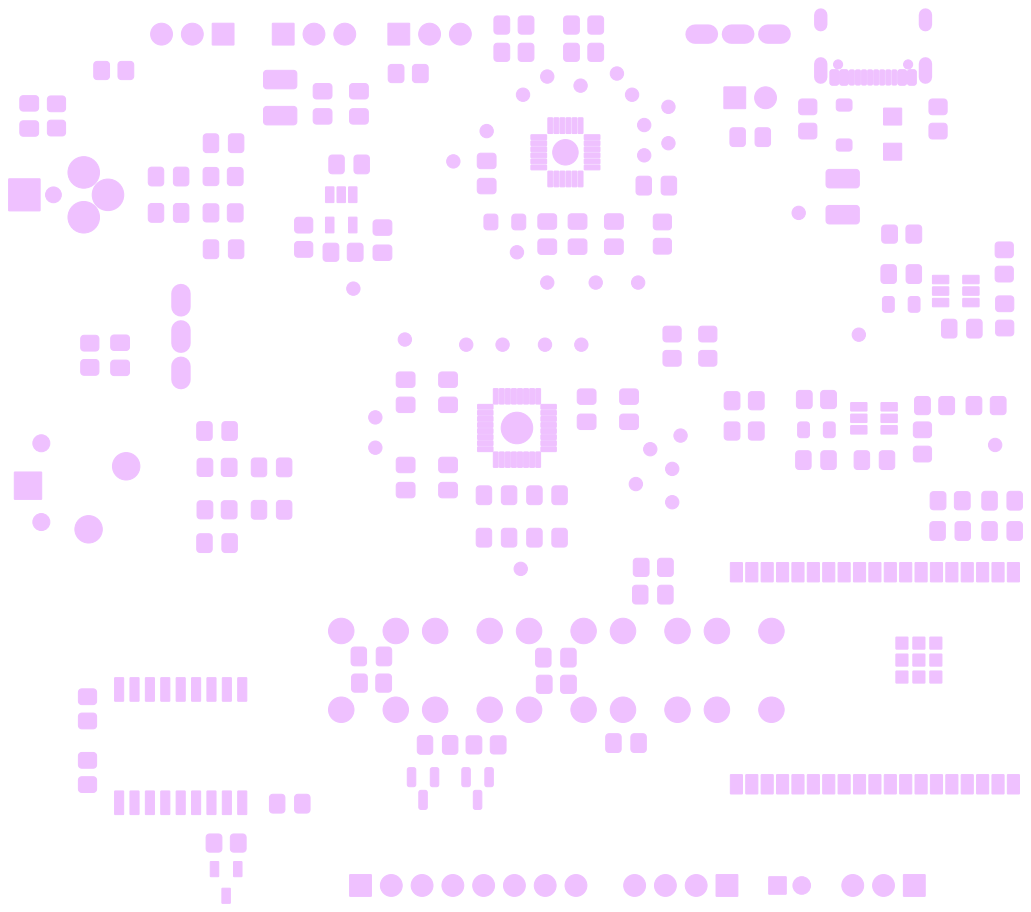
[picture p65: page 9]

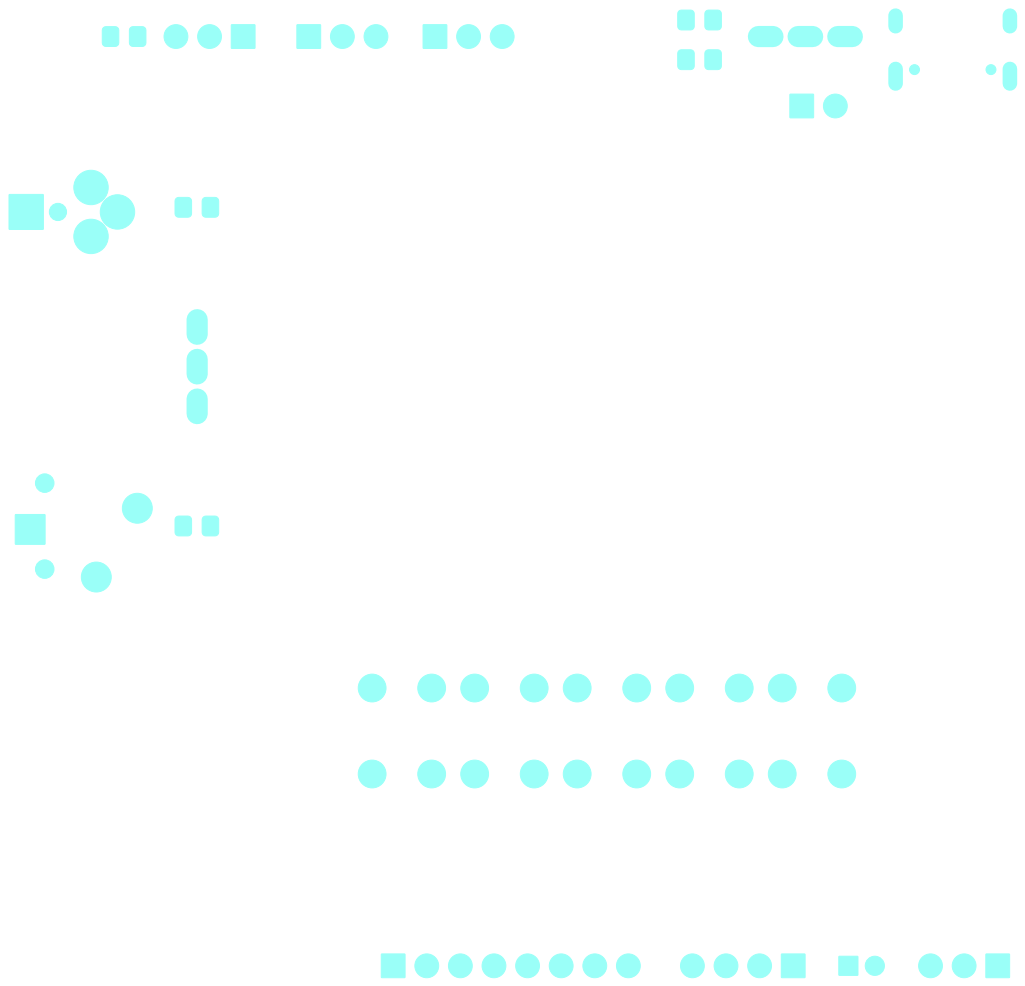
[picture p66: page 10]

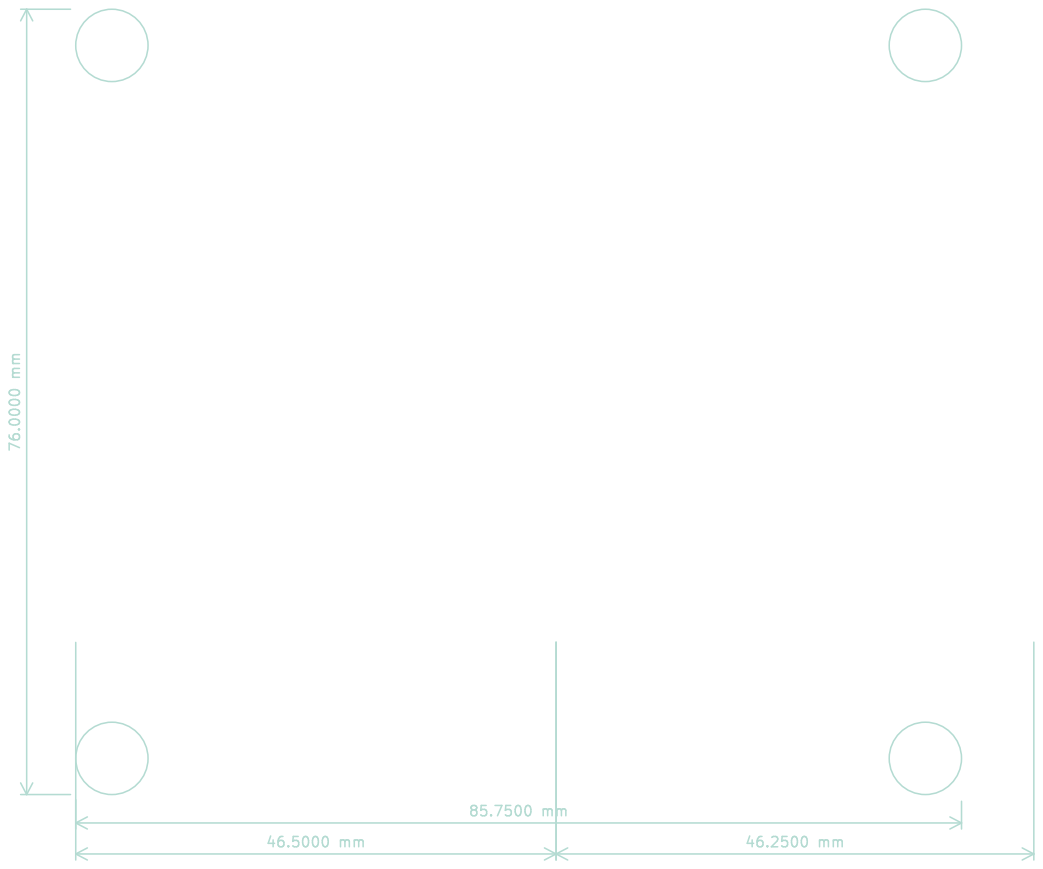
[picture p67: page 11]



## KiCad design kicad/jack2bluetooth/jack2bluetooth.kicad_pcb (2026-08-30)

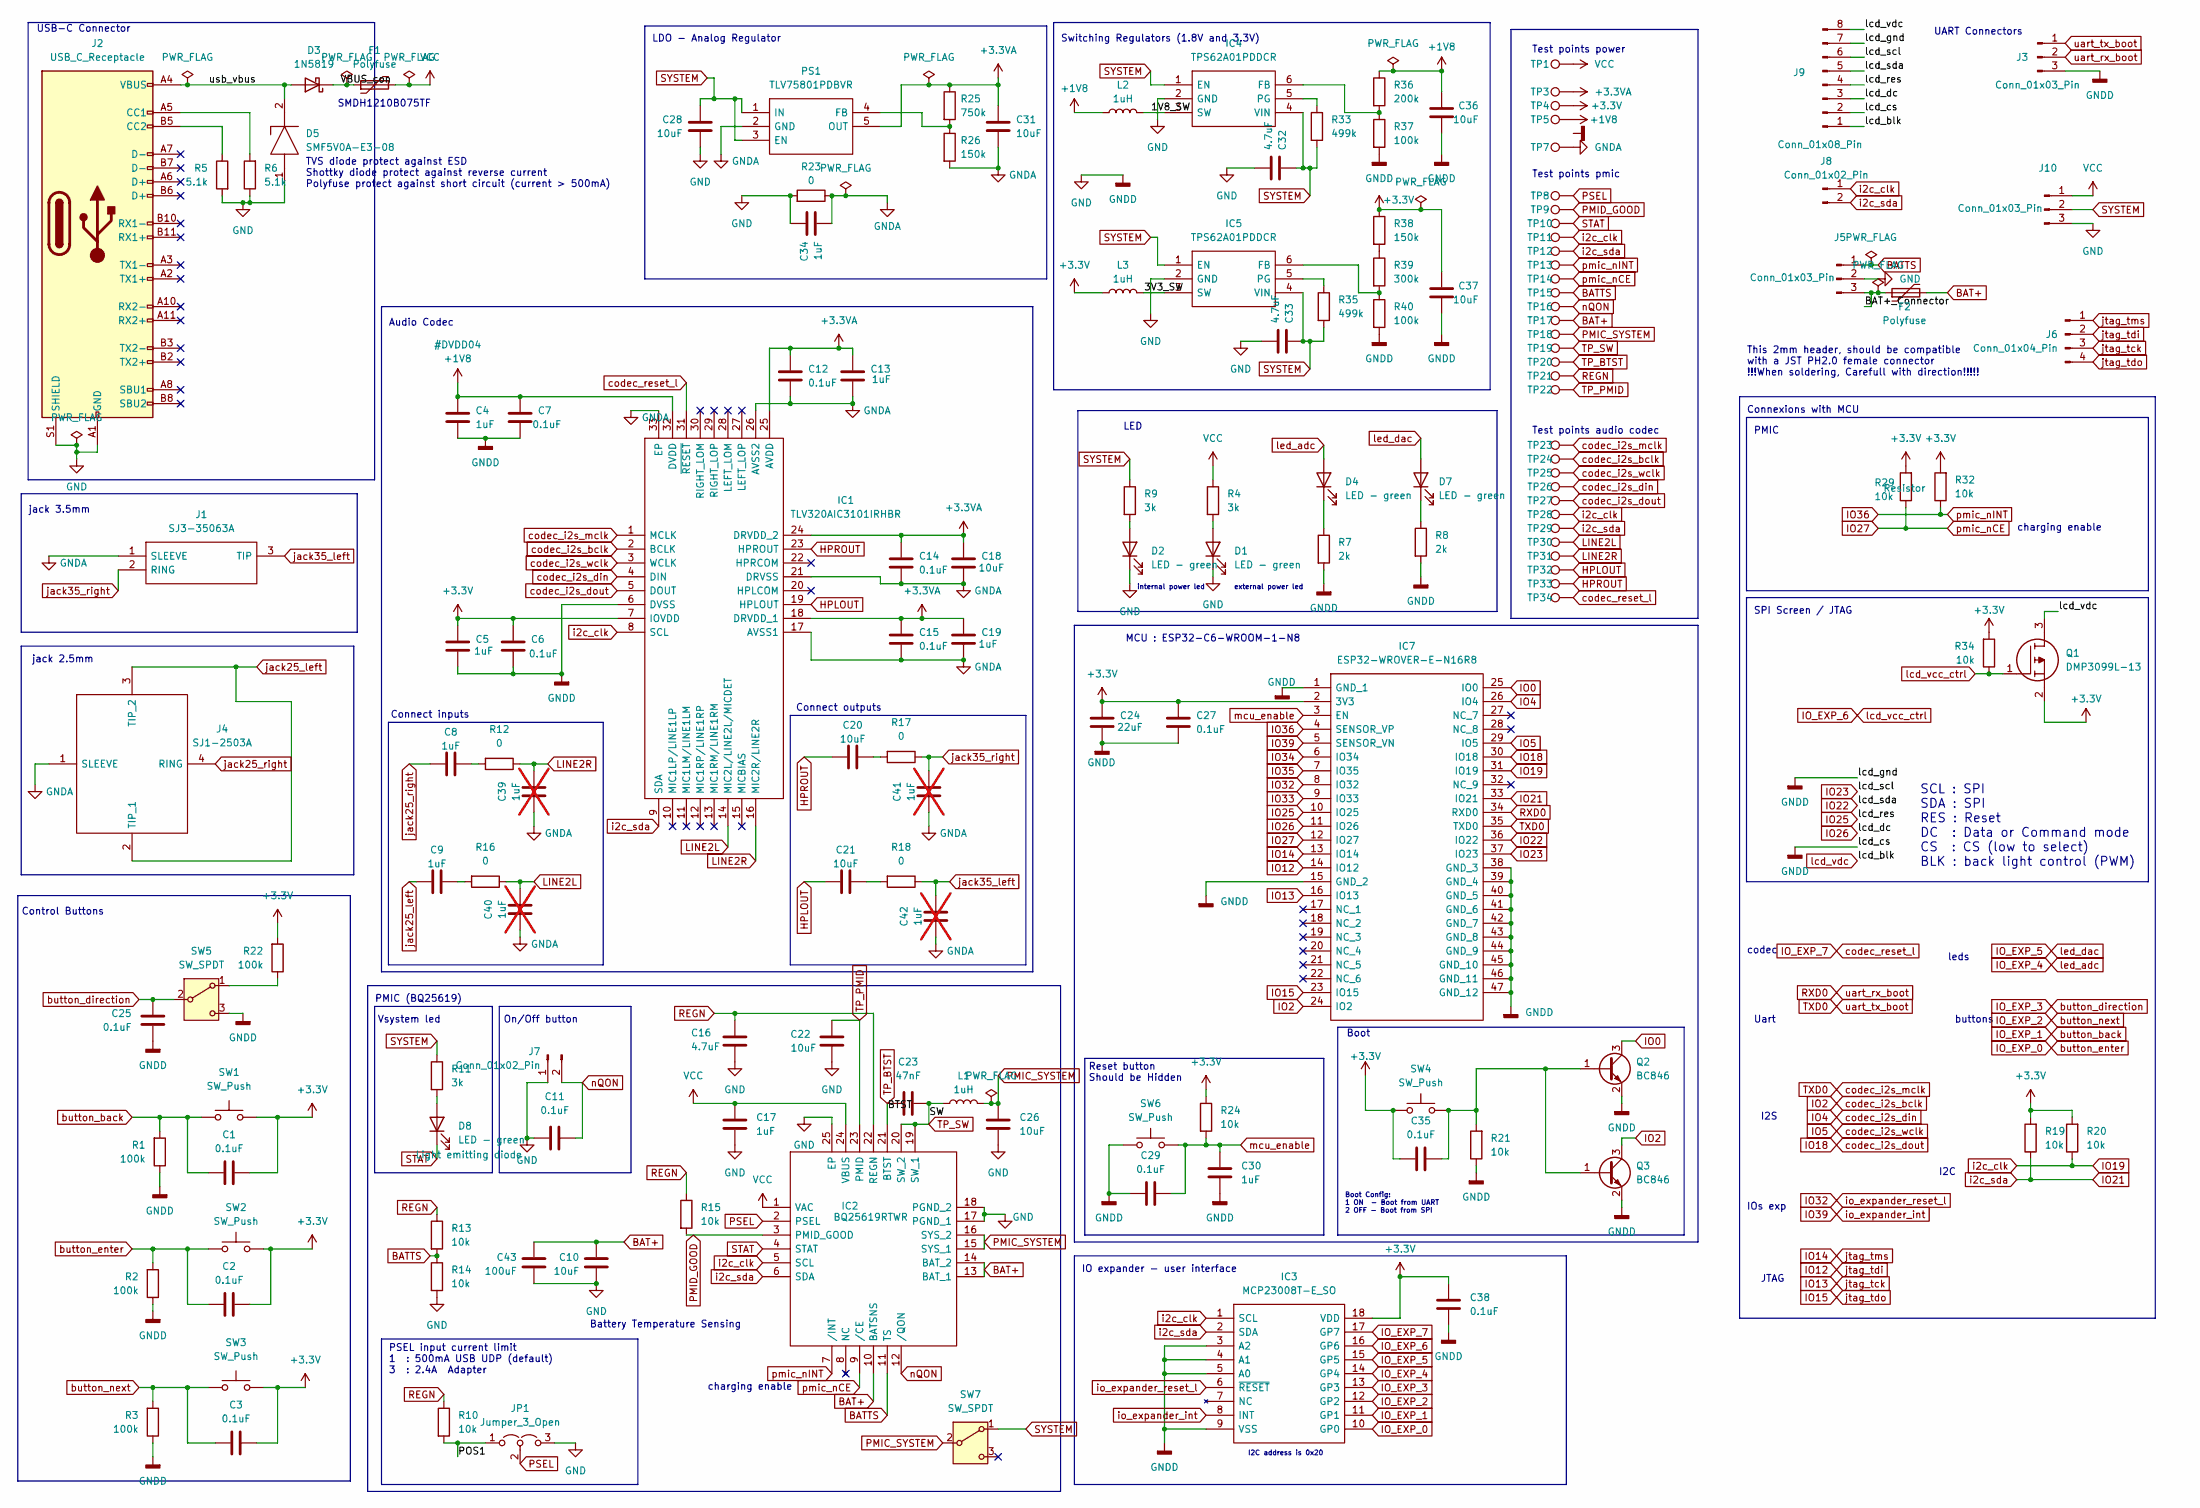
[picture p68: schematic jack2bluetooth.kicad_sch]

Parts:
C1, C2, C3, C6, C7, C11, C12, C14, C15, C25, C27, C29, C35, C38: 0.1uF; C_0805_2012Metric_Pad1.18x1.45mm_HandSolder
C4, C5, C8, C9, C13, C17, C19, C30, C34: 1uF; C_0805_2012Metric_Pad1.18x1.45mm_HandSolder
C10, C18, C20, C21, C22, C26, C28, C31, C36, C37: 10uF; C_0805_2012Metric_Pad1.18x1.45mm_HandSolder
C16, C32, C33: 4.7uF; C_0805_2012Metric_Pad1.18x1.45mm_HandSolder
C23: 47nF; C_0805_2012Metric_Pad1.18x1.45mm_HandSolder
C24: 22uF; C_0805_2012Metric_Pad1.18x1.45mm_HandSolder
C39, C40, C41, C42: 1uF; C_0805_2012Metric_Pad1.18x1.45mm_HandSolder; not fitted
C43: 100uF; C_0805_2012Metric_Pad1.18x1.45mm_HandSolder
D1, D2, D4, D7, D8: LED - green; LED_0805_2012Metric_Pad1.15x1.40mm_HandSolder
D3: 1N5819; D_SOD-123
D5: SMF5V0A-E3-08; SMF5V0AE308; Mouser Part Number 78-SMF5V0A-E3-08
F1, F2: Polyfuse; Fuse_1210_3225Metric_Pad1.42x2.65mm_HandSolder
IC1: TLV320AIC3101IRHBR; QFN50P500X500X100-33N-D; Mouser Part Number 595-T320AIC3101IRHBR
IC2: BQ25619RTWR; QFN50P400X400X80-25N-D; Mouser Part Number 595-BQ25619RTWR
IC3: MCP23008T-E_SO; SOIC127P1030X265-18N; Mouser Part Number 579-MCP23008T-E/SO
IC4, IC5: TPS62A01PDDCR; SOT95P280X110-6N; Manufacturer_Part_Number TPS62A01PDDCR
IC7: ESP32-WROVER-E-N16R8; ESP32WROVEREN16R8; Mouser Part Number 356-ESP32WRVE22864PC
J1: SJ3-35063A; SJ335063A; Mouser Part Number 179-SJ3-35063A
J2: USB_C_Receptacle; USB_C_Receptacle_GCT_USB4105-xx-A_16P_TopMnt_Horizontal
J3, J5, J10: Conn_01x03_Pin; PinHeader_1x03_P2.54mm_Vertical
J4: SJ1-2503A; SJ12503A; Mouser Part Number 490-SJ1-2503A
J6: Conn_01x04_Pin; PinHeader_1x04_P2.54mm_Vertical
J7: Conn_01x02_Pin; PinHeader_1x02_P2.54mm_Vertical
J8: Conn_01x02_Pin; PinHeader_1x02_P2.00mm_Vertical
J9: Conn_01x08_Pin; PinHeader_1x08_P2.54mm_Vertical
JP1: Jumper_3_Open; PinHeader_1x03_P2.54mm_Vertical
L1: 1uH; L_0805_2012Metric_Pad1.05x1.20mm_HandSolder
L2, L3: 1uH; L_0805_2012Metric
PS1: TLV75801PDBVR; SOT95P280X145-5N; Mouser Part Number 595-TLV75801PDBVR
Q1: DMP3099L-13; SOT96P240X115-3N; Mouser Part Number 621-DMP3099L-13
Q2, Q3: BC846; SOT-23
R1, R2, R3, R22, R37, R40: 100k; R_0805_2012Metric_Pad1.20x1.40mm_HandSolder
R4, R9, R11: 3k; R_0805_2012Metric_Pad1.20x1.40mm_HandSolder
R5, R6: 5.1k; R_0805_2012Metric_Pad1.20x1.40mm_HandSolder
R7, R8: 2k; R_0805_2012Metric_Pad1.20x1.40mm_HandSolder
R10, R13, R14, R15, R19, R20, R21, R24, R29, R32, R34: 10k; R_0805_2012Metric_Pad1.20x1.40mm_HandSolder
R12, R16, R17, R18, R23: 0; R_0805_2012Metric_Pad1.20x1.40mm_HandSolder
R25: 750k; R_0805_2012Metric_Pad1.20x1.40mm_HandSolder
R26, R38: 150k; R_0805_2012Metric_Pad1.20x1.40mm_HandSolder
R33, R35: 499k; R_0805_2012Metric_Pad1.20x1.40mm_HandSolder
R36: 200k; R_0805_2012Metric_Pad1.20x1.40mm_HandSolder
R39: 300k; R_0805_2012Metric_Pad1.20x1.40mm_HandSolder
SW1, SW2, SW3, SW4, SW6: SW_Push; SW_PUSH_6mm
SW5, SW7: SW_SPDT; SLW-105558-2A-N-D
TP1, TP3, TP4, TP5, TP7, TP8, TP9, TP10, TP11, TP12, TP13, TP14, TP15, TP16, TP17, TP18, TP19, TP20, TP21, TP22, TP23, TP24, TP25, TP26, TP27, TP28, TP29, TP30, TP31, TP32, TP33, TP34: TestPoint; TestPoint_Pad_D1.0mm

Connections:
+1V8: C4.1, C7.1, C36.1, IC1.32 (DVDD), L2.1, R36.1, TP5.1
+3.3V: C1.1, C2.1, C3.1, C5.1, C6.1, C24.1, C27.1, C35.2, C37.1, C38.1, IC1.7 (IOVDD), IC3.18 (VDD), IC7.2 (3V3), L3.1, Q1.2, R19.2, R20.2, R22.2, R24.1, R29.2, R32.2, R34.2, R38.1, SW1.2, SW2.2, SW3.2, SW4.1, TP4.1
+3.3VA: C12.1, C13.1, C14.1, C15.1, C18.1, C19.1, C31.1, IC1.18 (DRVDD_1), IC1.24 (DRVDD_2), IC1.25 (AVDD), PS1.5 (OUT), R25.1, TP3.1
/1V8_SW: IC4.3 (SW), L2.2
/3V3_SW: IC5.3 (SW), L3.2
/BAT+_Connector: F2.1, J5.3
/POS1: JP1.1 (A), R10.2
/VBUS_con: D3.1 (K), F1.1
/usb_vbus: D3.2 (A), D5.2, J2.A4 (VBUS), J2.A9 (VBUS), J2.B4 (VBUS), J2.B9 (VBUS)
BAT+: C10.1, C43.1, F2.2, IC2.10 (BATSNS), IC2.13 (BAT_1), IC2.14 (BAT_2), TP17.1
BATTS: IC2.11 (TS), J5.1, R13.2, R14.1, TP15.1
GND: C4.2, C5.2, C6.2, C7.2, C10.2, C11.2, C16.1, C17.2, C22.1, C24.2, C25.2, C26.1, C27.2, C28.2, C29.2, C30.2, C32.2, C33.2, C34.1, C36.2, C37.2, C38.2, C43.2, D1.1 (K), D2.1 (K), D5.1, IC1.6 (DVSS), IC2.17 (PGND_1), IC2.18 (PGND_2), IC2.25 (EP), IC3.3 (A2), IC3.4 (A1), IC3.5 (A0), IC3.9 (VSS), IC4.2 (GND), IC5.2 (GND), IC7.1 (GND_1), IC7.15 (GND_2), IC7.38 (GND_3), IC7.39 (GND_4), IC7.40 (GND_5), IC7.41 (GND_6), IC7.42 (GND_7), IC7.43 (GND_8), IC7.44 (GND_9), IC7.45 (GND_10), IC7.46 (GND_11), IC7.47 (GND_12), J2.A1 (GND), J2.A12 (GND), J2.B1 (GND), J2.B12 (GND), J2.S1 (SHIELD), J3.3, J5.2, J7.1, J9.2, J9.7, J10.3, JP1.3 (B), Q2.2 (E), Q3.2 (E), R1.1, R2.1, R3.1, R5.2, R6.1, R7.2, R8.2, R14.2, R21.1, R23.2, R37.2, R40.2, SW5.3 (C), SW6.1
GNDA: C12.2, C13.2, C14.2, C15.2, C18.2, C19.2, C31.2, C34.2, C39.1, C40.1, C41.1, C42.1, IC1.17 (AVSS1), IC1.21 (DRVSS), IC1.26 (AVSS2), IC1.33 (EP), J1.1 (SLEEVE), J4.1 (SLEEVE), PS1.2 (GND), R23.1, R26.2, TP7.1
HPLOUT: C21.1, IC1.19 (HPLOUT), TP32.1
HPROUT: C20.1, IC1.23 (HPROUT), TP33.1
IO0: IC7.25 (IO0), Q2.3 (C)
IO2: IC1.2 (BCLK), IC7.24 (IO2), Q3.3 (C), TP24.1
IO4: IC1.4 (DIN), IC7.26 (IO4), TP26.1
IO5: IC1.3 (WCLK), IC7.29 (IO5), TP25.1
IO12: IC7.14 (IO12), J6.2
IO13: IC7.16 (IO13), J6.3
IO14: IC7.13 (IO14), J6.1
IO15: IC7.23 (IO15), J6.4
IO18: IC1.5 (DOUT), IC7.30 (IO18), TP27.1
IO19: IC1.8 (SCL), IC2.5 (SCL), IC3.1 (SCL), IC7.31 (IO19), J8.1, R20.1, TP11.1, TP28.1
IO21: IC1.9 (SDA), IC2.6 (SDA), IC3.2 (SDA), IC7.33 (IO21), J8.2, R19.1, TP12.1, TP29.1
IO22: IC7.36 (IO22), J9.5
IO23: IC7.37 (IO23), J9.6
IO25: IC7.10 (IO25), J9.4
IO26: IC7.11 (IO26), J9.3
IO27: IC2.9 (/CE), IC7.12 (IO27), R29.1, TP14.1
IO32: IC3.6 (~RESET), IC7.8 (IO32)
IO33: IC7.9 (IO33)
IO34: IC7.6 (IO34)
IO35: IC7.7 (IO35)
IO36: IC2.7 (/INT), IC7.4 (SENSOR_VP), R32.1, TP13.1
IO39: IC3.8 (INT), IC7.5 (SENSOR_VN)
IO_EXP_0: C2.2, IC3.10 (GP0), R2.2, SW2.1
IO_EXP_1: C1.2, IC3.11 (GP1), R1.2, SW1.1
IO_EXP_2: C3.2, IC3.12 (GP2), R3.2, SW3.1
IO_EXP_3: C25.1, IC3.13 (GP3), SW5.2 (B)
IO_EXP_4: D4.2 (A), IC3.14 (GP4)
IO_EXP_5: D7.2 (A), IC3.15 (GP5)
IO_EXP_6: IC3.16 (GP6), Q1.1, R34.1
IO_EXP_7: IC1.31 (~RESET), IC3.17 (GP7), TP34.1
LINE2L: C40.2, IC1.14 (MIC2L/LINE2L/MICDET), R16.1, TP30.1
LINE2R: C39.2, IC1.16 (MIC2R/LINE2R), R12.1, TP31.1
unnamed: C8.2, R12.2
unnamed: C9.2, R16.2
unnamed: C20.2, R17.2
unnamed: C21.2, R18.2
unnamed: D1.2 (A), R4.2
unnamed: D2.2 (A), R9.2
unnamed: D4.1 (K), R7.1
unnamed: D7.1 (K), R8.1
unnamed: D8.2 (A), R11.2
unnamed: IC4.6 (FB), R36.2, R37.1
unnamed: IC4.5 (PG), R33.1
unnamed: IC5.6 (FB), R39.2, R40.1
unnamed: IC5.5 (PG), R35.1
unnamed: J2.A5 (CC1), R6.2
unnamed: J2.B5 (CC2), R5.1
unnamed: PS1.4 (FB), R25.2, R26.1
unnamed: C35.1, Q2.1 (B), Q3.1 (B), R21.2, SW4.2
unnamed: R38.2, R39.1
unnamed: R22.1, SW5.1 (A)
PMIC_SYSTEM: C26.2, IC2.15 (SYS_1), IC2.16 (SYS_2), L1.2, SW7.2 (B), TP18.1
PMID_GOOD: IC2.3 (PMID_GOOD), R15.2, TP9.1
PSEL: IC2.2 (PSEL), JP1.2 (C), TP8.1
REGN: C16.2, IC2.22 (REGN), R10.1, R13.1, R15.1, TP21.1
RXD0: IC7.34 (RXD0), J3.2
STAT: D8.1 (K), IC2.4 (STAT), TP10.1
SYSTEM: C28.1, C32.1, C33.1, IC4.1 (EN), IC4.4 (VIN), IC5.1 (EN), IC5.4 (VIN), J10.2, PS1.1 (IN), PS1.3 (EN), R9.1, R11.1, R33.2, R35.2, SW7.1 (A)
TP_BTST: C23.1, IC2.21 (BTST), TP20.1
TP_PMID: C22.2, IC2.23 (PMID), TP22.1
TP_SW: C23.2, IC2.19 (SW_1), IC2.20 (SW_2), L1.1, TP19.1
TXD0: IC1.1 (MCLK), IC7.35 (TXD0), J3.1, TP23.1
VCC: C17.1, F1.2, IC2.1 (VAC), IC2.24 (VBUS), J10.1, R4.1, TP1.1
jack25_left: C9.1, J4.2 (TIP_1), J4.3 (TIP_2)
jack25_right: C8.1, J4.4 (RING)
jack35_left: C42.2, J1.3 (TIP), R18.1
jack35_right: C41.2, J1.2 (RING), R17.1
lcd_vdc: J9.1, J9.8, Q1.3
mcu_enable: C29.1, C30.1, IC7.3 (EN), R24.2, SW6.2
nQON: C11.1, IC2.12 (/QON), J7.2, TP16.1

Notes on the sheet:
jack 2.5mm
TVS diode protect against ESD Shottky diode protect against reverse current Polyfuse protect against short circuit (current > 500mA)
external power led
Battery Temperature Sensing
codec
charging enable
SCL : SPI SDA : SPI RES : Reset DC : Data or Command mode CS : CS (low to select) BLK : back light control (PWM)
Test points audio codec
IO expander - user interface
Switching Regulators (1.8V and 3.3V)
MCU : ESP32-C6-WROOM-1-N8
Boot Config: 1 ON - Boot from UART 2 OFF - Boot from SPI
On/Off button
jack 3.5mm
This 2mm header, should be compatible with a JST PH2.0 female connector !!!When soldering, Carefull with direction!!!!!
Control Buttons
UART Connectors
Reset button Should be Hidden
Test points pmic
buttons
Test points power
Audio Codec
I2C address is 0x20
internal power led
Connect outputs
I2C
PMIC (BQ25619)
Connexions with MCU
USB-C Connector
SPI Screen / JTAG
I2S
JTAG
PMIC
PSEL input current limit 1 : 500mA USB UDP (default) 3 : 2.4A Adapter
Boot
LDO - Analog Regulator
Uart
SMDH1210B075TF
Connect inputs
IOs exp

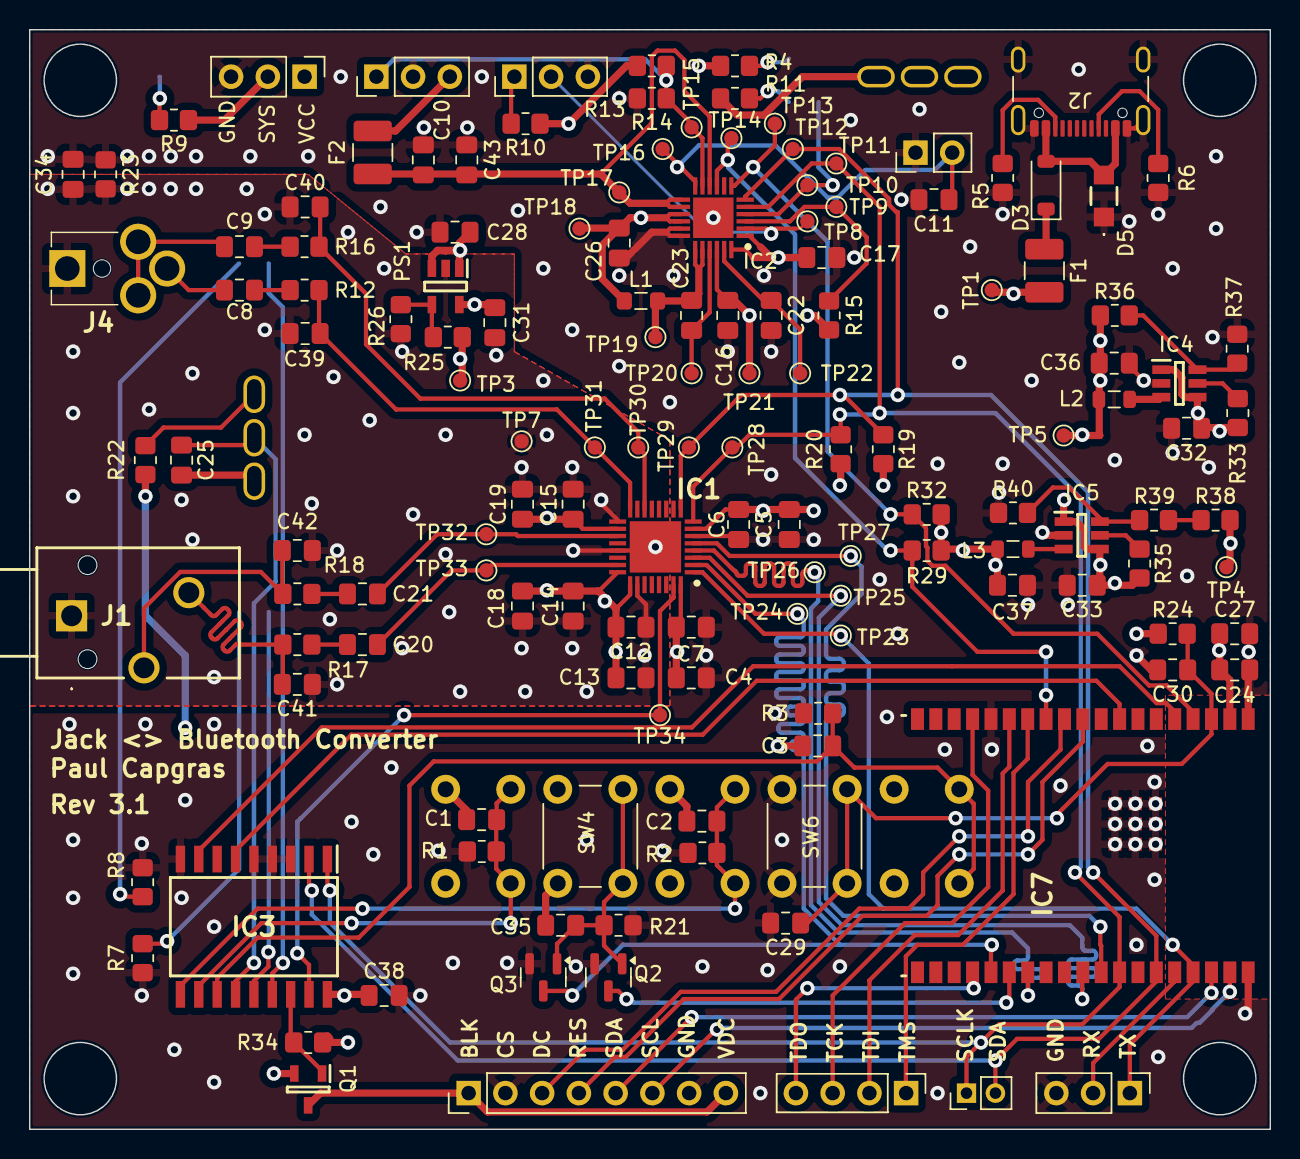
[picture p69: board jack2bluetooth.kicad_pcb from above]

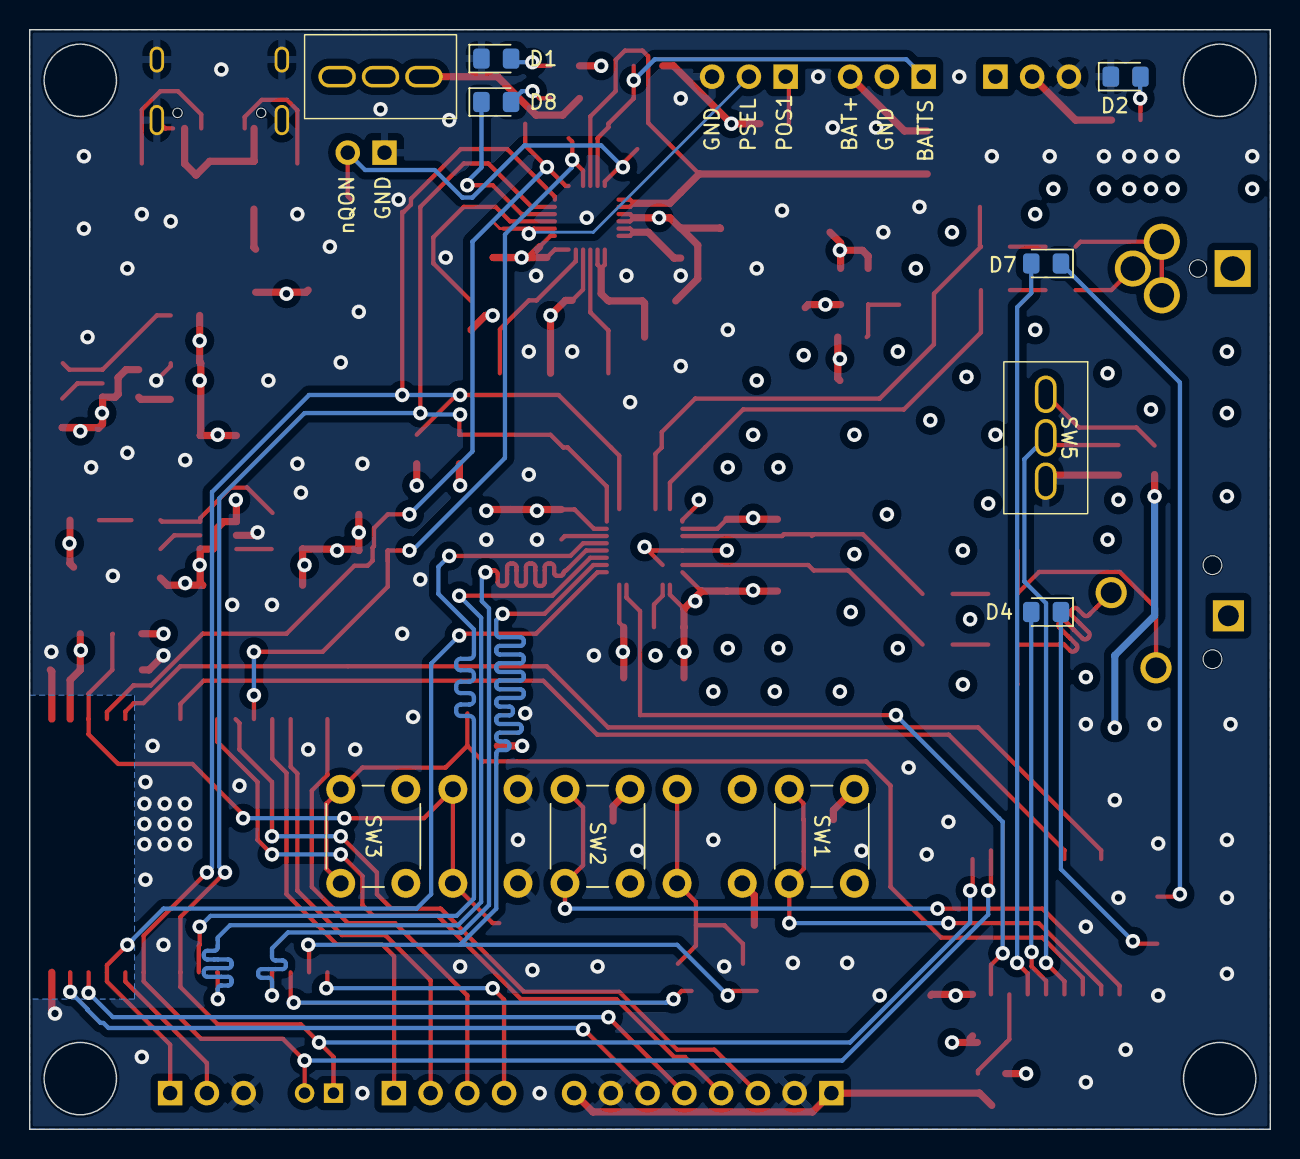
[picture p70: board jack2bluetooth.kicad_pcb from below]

Board: 4 copper layers, 85.8 x 76.0 mm, 151 parts (10 on the bottom side), 82 nets.

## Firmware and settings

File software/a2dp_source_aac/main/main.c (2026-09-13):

/*
 * SPDX-FileCopyrightText: 2026 Espressif Systems (Shanghai) CO LTD
 *
 * SPDX-License-Identifier: Unlicense OR CC0-1.0
 */

#include <stdio.h>
#include <stdlib.h>
#include <string.h>
#include <inttypes.h>
#include "freertos/FreeRTOS.h"
#include "freertos/task.h"
#include "freertos/timers.h"
#include "nvs.h"
#include "nvs_flash.h"
#include "esp_system.h"
#include "esp_log.h"

#include "esp_bt.h"
#include "esp_bt_main.h"
#include "esp_bt_device.h"
#include "esp_gap_bt_api.h"
#include "esp_a2dp_api.h"
#include "esp_avrc_api.h"
#include "bt_app_core.h"
#include "decode_task.h"

/* log tags */
#define BT_AV_TAG "BT_AV"
#define BT_RC_CT_TAG "RC_CT"

/* device name */
#define LOCAL_DEVICE_NAME "ESP_A2DP_SRC"

/* AVRCP used transaction label */
#define APP_RC_CT_TL_GET_CAPS (0)
#define APP_RC_CT_TL_RN_VOLUME_CHANGE (1)

enum
{
    BT_APP_STACK_UP_EVT = 0x0000,   /* event for stack up */
    BT_APP_HEART_BEAT_EVT = 0xff00, /* event for heart beat */
};

/* A2DP global states */
enum
{
    APP_AV_STATE_IDLE,
    APP_AV_STATE_DISCOVERING,
    APP_AV_STATE_DISCOVERED,
    APP_AV_STATE_UNCONNECTED,
    APP_AV_STATE_CONNECTING,
    APP_AV_STATE_CONNECTED,
    APP_AV_STATE_DISCONNECTING,
};

/* sub states of APP_AV_STATE_CONNECTED */
enum
{
    APP_AV_MEDIA_STATE_IDLE,
    APP_AV_MEDIA_STATE_STARTING,
    APP_AV_MEDIA_STATE_STARTED,
    APP_AV_MEDIA_STATE_STOPPING,
};

/*********************************
 * STATIC FUNCTION DECLARATIONS
 ********************************/

/* handler for bluetooth stack enabled events */
static void bt_av_hdl_stack_evt(uint16_t event, void *p_param);

/* avrc controller event handler */
static void bt_av_hdl_avrc_ct_evt(uint16_t event, void *p_param);

/* GAP callback function */
static void bt_app_gap_cb(esp_bt_gap_cb_event_t event, esp_bt_gap_cb_param_t *param);

/* callback function for A2DP source */
static void bt_app_a2d_cb(esp_a2d_cb_event_t event, esp_a2d_cb_param_t *param);

/* callback function for AVRCP controller */
static void bt_app_rc_ct_cb(esp_avrc_ct_cb_event_t event, esp_avrc_ct_cb_param_t *param);

/* handler for heart beat timer */
static void bt_app_a2d_heart_beat(TimerHandle_t arg);

/* A2DP application state machine */
static void bt_app_av_sm_hdlr(uint16_t event, void *param);

/* utils for transfer BLuetooth Deveice Address into string form */
static char *bda2str(esp_bd_addr_t bda, char *str, size_t size);

/* A2DP application state machine handler for each state */
static void bt_app_av_state_unconnected_hdlr(uint16_t event, void *param);
static void bt_app_av_state_connecting_hdlr(uint16_t event, void *param);
static void bt_app_av_state_connected_hdlr(uint16_t event, void *param);
static void bt_app_av_state_disconnecting_hdlr(uint16_t event, void *param);

/*********************************
 * STATIC VARIABLE DEFINITIONS
 ********************************/

static esp_bd_addr_t s_peer_bda = {0};                       /* Bluetooth Device Address of peer device*/
static uint8_t s_peer_bdname[ESP_BT_GAP_MAX_BDNAME_LEN + 1]; /* Bluetooth Device Name of peer device*/
static int s_a2d_state = APP_AV_STATE_IDLE;                  /* A2DP global state */
static int s_media_state = APP_AV_MEDIA_STATE_IDLE;          /* sub states of APP_AV_STATE_CONNECTED */
static int s_intv_cnt = 0;                                   /* count of heart beat intervals */
static int s_connecting_intv = 0;                            /* count of heart beat intervals for connecting */
static uint32_t s_pkt_cnt = 0;                               /* count of packets */
static esp_avrc_rn_evt_cap_mask_t s_avrc_peer_rn_cap;        /* AVRC target notification event capability bit mask */
static TimerHandle_t s_tmr;                                  /* handle of heart beat timer */
static esp_a2d_conn_hdl_t s_a2d_conn_hndl = 0;
static uint16_t s_a2d_audio_mtu;

static const char remote_device_name[] = "Bose-Paul-2";

/*********************************
 * STATIC FUNCTION DEFINITIONS
 ********************************/

static char *bda2str(esp_bd_addr_t bda, char *str, size_t size)
{
    if (bda == NULL || str == NULL || size < 18)
    {
        return NULL;
    }

    sprintf(str, "%02x:%02x:%02x:%02x:%02x:%02x",
            bda[0], bda[1], bda[2], bda[3], bda[4], bda[5]);
    return str;
}

static bool get_name_from_eir(uint8_t *eir, uint8_t *bdname, uint8_t *bdname_len)
{
    uint8_t *rmt_bdname = NULL;
    uint8_t rmt_bdname_len = 0;

    if (!eir)
    {
        return false;
    }

    /* get complete or short local name from eir data */
    rmt_bdname = esp_bt_gap_resolve_eir_data(eir, ESP_BT_EIR_TYPE_CMPL_LOCAL_NAME, &rmt_bdname_len);
    if (!rmt_bdname)
    {
        rmt_bdname = esp_bt_gap_resolve_eir_data(eir, ESP_BT_EIR_TYPE_SHORT_LOCAL_NAME, &rmt_bdname_len);
    }

    if (rmt_bdname)
    {
        if (rmt_bdname_len > ESP_BT_GAP_MAX_BDNAME_LEN)
        {
            rmt_bdname_len = ESP_BT_GAP_MAX_BDNAME_LEN;
        }

        if (bdname)
        {
            memcpy(bdname, rmt_bdname, rmt_bdname_len);
            bdname[rmt_bdname_len] = '\0';
        }
        if (bdname_len)
        {
            *bdname_len = rmt_bdname_len;
        }
        return true;
    }

    return false;
}

static void filter_inquiry_scan_result(esp_bt_gap_cb_param_t *param)
{
    char bda_str[18];
    uint32_t cod = 0;    /* class of device */
    int32_t rssi = -129; /* invalid value */
    uint8_t *eir = NULL;
    esp_bt_gap_dev_prop_t *p;

    /* handle the discovery results */
    ESP_LOGI(BT_AV_TAG, "Scanned device: %s", bda2str(param->disc_res.bda, bda_str, 18));
    for (int i = 0; i < param->disc_res.num_prop; i++)
    {
        p = param->disc_res.prop + i;
        switch (p->type)
        {
        case ESP_BT_GAP_DEV_PROP_COD:
            cod = *(uint32_t *)(p->val);
            ESP_LOGI(BT_AV_TAG, "--Class of Device: 0x%" PRIx32, cod);
            break;
        case ESP_BT_GAP_DEV_PROP_RSSI:
            rssi = *(int8_t *)(p->val);
            ESP_LOGI(BT_AV_TAG, "--RSSI: %" PRId32, rssi);
            break;
        case ESP_BT_GAP_DEV_PROP_EIR:
            eir = (uint8_t *)(p->val);
            break;
        case ESP_BT_GAP_DEV_PROP_BDNAME:
        default:
            break;
        }
    }

    /* search for device with MAJOR service class as "rendering" in COD */
    if (!esp_bt_gap_is_valid_cod(cod) ||
        !(esp_bt_gap_get_cod_srvc(cod) & ESP_BT_COD_SRVC_RENDERING))
    {
        return;
    }

    /* search for target device in its Extended Inqury Response */
    if (eir)
    {
        get_name_from_eir(eir, s_peer_bdname, NULL);
        if (strcmp((char *)s_peer_bdname, remote_device_name) == 0)
        {
            ESP_LOGI(BT_AV_TAG, "Found a target device, address %s, name %s", bda_str, s_peer_bdname);
            s_a2d_state = APP_AV_STATE_DISCOVERED;
            memcpy(s_peer_bda, param->disc_res.bda, ESP_BD_ADDR_LEN);
            ESP_LOGI(BT_AV_TAG, "Cancel device discovery ...");
            esp_bt_gap_cancel_discovery();
        }
    }
}

static void bt_app_encode_stream_stop(void)
{
    if (encode_task_is_running())
    {
        ESP_LOGI(BT_AV_TAG, "stopping encode stream task");
        encode_task_stop();
    }
}

static void bt_app_gap_cb(esp_bt_gap_cb_event_t event, esp_bt_gap_cb_param_t *param)
{
    switch (event)
    {
    /* when device discovered a result, this event comes */
    case ESP_BT_GAP_DISC_RES_EVT:
    {
        if (s_a2d_state == APP_AV_STATE_DISCOVERING)
        {
            filter_inquiry_scan_result(param);
        }
        break;
    }
    /* when discovery state changed, this event comes */
    case ESP_BT_GAP_DISC_STATE_CHANGED_EVT:
    {
        if (param->disc_st_chg.state == ESP_BT_GAP_DISCOVERY_STOPPED)
        {
            if (s_a2d_state == APP_AV_STATE_DISCOVERED)
            {
                s_a2d_state = APP_AV_STATE_CONNECTING;
                ESP_LOGI(BT_AV_TAG, "Device discovery stopped.");
                ESP_LOGI(BT_AV_TAG, "a2dp connecting to peer: %s", s_peer_bdname);
                /* connect source to peer device specified by Bluetooth Device Address */
                esp_a2d_source_connect(s_peer_bda);
            }
            else
            {
                /* not discovered, continue to discover */
                ESP_LOGI(BT_AV_TAG, "Device discovery failed, continue to discover...");
                esp_bt_gap_start_discovery(ESP_BT_INQ_MODE_GENERAL_INQUIRY, 10, 0);
            }
        }
        else if (param->disc_st_chg.state == ESP_BT_GAP_DISCOVERY_STARTED)
        {
            ESP_LOGI(BT_AV_TAG, "Discovery started.");
        }
        break;
    }
    /* when authentication completed, this event comes */
    case ESP_BT_GAP_AUTH_CMPL_EVT:
    {
        if (param->auth_cmpl.stat == ESP_BT_STATUS_SUCCESS)
        {
            ESP_LOGI(BT_AV_TAG, "authentication success: %s", param->auth_cmpl.device_name);
            ESP_LOG_BUFFER_HEX(BT_AV_TAG, param->auth_cmpl.bda, ESP_BD_ADDR_LEN);
        }
        else
        {
            ESP_LOGE(BT_AV_TAG, "authentication failed, status: %d", param->auth_cmpl.stat);
        }
        break;
    }
    /* when Legacy Pairing pin code requested, this event comes */
    case ESP_BT_GAP_PIN_REQ_EVT:
    {
        ESP_LOGI(BT_AV_TAG, "ESP_BT_GAP_PIN_REQ_EVT min_16_digit: %d", param->pin_req.min_16_digit);
        if (param->pin_req.min_16_digit)
        {
            ESP_LOGI(BT_AV_TAG, "Input pin code: 0000 0000 0000 0000");
            esp_bt_pin_code_t pin_code = {0};
            esp_bt_gap_pin_reply(param->pin_req.bda, true, 16, pin_code);
        }
        else
        {
            ESP_LOGI(BT_AV_TAG, "Input pin code: 1234");
            esp_bt_pin_code_t pin_code;
            pin_code[0] = '1';
            pin_code[1] = '2';
            pin_code[2] = '3';
            pin_code[3] = '4';
            esp_bt_gap_pin_reply(param->pin_req.bda, true, 4, pin_code);
        }
        break;
    }

#if (CONFIG_EXAMPLE_SSP_ENABLED == true)
    /* when Security Simple Pairing user confirmation requested, this event comes */
    case ESP_BT_GAP_CFM_REQ_EVT:
        ESP_LOGI(BT_AV_TAG, "ESP_BT_GAP_CFM_REQ_EVT Please compare the numeric value: %06" PRIu32, param->cfm_req.num_val);
        esp_bt_gap_ssp_confirm_reply(param->cfm_req.bda, true);
        break;
    /* when Security Simple Pairing passkey notified, this event comes */
    case ESP_BT_GAP_KEY_NOTIF_EVT:
        ESP_LOGI(BT_AV_TAG, "ESP_BT_GAP_KEY_NOTIF_EVT passkey: %06" PRIu32, param->key_notif.passkey);
        break;
    /* when Security Simple Pairing passkey requested, this event comes */
    case ESP_BT_GAP_KEY_REQ_EVT:
        ESP_LOGI(BT_AV_TAG, "ESP_BT_GAP_KEY_REQ_EVT Please enter passkey!");
        break;
#endif

    /* when GAP mode changed, this event comes */
    case ESP_BT_GAP_MODE_CHG_EVT:
        ESP_LOGI(BT_AV_TAG, "ESP_BT_GAP_MODE_CHG_EVT mode: %d", param->mode_chg.mode);
        break;
    case ESP_BT_GAP_GET_DEV_NAME_CMPL_EVT:
        if (param->get_dev_name_cmpl.status == ESP_BT_STATUS_SUCCESS)
        {
            ESP_LOGI(BT_AV_TAG, "ESP_BT_GAP_GET_DEV_NAME_CMPL_EVT device name: %s", param->get_dev_name_cmpl.name);
        }
        else
        {
            ESP_LOGI(BT_AV_TAG, "ESP_BT_GAP_GET_DEV_NAME_CMPL_EVT failed, state: %d", param->get_dev_name_cmpl.status);
        }
        break;
    /* other */
    default:
    {
        ESP_LOGI(BT_AV_TAG, "event: %d", event);
        break;
    }
    }

    return;
}

static void bt_app_register_a2dp_src_seps(void)
{
    esp_a2d_mcc_t mcc_aac = {0};
    mcc_aac.type = ESP_A2D_MCT_M24;
    mcc_aac.cie.m24_info.drc = ESP_A2D_M24_CIE_DRC_NS;
    mcc_aac.cie.m24_info.obj_type = ESP_A2D_M24_CIE_OBJ_TYPE_2_AAC_LC |
                                    ESP_A2D_M24_CIE_OBJ_TYPE_4_AAC_LC;
    mcc_aac.cie.m24_info.samp_freq1 = ESP_A2D_M24_CIE_SF1_8K |
                                      ESP_A2D_M24_CIE_SF1_11K |
                                      ESP_A2D_M24_CIE_SF1_12K |
                                      ESP_A2D_M24_CIE_SF1_16K |
                                      ESP_A2D_M24_CIE_SF1_22K |
                                      ESP_A2D_M24_CIE_SF1_24K |
                                      ESP_A2D_M24_CIE_SF1_32K |
                                      ESP_A2D_M24_CIE_SF1_44K;
    mcc_aac.cie.m24_info.samp_freq2 = ESP_A2D_M24_CIE_SF2_48K |
                                      ESP_A2D_M24_CIE_SF2_64K |
                                      ESP_A2D_M24_CIE_SF2_88K |
                                      ESP_A2D_M24_CIE_SF2_96K;
    mcc_aac.cie.m24_info.ch = ESP_A2D_M24_CIE_CH_1 |
                              ESP_A2D_M24_CIE_CH_2;
    mcc_aac.cie.m24_info.vbr = ESP_A2D_M24_CIE_VBR_SUPPORT;
    /* bit rate: 160000 */
    mcc_aac.cie.m24_info.br1 = 0x02 & ESP_A2D_M24_CIE_BR1_MSK;
    mcc_aac.cie.m24_info.br2 = 0x71 & ESP_A2D_M24_CIE_BR2_MSK;
    mcc_aac.cie.m24_info.br3 = 0x00 & ESP_A2D_M24_CIE_BR3_MSK;
    esp_err_t err = esp_a2d_source_register_stream_endpoint(0, &mcc_aac);
    if (err != ESP_OK)
    {
        ESP_LOGE(BT_AV_TAG, "esp_a2d_source_register_stream_endpoint_aac failed with code %x", err);
    }
    else
    {
        ESP_LOGI(BT_AV_TAG, "esp_a2d_source_register_stream_endpoint_aac completed successfully.");
    }

    esp_a2d_mcc_t mcc_sbc = {0};
    mcc_sbc.type = ESP_A2D_MCT_SBC;
    mcc_sbc.cie.sbc_info.samp_freq = ESP_A2D_SBC_CIE_SF_16K |
                                     ESP_A2D_SBC_CIE_SF_32K |
                                     ESP_A2D_SBC_CIE_SF_44K |
                                     ESP_A2D_SBC_CIE_SF_48K;
    mcc_sbc.cie.sbc_info.ch_mode = ESP_A2D_SBC_CIE_CH_MODE_MONO |
                                   ESP_A2D_SBC_CIE_CH_MODE_DUAL_CHANNEL |
                                   ESP_A2D_SBC_CIE_CH_MODE_STEREO |
                                   ESP_A2D_SBC_CIE_CH_MODE_JOINT_STEREO;
    mcc_sbc.cie.sbc_info.block_len = ESP_A2D_SBC_CIE_BLOCK_LEN_4 |
                                     ESP_A2D_SBC_CIE_BLOCK_LEN_8 |
                                     ESP_A2D_SBC_CIE_BLOCK_LEN_12 |
                                     ESP_A2D_SBC_CIE_BLOCK_LEN_16;
    mcc_sbc.cie.sbc_info.num_subbands = ESP_A2D_SBC_CIE_NUM_SUBBANDS_4 | ESP_A2D_SBC_CIE_NUM_SUBBANDS_8;
    mcc_sbc.cie.sbc_info.alloc_mthd = ESP_A2D_SBC_CIE_ALLOC_MTHD_SNR | ESP_A2D_SBC_CIE_ALLOC_MTHD_LOUDNESS;
    mcc_sbc.cie.sbc_info.min_bitpool = 2;
    mcc_sbc.cie.sbc_info.max_bitpool = 250;
    err = esp_a2d_source_register_stream_endpoint(1, &mcc_sbc);
    if (err != ESP_OK)
    {
        ESP_LOGE(BT_AV_TAG, "esp_a2d_source_register_stream_endpoint_sbc failed with code %x", err);
    }
    else
    {
        ESP_LOGI(BT_AV_TAG, "esp_a2d_source_register_stream_endpoint_sbc completed successfully.");
    }
}

static void bt_av_hdl_stack_evt(uint16_t event, void *p_param)
{
    ESP_LOGD(BT_AV_TAG, "%s event: %d", __func__, event);

    switch (event)
    {
    /* when stack up worked, this event comes */
    case BT_APP_STACK_UP_EVT:
    {
        char *dev_name = LOCAL_DEVICE_NAME;
        esp_err_t err;
        err = esp_bt_gap_set_device_name(dev_name);
        if (err != ESP_OK)
        {
            ESP_LOGE(BT_AV_TAG, "esp_bt_gap_set_device_name failed with code %x", err);
        }
        err = esp_bt_gap_register_callback(bt_app_gap_cb);
        if (err != ESP_OK)
        {
            ESP_LOGE(BT_AV_TAG, "esp_bt_gap_register_callback failed with code %x", err);
        }

        err = esp_avrc_ct_init();
        if (err != ESP_OK)
        {
            ESP_LOGE(BT_AV_TAG, "esp_avrc_ct_init failed with code %x", err);
        }
        err = esp_avrc_ct_register_callback(bt_app_rc_ct_cb);
        if (err != ESP_OK)
        {
            ESP_LOGE(BT_AV_TAG, "esp_avrc_ct_register_callback failed with code %x", err);
        }

        err = esp_a2d_source_init();
        if (err != ESP_OK)
        {
            ESP_LOGE(BT_AV_TAG, "esp_a2d_source_init failed with code %x", err);
        }
        err = esp_a2d_register_callback(&bt_app_a2d_cb);
        if (err != ESP_OK)
        {
            ESP_LOGE(BT_AV_TAG, "esp_a2d_register_callback failed with code %x", err);
        }

        /* Avoid the state error of s_a2d_state caused by the connection initiated by the peer device. */
        err = esp_bt_gap_set_scan_mode(ESP_BT_NON_CONNECTABLE, ESP_BT_NON_DISCOVERABLE);
        if (err != ESP_OK)
        {
            ESP_LOGE(BT_AV_TAG, "esp_a2d_register_callback failed with code %x", err);
        }
        err = esp_bt_gap_get_device_name();
        if (err != ESP_OK)
        {
            ESP_LOGE(BT_AV_TAG, "esp_a2d_register_callback failed with code %x", err);
        }

        ESP_LOGI(BT_AV_TAG, "Starting device discovery...");
        s_a2d_state = APP_AV_STATE_DISCOVERING;
        err = esp_bt_gap_start_discovery(ESP_BT_INQ_MODE_GENERAL_INQUIRY, 10, 0);
        if (err != ESP_OK)
        {
            ESP_LOGE(BT_AV_TAG, "esp_a2d_register_callback failed with code %x", err);
        }

        /* create and start heart beat timer */
        do
        {
            int tmr_id = 0;
            s_tmr = xTimerCreate("connTmr", (10000 / portTICK_PERIOD_MS),
                                 pdTRUE, (void *)&tmr_id, bt_app_a2d_heart_beat);
            xTimerStart(s_tmr, portMAX_DELAY);
        } while (0);
        break;
    }
    /* other */
    default:
    {
        ESP_LOGE(BT_AV_TAG, "%s unhandled event: %d", __func__, event);
        break;
    }
    }
}

static void bt_app_a2d_cb(esp_a2d_cb_event_t event, esp_a2d_cb_param_t *param)
{
    if (event == ESP_A2D_REPORT_SNK_ALL_CODEC_CAPS_EVT)
    {
        uint8_t n =
            param->a2d_report_snk_all_codec_caps_stat.sep_num;

        esp_a2d_sep_mcc_t *seps =
            param->a2d_report_snk_all_codec_caps_stat.sep_mcc;

        ESP_LOGI(BT_AV_TAG,
                 "All sink capabilities: conn_hdl=%u sep_num=%u",
                 (unsigned)param
                     ->a2d_report_snk_all_codec_caps_stat.conn_hdl,
                 (unsigned)n);

        for (uint8_t i = 0; i < n; i++)
        {
            ESP_LOGI(BT_AV_TAG,
                     "Sink SEP[%u]: seid=%u codec=%u",
                     (unsigned)i,
                     (unsigned)seps[i].seid,
                     (unsigned)seps[i].mcc.type);
        }
    }

    if (event == ESP_A2D_SEP_REG_STATE_EVT)
    {
        ESP_LOGW(
            BT_AV_TAG,
            "LOCAL SEP REGISTRATION: seid=%u state=%u",
            (unsigned)param->a2d_sep_reg_stat.seid,
            (unsigned)param->a2d_sep_reg_stat.reg_state);
    }

    if (event == ESP_A2D_PROF_STATE_EVT)
    {
        ESP_LOGI(BT_AV_TAG,
                 "A2DP profile state: %u",
                 (unsigned)param->a2d_prof_stat.init_state);

        if (param->a2d_prof_stat.init_state ==
            ESP_A2D_INIT_SUCCESS)
        {
            ESP_LOGI(BT_AV_TAG,
                     "A2DP initialized; registering endpoints");

            bt_app_register_a2dp_src_seps();
        }
    }

    bt_app_work_dispatch(bt_app_av_sm_hdlr, event, param, sizeof(esp_a2d_cb_param_t), NULL, NULL);
}

static void bt_app_a2d_heart_beat(TimerHandle_t arg)
{
    bt_app_work_dispatch(bt_app_av_sm_hdlr, BT_APP_HEART_BEAT_EVT, NULL, 0, NULL, NULL);
}
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
void app_main(void)
{
    char bda_str[18] = {0};
    /* initialize NVS — it is used to store PHY calibration data */
    esp_err_t ret = nvs_flash_init();
    if (ret == ESP_ERR_NVS_NO_FREE_PAGES || ret == ESP_ERR_NVS_NEW_VERSION_FOUND)
    {
        ESP_ERROR_CHECK(nvs_flash_erase());
        ret = nvs_flash_init();
    }
    ESP_ERROR_CHECK(ret);

    /*
     * This example only uses the functions of Classical Bluetooth.
     * So release the controller memory for Bluetooth Low Energy.
     */
    ESP_ERROR_CHECK(esp_bt_controller_mem_release(ESP_BT_MODE_BLE));

    esp_bt_controller_config_t bt_cfg = BT_CONTROLLER_INIT_CONFIG_DEFAULT();
    if (esp_bt_controller_init(&bt_cfg) != ESP_OK)
    {
        ESP_LOGE(BT_AV_TAG, "%s initialize controller failed", __func__);
        return;
    }
    if (esp_bt_controller_enable(ESP_BT_MODE_CLASSIC_BT) != ESP_OK)
    {
        ESP_LOGE(BT_AV_TAG, "%s enable controller failed", __func__);
        return;
    }

    esp_bluedroid_config_t bluedroid_cfg = BT_BLUEDROID_INIT_CONFIG_DEFAULT();
#if (CONFIG_EXAMPLE_SSP_ENABLED == false)
    bluedroid_cfg.ssp_en = false;
#endif
    if ((ret = esp_bluedroid_init_with_cfg(&bluedroid_cfg)) != ESP_OK)
    {
        ESP_LOGE(BT_AV_TAG, "%s initialize bluedroid failed: %s", __func__, esp_err_to_name(ret));
        return;
    }

    if (esp_bluedroid_enable() != ESP_OK)
    {
        ESP_LOGE(BT_AV_TAG, "%s enable bluedroid failed", __func__);
        return;
    }

#if (CONFIG_EXAMPLE_SSP_ENABLED == true)
    /* set default parameters for Secure Simple Pairing */
    esp_bt_sp_param_t param_type = ESP_BT_SP_IOCAP_MODE;
    esp_bt_io_cap_t iocap = ESP_BT_IO_CAP_IO;
    esp_bt_gap_set_security_param(param_type, &iocap, sizeof(uint8_t));
#endif

    /*
     * Set default parameters for Legacy Pairing
     * Use variable pin, input pin code when pairing
     */
    esp_bt_pin_type_t pin_type = ESP_BT_PIN_TYPE_VARIABLE;
    esp_bt_pin_code_t pin_code;
    esp_bt_gap_set_pin(pin_type, 0, pin_code);

    ESP_LOGI(BT_AV_TAG, "Own address:[%s]", bda2str((uint8_t *)esp_bt_dev_get_address(), bda_str, sizeof(bda_str)));
    bt_app_task_start_up();
    /* Bluetooth device name, connection mode and profile set up */
    bt_app_work_dispatch(bt_av_hdl_stack_evt, BT_APP_STACK_UP_EVT, NULL, 0, NULL, NULL);
}

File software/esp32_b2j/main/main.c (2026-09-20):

// Author : Paul Capgras
// Date   : Oct 6, 2025
// Bluetooth is pairing using Legacy Pairing

////////////
//  libc  //
////////////

// Standard Input Output
#include <stdio.h>

////////////////////////////
//   esp-idf framework    //
////////////////////////////

// to configure and control GPIO pins
#include "driver/gpio.h"

// Provides essential definitions for task management and delays
#include "freertos/FreeRTOS.h"

// Provide functions for task management and delays
#include "freertos/task.h"

#include <string.h>
#include "sdkconfig.h"
#include "esp_log.h"
#include "esp_console.h"
#include "esp_vfs_fat.h"
#include "esp_err.h"

// Bluetooth
#include "bt_app_core.h"
#include "bt_app_a2dp.h"

// Non volatile storage drivers
#include "nvs.h"
#include "nvs_flash.h"

// Include i2c
#include "driver/i2c_master.h"
#include "./drivers/cmd_i2ctools.h"

// Include audio codec
#include "./drivers/audio_codec.h"

// Include IO expander
#include "./drivers/io_expander.h"
#include "./drivers/utils.h"

#define CODEC_ADDR 0x18
#define CODEC_TAG "AUDIO_CODEC"

static gpio_num_t i2c_gpio_sda = 21;
static gpio_num_t i2c_gpio_scl = 19;

/*******************************
 * STATIC FUNCTION DEFINITIONS
 ******************************/

static void init_non_volatile_storage()
{
    /* initialize NVS (Non-volatile storage) — it is used to store PHY calibration data */
    esp_err_t err = nvs_flash_init();
    if (err == ESP_ERR_NVS_NO_FREE_PAGES || err == ESP_ERR_NVS_NEW_VERSION_FOUND)
    {
        ESP_ERROR_CHECK(nvs_flash_erase());
        err = nvs_flash_init();
    }
    ESP_ERROR_CHECK(err);
};

void app_main(void)
{
    printf("Hello world!\n");

    ///////////////////////
    //     Setup I2C     //
    ///////////////////////

    esp_console_repl_t *repl = NULL;
    esp_console_repl_config_t repl_config = ESP_CONSOLE_REPL_CONFIG_DEFAULT();

    esp_console_dev_uart_config_t uart_config = ESP_CONSOLE_DEV_UART_CONFIG_DEFAULT();
    ESP_ERROR_CHECK(esp_console_new_repl_uart(&uart_config, &repl_config, &repl));

    i2c_master_bus_config_t i2c_bus_config = {
        .clk_source = I2C_CLK_SRC_DEFAULT,
        .i2c_port = I2C_NUM_0,
        .scl_io_num = i2c_gpio_scl,
        .sda_io_num = i2c_gpio_sda,
        .glitch_ignore_cnt = 7,
        .flags.enable_internal_pullup = false,
    };

    ESP_ERROR_CHECK(i2c_new_master_bus(&i2c_bus_config, &tool_bus_handle));

    ///////////////////////
    //    IO Expander    //
    ///////////////////////

    reset_io_expander();
    i2c_detect();

    io_expander_init();

    set_io_expander(IO_EXPANDER_LED_ADC_MASK);
    set_io_expander(IO_EXPANDER_LED_DAC_MASK);

    ///////////////////////
    //    Audio Codec    //
    ///////////////////////

    // Codec reset uses I2C through the initialized IO expander.
    reset_audio_codec();
    i2c_detect();

    // Register 1 - SW reset
    i2c_set(CODEC_ADDR, 1, 0x80);

    /*
     * Clock
     */

    // Register 3 - PLL Programming Register A
    // D7   - 1    - PLL is enabled
    // D6-3 - 0000 - Q (ignored here)
    // D2-0 - 001  - P = 1
    i2c_set(CODEC_ADDR, 3, 0b10000001);
    is_expected(CODEC_TAG, 3, i2c_get(CODEC_ADDR, 3), 0b10000001);

    // Register 4 - PLL Programming Register B
    // D7-2 - 1000 00 - Set J to 32
    // D1-0 - 00      - Reserved
    i2c_set(CODEC_ADDR, 4, 0b10000000);
    is_expected(CODEC_TAG, 4, i2c_get(CODEC_ADDR, 4), 0b10000000);

    // Register 5 and 6
    // Set D to 0
    // MSB D7-0 (reg 5) 0
    // LSB D7-2 (reg 6) 0
    // D1-0             0
    // always write both, and in the order reg5 then reg6.
    is_expected(CODEC_TAG, 5, i2c_get(CODEC_ADDR, 5), 0b00000000);
    is_expected(CODEC_TAG, 6, i2c_get(CODEC_ADDR, 6), 0b00000000);

    // Register 11 - Audio Codec Overflow Flag Register
    // D7-4 - 0    - Ignore
    // D3-0 - 0001 - Set R to 1
    i2c_set(CODEC_ADDR, 11, 0b00000001);
    is_expected(CODEC_TAG, 11, i2c_get(CODEC_ADDR, 11), 0b00000001);

    // Register 101 - Clock register
    // D7-1 - 0
    // D0   - 0 - CODEC_CLKIN uses PLLDIV_OUT
    i2c_set(CODEC_ADDR, 101, 0b00000000);
    is_expected(CODEC_TAG, 101, i2c_get(CODEC_ADDR, 101), 0b00000000);

    // Register 102 - Clock Generation Control Register
    // D7-6 - 0    -
    // D5-4 - 10   - PLLCLK_IN uses BCLK
    // D3-0 - 0010 - Reserved
    i2c_set(CODEC_ADDR, 102, 0b00100010);
    is_expected(CODEC_TAG, 102, i2c_get(CODEC_ADDR, 102), 0b00100010);

    /*
     * Configure Codec
     */

    // Register 2 - default is good
    // Register 8 - default is good
    // Register 9 - default is good
    // Register 10 - default is good

    // Register 7 - Codec Data-Path Setup Register
    // D7   - 1  - Set fs=44.1kHz
    // D6-5 - 00
    // D4-3 - 01 - Left DAC plays left input data
    // D2-1 - 01 - Right DAC plays right input data
    // D0   - 0
    // 1000 1010
    i2c_set(CODEC_ADDR, 7, 0b10001010);
    // read again
    is_expected(CODEC_TAG, 7, i2c_get(CODEC_ADDR, 7), 0b10001010);

    /*
     * Configure Routing
     */

    // Register 41 - DAC Output Switching Control Register
    // D7-6 - 10 - Left DAC output selects DAC-L2 path to left high power output drivers
    // D5-4 - 10 - Right DAC output selects DAC-R2 path to right high power output drivers
    // D3-0 - 0000
    i2c_set(CODEC_ADDR, 41, 0b10100000);
    is_expected(CODEC_TAG, 41, i2c_get(CODEC_ADDR, 41), 0b10100000);

    // Register 47 - default is good
    // Register 64 - default is good

    /*
     * Configure the topology
     */

    // Register 14 - Headset/Button Press Detection Register B
    // D7   - 1 - Programs HPout for AC-coupled
    // D6-0 -   - ignore
    i2c_set(CODEC_ADDR, 14, 0b10000000);

    // Register 40 - default is good
    // Register 42 - default is good

    // Register 38 - Headset/Button Press Detection Register B
    // D7-6 - 00   - reserved
    // D5-3 - 010  - HPRCOM is configured as independent single-ended output
    // D2-1 - 00   - ignored
    // D0   - 0    - reserved
    i2c_set(CODEC_ADDR, 38, 0b00010000);
    is_expected(CODEC_TAG, 38, i2c_get(CODEC_ADDR, 38), 0b00010000);

    /*
     * Power the DAC
     */

    // Register 37 - DAC Power and Output Driver Control Register
    // D7   - 1 - Left DAC is powered up
    // D6   - 1 - Right DAC is powered up
    // D5-0 - 0
    // Write 1100 0000
    i2c_set(CODEC_ADDR, 37, 0b11000000);
    is_expected(CODEC_TAG, 37, i2c_get(CODEC_ADDR, 37), 0b11000000);

    /*
     * Power the headphone outputs
     * Keep the headphone muted
     */

    // Register 51 - HPLout output level control register
    // D7-4 - 0000
    // D3   - 0 - mute
    // D2   - 1
    // D1   - 1
    // D0   - 1 - Power up
    i2c_set(CODEC_ADDR, 51, 0b00000111);

    // Register 65 - HPRout output level control register
    // D7-4 - 0000
    // D3   - 0 - mute
    // D2   - 1
    // D1   - 1
    // D0   - 1 - Power up
    i2c_set(CODEC_ADDR, 65, 0b00000111);

    /*
     * Volume control
     */
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

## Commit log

2025-02-24 doc: add design specification and gerber files
    [jack2bluetooth-B_Cu.gbr, jack2bluetooth-B_Mask.gbr, jack2bluetooth-B_Paste.gbr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]
2025-11-10 feat: perform audio codec reset
    [main.c]
2025-11-10 refactor: move everything in esp32_c6 folder
2025-11-10 feat: setup classic bt audio_sink on the esp32 using internal DAC.
2025-11-10 feat/doc : create esp32_i2c folder and update doc with the history of last work
2025-11-10 refactor: remove esp32c6 folder as I have removed the esp32 from the board
2025-11-10 doc: add board and new pinout
2025-11-10 feat: create esp32_b2j platform
2025-11-10 feat: first stable platform with audio codec reset and bluetooth stack file. Bluetooth app not started yet.
    [audio_codec.c, cmd_i2ctools.c, main.c]
2025-11-10 feat: configure audio-codec, clean i2c drivers and add doc to audio codec programming
2025-11-10 feat: update audio codec PLL to have BCLK=5.6MHz. Fail because the oscilloscope still get 1.4MHz
    [main.c]
2025-11-15 chore: update gerber files
    [jack2bluetooth-B_Cu.gbr, jack2bluetooth-B_Mask.gbr, jack2bluetooth-B_Paste.gbr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]
2025-11-16 feat: add kicad folder with esp32 lib
    [ESP32-WROVER-E-N16R8.stp, jack2bluetooth.kicad_pcb, jack2bluetooth.kicad_sch]
2025-11-16 doc: update datasheets
    [SJ3-35063A.stp, TLV320AIC3101IRHBR.stp, jack2bluetooth.kicad_sch]
2025-11-16 feat: add lib diode
    [PMEG6020AELRX.stp]
2025-11-16 feat: add lib dip-switch
    [DS04-254-2-02BK-SMT.stp]
2025-11-16 feat: add lib jack2.5mm
    [SJ1-2503A.stp]
2025-11-16 feat: add ldo lib
    [TLV75801PDBVR.stp]
2025-11-16 feat: add pmic lib
    [BQ25619RTWR.stp]
2025-11-16 feat: add pmos lib
    [DMP3099L-13.stp]
2025-11-16 feat: add slide-switch lib
    [SLW-105558-2A-N-D.stp]
2025-11-16 feat: add voltage regulator lib
    [TPS62A01PDDCR.stp]
2025-11-17 feat: add io expander lib
    [MCP23008T-E_SO.stp]
2025-11-17 feat: add datasheets for esp32
2025-11-17 feat: add MCP eval board user guide
2025-11-17 refactor: remove unused lib (diode)
    [PMEG6020AELRX.stp]
2025-11-17 feat: update kicad schematic with rev3.1 updates
    [jack2bluetooth.kicad_sch]
2025-11-20 feat: add esp32 lyrat audio dev board schematic
2025-11-20 feat: update kicad schematic with latest Rev3.1 updates
    [jack2bluetooth.kicad_sch]
2025-11-20 doc: update design spec and export schematic rev3.1 in pdf
2025-11-22 feat: add test points to schematic
    [jack2bluetooth.kicad_sch]
2025-11-22 feat: update MCP23008 lib
    [MCP23008T-E_SO.stp]
2025-11-22 feat: add SMF5V0A lib
    [SMF5V0A-E3-08.stp]
2025-11-22 feat: remove warnings in ERC errors and warnings in schematic. refresh layout
    [jack2bluetooth.kicad_pcb, jack2bluetooth.kicad_sch]
2025-12-15 feat: finish layout placement
    [jack2bluetooth.kicad_pcb, jack2bluetooth.kicad_sch]
2025-12-15 feat: update placement and update pin assignments for easier routing
    [jack2bluetooth.kicad_pcb, jack2bluetooth.kicad_sch]
2025-12-15 feat: route power
    [jack2bluetooth.kicad_pcb, jack2bluetooth.kicad_sch]
2026-02-19 feat: routing done, silkscreen done
    [jack2bluetooth.kicad_pcb, jack2bluetooth.kicad_sch]
2026-02-19 feat: length tuning, custom footprints and update doc
    [jack2bluetooth.kicad_pcb]
2026-03-17 feat: generate gerber and bom
    [bom_rev3.1.xlsm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]
2026-08-30 feat: update gerber, bom and add datasheets
    [bom_rev3.1.xlsm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]
2026-08-31 feat: update script such that i2c works
2026-09-06 doc: fix scl sda pin mistake
2026-09-06 fix: fix i2c issues (pin sda and scl reversed)
    [main.c]
2026-09-06 chore: add .vscode for esp32_i2c folder
2026-09-06 feat: comment useless part about reseting audio codec
    [main.c]
2026-09-06 chore: create .vscode for esp32_b2j
2026-09-06 feat: save kicad schematic
2026-09-06 doc: add direction on pin expander section
2026-09-06 feat: reset audio codec with io expander and power two leds
    [main.c]
2026-09-06 refactor: move io_expander logic into a new driver
2026-09-06 doc: add an issues section to 3.1 to keep track of the PCB issues
2026-09-07 fix: fix sound breaking up by converting data to 32bit. (Slots and data must be equal.)
2026-09-07 refactor: delete old esp32_bluetooth_sink demo project
2026-09-13 fix: solve the AAC issue (sep registration was happening before a2dp initialization)
    [main.c]
2026-09-19 refactor: move files in driver folder
2026-09-19 refactor: extract a2dp logic into ad2p source driver
2026-09-19 feat: init i2c, init io expander, init audiocodec
2026-09-19 feat: - Converts received 32-bit words to signed 16-bit PCM, preserving stereo order. - Processes only returned samples, including partial reads on timeout. - Allocates buffers on the heap to avoid s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
    [i2s.c]
2026-09-20 feat: clone esp32_j2b to jack2bluetooth to prepare for SW integration
2026-09-20 refactor: remove useless i2c_detect and comments
2026-09-20 refactor: move audio codec logic into audio_codec driver. Remove utils file by moving is_expected function into i2c driver. Rename i2c driver
2026-09-20 doc: add battery datasheet
2026-09-20 feat: enable io expander interrupt
2026-09-20 feat: task to handle io_expander interrupt
2026-09-20 feat: filter out button pull to only keep button push
2026-09-20 refactor: extract button logic into button fonctions
2026-09-20 refactor: move i2c init
2026-09-21 feat/fix: add is_direction function into io_expander. Load b2j configuration when enabled. Fix bug : bt_app_register_a2dp_src_seps not called
    [io_expander.c, main.c]
2026-09-21 feat: integrate first version of a2dp sink (not working yet because of external codec parameter)
    [bt_app_a2dp_sink.h, i2s.c, main.c]
2026-09-21 fix: solver external codec issue for a2dp sink with codex
    [i2s.c, i2s.h]
2026-09-26 refactor: move audio codec configuration in sink into audio codec driver
2026-09-26 feat: disconnect j2b when switching to b2j. Assuming there is a connection
2026-09-27 doc: improve sw flow
2026-09-27 feat: mute adc with enter button
2026-09-27 feat: add a high pass filter
2026-10-03 feat(AI): manually write "Paul" on the i2c screen
2026-10-05 fix: solve i2c not working after reset because the i2c screen was powered through I2C and therefore not reset
2026-10-05 fix: solve i2c used by multiple task issue
2026-10-05 feat: power led according to the selected mode
2026-10-05 feat: add connected device name and solve malloc failling of ringbuffer
2026-10-05 feat(AI): add the option to list device on the screen
2026-10-10 doc: add a new battery datasheet
2026-10-10 feat(AI): Replace the current single target-device logic with a fixed-size discovered-device list. Store address, name, RSSI, and validity state. Deduplicate by Bluetooth address. Publish device_list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
2026-10-10 feat(AI): add Device-picker UI - Add ui_device_picker. - It reads the GAP list and shows device names through ssd1306_show_string_list(). - It owns the selected index and keeps it valid if discovery 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
2026-10-10 feat(AI): connect to selected device - Wire Enter to the existing A2DP-source connection path. - Stop discovery when a device is selected. - Show Connecting to…, then connected, failed, or disconnect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
2026-10-11 feat: update update 3D models (pcb)
2026-10-25 feat: add ssh1106 for the new i2c screen
2026-10-25 feat: move the screen pins to SDA and SCL from SPI. Introduce a new I2C
2026-10-31 reactor: remove print and memory debug files
